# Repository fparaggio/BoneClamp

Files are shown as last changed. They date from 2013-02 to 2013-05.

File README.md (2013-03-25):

-------------------------------------------------------------------------

This file is part of the BoneClamp Data Conversion and Processing System
Copyright (C) 2013 BoneClamp

-------------------------------------------------------------------------

# BoneClamp
BoneClamp is an effort to create a fully programable, real-time, low-cost, data conversion and processing system for the 
[BeagleBone] (http://beagleboard.org/bone).

# More information
[BoneClamp Wiki] (https://potterlab.gatech.edu/main/newman/wiki/index.php?title=BoneClamp)

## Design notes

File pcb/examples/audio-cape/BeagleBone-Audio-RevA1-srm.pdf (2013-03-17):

BeagleBone Audio Cape | System Reference Manual | Revision A1

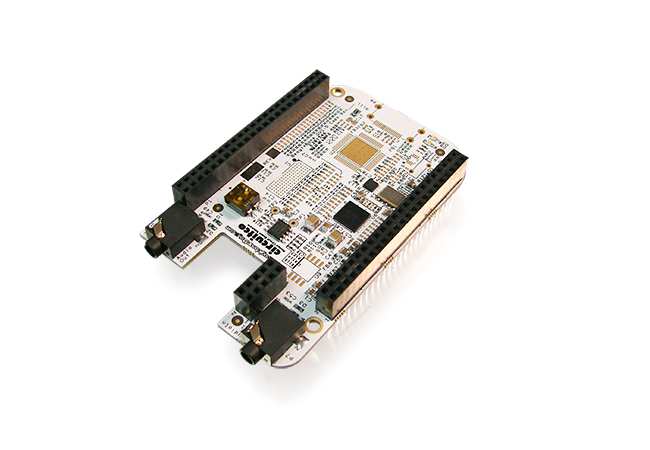
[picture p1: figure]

Page 1 of 24

## BeagleBone Audio Cape Rev A1 System Reference Manual

Revision A1
October 1st, 2012

Page 2 of 24

THIS DOCUMENT

This work is licensed under the Creative Commons Attribution-Share Alike 3.0 Unported License. To view a copy of this license, visit http://creativecommons.org/licenses/by-sa/3.0/ or send a letter to Creative Commons, 171 Second Street, Suite 300, San Francisco, California, 94105, USA.

All derivative works are to be attributed to BeagleBoardtoys.com.

For more information, see http://creativecommons.org/license/results-one?license_code=by-sa

For any questions, concerns, or issues submit them to support@beagleboardtoys.com

## BEAGLEBONE AUDIO CAPE DESIGN

## These design materials referred to in this document are *NOT SUPPORTED* and DO NOT constitute a reference design. Only “community” support is allowed via resources at Beagleboardtoys.com/support

## THERE IS NO WARRANTY FOR THE DESIGN MATERIALS, TO THE EXTENT PERMITTED BY APPLICABLE LAW. EXCEPT WHEN OTHERWISE STATED IN WRITING THE COPYRIGHT HOLDERS AND/OR OTHER PARTIES PROVIDE THE DESIGN MATERIALS “AS IS” WITHOUT WARRANTY OF

ANY KIND, EITHER EXPRESSED OR IMPLIED,

## INCLUDING, BUT NOT LIMITED TO, THE IMPLIED

WARRANTIES | OF | MERCHANTABILITY | AND

Page 3 of 24

## FITNESS FOR A PARTICULAR PURPOSE. THE ENTIRE RISK AS TO THE QUALITY AND PERFORMANCE OF THE DESIGN MATERIALS IS WITH YOU. SHOULD THE DESIGN MATERIALS PROVE DEFECTIVE, YOU ASSUME THE COST OF

ALL | NECESSARY | SERVICING, | REPAIR | OR
CORRECTION.

## We mean it; these design materials may be totally

unsuitable for any purposes.

Page 4 of 24

BeagleBoardToys provides the enclosed product(s) under the following conditions:

This evaluation board/kit is intended for use for ENGINEERING DEVELOPMENT, DEMONSTRATION, OR EVALUATION PURPOSES ONLY and is not considered by BeagleBoardtoys.com to be a finished end-product fit for general consumer use. Persons handling the product(s) must have electronics training and observe good engineering practice standards. As such, the goods being provided are not intended to be complete in terms of required design-, marketing-, and/or manufacturing-related protective considerations, including product safety and environmental measures typically found in end products that incorporate such semiconductor components or circuit boards. This evaluation board/kit does not fall within the scope of the European Union directives regarding electromagnetic compatibility, restricted substances (RoHS), recycling (WEEE), FCC, CE or UL, and therefore may not meet the technical requirements of these directives or other related directives.

Should this evaluation board/kit not meet the specifications indicated in the User’s Guide, the board/kit may be returned within 30 days from the date of delivery for a full refund. THE FOREGOING WARRANTY IS THE EXCLUSIVE WARRANTY MADE BY SELLER TO BUYER AND IS IN LIEU OF ALL OTHER WARRANTIES, EXPRESSED, IMPLIED, OR STATUTORY, INCLUDING ANY WARRANTY OF MERCHANTABILITY OR FITNESS FOR ANY PARTICULAR PURPOSE.

The user assumes all responsibility and liability for proper and safe handling of the goods. Further, the user indemnifies BeagleBoardtoys.com from all claims arising from the handling or use of the goods. Due to the open construction of the product, it is the user’s responsibility to take any and all appropriate precautions with regard to electrostatic discharge.

EXCEPT TO THE EXTENT OF THE INDEMNITY SET FORTH ABOVE, NEITHER PARTY SHALL BE LIABLE TO THE OTHER FOR ANY INDIRECT, SPECIAL, INCIDENTAL, OR CONSEQUENTIAL DAMAGES.

BeagleBoardtoys.com currently deals with a variety of customers for products, and therefore our arrangement with the user is not exclusive. BeagleBoardtoys.com assumes no liability for applications assistance, customer product design, software performance, or infringement of patents or services described herein.

Please read the User’s Guide and, specifically, the Warnings and Restrictions notice in the User’s Guide prior to handling the product. This notice contains important safety information about temperatures and voltages. For additional information on BeagleBoardtoys.com environmental and/or safety programs, please contact visit BeagleBoardtoys.com.

No license is granted under any patent right or other intellectual property right of BeagleBoard.org covering or relating to any machine, process, or combination in which such BeagleBoardtoys.com products or services might be or are used.

Mailing Address:

Beagleboardtoys.com
1380 Presidential Dr. #100 Richardson, TX 75081
U.S.A.

Page 5 of 24

WARRANTY: The BeagleBone Audio is warranted against defects in materials and workmanship for a period of 90 days from purchase. This warranty does not cover any problems occurring as a result of improper use, modifications, exposure to water, excessive voltages, abuse, or accidents. All boards will be returned via standard mail if an issue is found. If no issue is found or express return is needed, the customer will pay all shipping costs.

Before returning the board, please visit Beagleboardtoys.com/support

To return a defective board, please request an RMA at http://www.beagleboardtoys.com/support/rma

Page 6 of 24

## Table of Contents

Page 7 of 24

## Figures

Figure 1. | The BeagleBone Audio Cape | 11
Figure 2. | Major Components | 14
Figure 3. | BeagleBone Audio Cape High Level Block Diagram | 16
Figure 4. | The Record Path of TLV320AIC3106 | 17
Figure 5. | The Playback Path of TLV320AIC3106 | 18
Figure 6. | Audio Serial Bus Interface | 19
Figure 7. | BeagleBone Audio Cape EEPROM | 20
Figure 8. | User LED’s | 21
Figure 9. | BeagleBone Audio Cape Dimensions Drawing | 23

## Tables

Table 1. | Change History | 10
Table 2. | BeagleBone Audio Cape Features | 13
Table 3. | User LED Control | 22

Page 8 of 24

NOTES

Page 9 of 24

### 1.0 Introduction

This document is the System Reference Manual for the BeagleBone Audio Cape, an add-on board for the BeagleBone.

This document provides detailed information on the overall design and usage of the BeagleBone Audio Cape from the system level perspective. It is not intended to provide detailed documentation of any other component used on the board. It is expected that the user will refer to the appropriate documents for these devices to access detailed information. It will provide information on how to interact with these components from an interface perspective. The perspective will be general in nature and not specific to any one board.

The key sections in this document are:

Section 2.0 – Change History
Provides tracking for the changes made to the System Reference Manual.

Section 3.0 – Overview
This is a high level overview of the BeagleBone Audio Cape.

Section 4.0 – Features and Specification
Provided here are the features and specifications of the board.

Section 5.0 – System Architecture and Design
This section provides information on the overall architecture and design of the BeagleBone Audio Cape. This is a very detailed section that goes into the design of each circuit on the board.

Section 6.0 – Mechanical
Information is provided here on the dimensions of the BeagleBone Audio Cape.

Section 7.0 – Design Materials
This section provides information on where to get the design files.

Page 10 of 24

### 2.0 Change History

### 2.1 Change History

Table 1 tracks the changes made for each revision of this document.

Table 1. | Change History
Rev | Changes | Date | By
A | Initial release. | 08/20/2011 | BBT
A1 | 1. Add Rev A vs. A1 section (2.2) | 10/01/2012 | BBT

### 2.2 Rev A vs. A1

The only changes in this revision are PCB silkscreens to accommodate the release of Audio Cape and DVI-D with Audio Cape. No design changes have been made for the BeagleBone Audio revision A1.

The PCB revision is also changed from BB-BONE-DVID-PCB-03 to BB-BONE-DVID-PCB -04.

Page 11 of 24

### 3.0 BeagleBone Audio Cape Overview

### 3.1 Descriptions

The BeagleBone Audio Cape provides stereo audio input and output for the BeagleBone by using the TLV320AIC3106 codec. Audio data is sampled at up to 96 kHz during recording or playback. The codec interfaces with the Multichannel Audio Serial Port of the AM335x via audio serial bus. The BeagleBone Audio Cape also features two standard 3.5mm audio jacks as audio input and output connectors.

Figure 1 below is a picture of the board.

Figure 1. The BeagleBone Audio Cape

### 3.2 Box Content

The final packaged BeagleBone Audio Cape Rev A1 product will contain the following items:
- 1 BeagleBone Audio Cape

Page 12 of 24

### 3.3 Getting Started

The BeagleBone Audio Cape should work right out of the box with latest Angstrom image for BeagleBone. Following the instructions below to verify the board is working:

1. Mount the BeagleBone Audio Cape on top of BeagleBone.
- Note: The Ethernet connector on BeagleBone should fit right into the cutback on BeagleBone Audio.
2. Make sure the micro SD card using with BeagleBone has latest Angstrom image.
3. Connect the audio input jack of speakers to the audio output connector on the BeagleBone Audio.
4. Connect the audio output from PC to the audio input connector on the BeagleBone Audio using a 3.5mm male to male audio cable.
5. Open a media player on PC and play an audio file repeatedly.
6. Connect the BeagleBone to PC using a USB cable. Remember the port number of this connection.
- Note: In Windows, the serial port number can be viewed under “Ports (COM & LPT)” section inside “Device Manager”. To open the “Device Manager” windows, right-click “My Computer”, choose “Properties”, select the “Hardware” tab, and click “Device Manager”.
7. Open a terminal application (Teraterm, Hyperterminal, etc) and open new connection with following settings: baud rate - 115200, data – 8 bit, parity – none, stop – 1 bit, flow control – none. Select the port corresponding to the USB connection. Log in as root.
8. Change the ALSA mixer settings by running the command "alsamixer.
9. Start the audio test script by running the command "testaudio".
10. The script will test the audio playback by playing a beep sound to speakers.
11. The script will record 1 second of the currently playing audio file on PC and play it back to speakers.

### 3.4 Repairs

If you feel the board is in need of repair, follow the RMA Request process found at http://www.beagleboardtoys.com/support/rma

# Do not send the board in for repair until a RMA

authorization has been provided.

Do not return the board to the distributor unless you want to get a refund. You must get authorization from the distributor before returning the board

Page 13 of 24

### 4.0 Features and Specifications

This section covers the specifications of the BeagleBone Audio Cape and provides a high level description of the major components and interfaces that make up the board.

Table 2 provides a list of the BeagleBone Audio Cape’s features.

Table 2. | BeagleBone Audio Cape Features
| Feature
Power Supply | 3.3V via expansion
5V via expansion
Audio Connector | 3.5mm standard stereo jack
Indicator | Two user LEDs
EEPROM | Board ID EEPROM
Expansion Connector | 46-position stackable connector
10-position stackable connector

### 4.1 Key Component Locations

Figure 2 shows the location of the key components on the board.

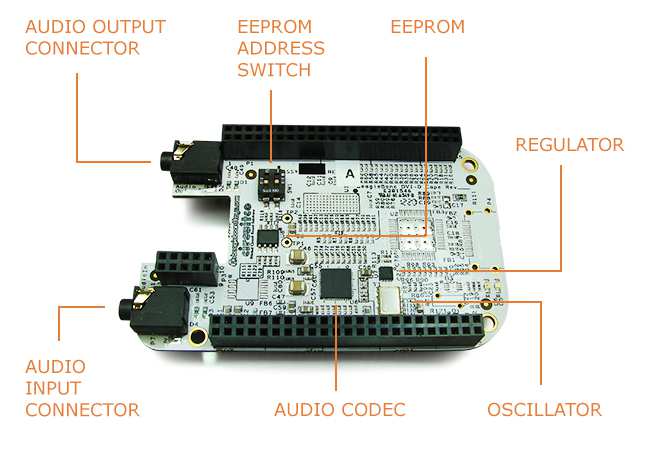
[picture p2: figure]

Page 14 of 24

Figure 2. Major Components

### 4.2 Audio Codec

The BeagleBone Audio Cape uses the TLV320AIC3106 codec for audio record and playback. Audio data is transferred between the codec and AM335x via the audio serial interface. The TLV320AIC3106 supports ADC and DAC sampling rates of up to 96 kHz.

### 4.3 Stereo Audio Ports

Two 3.5mm standard audio jacks are used for audio input port and output port. Audio input port is used for recording; audio output port is used for playback.

### 4.4 Indicators

There are two user LED’s on the board. Both are green when lit and can be controlled via software by setting the GPIO ports.

Page 15 of 24

### 4.5 Expansion Connectors

There are three stackable expansion connectors on the BeagleBone Audio Cape. These connectors are used to stack the Audio Cape on the BeagleBone. Two 46-position connectors will stack on top of the expansion connectors of BeagleBone. The 10-position connector will stack on top of the backlight expansion connector of BeagleBone.

### 4.6 Mechanical Specifications

Size: | 2.15” x 3.40”
Layers: | 4
PCB thickness: | .062”
RoHS Compliant: | Yes
Weight: | TBW

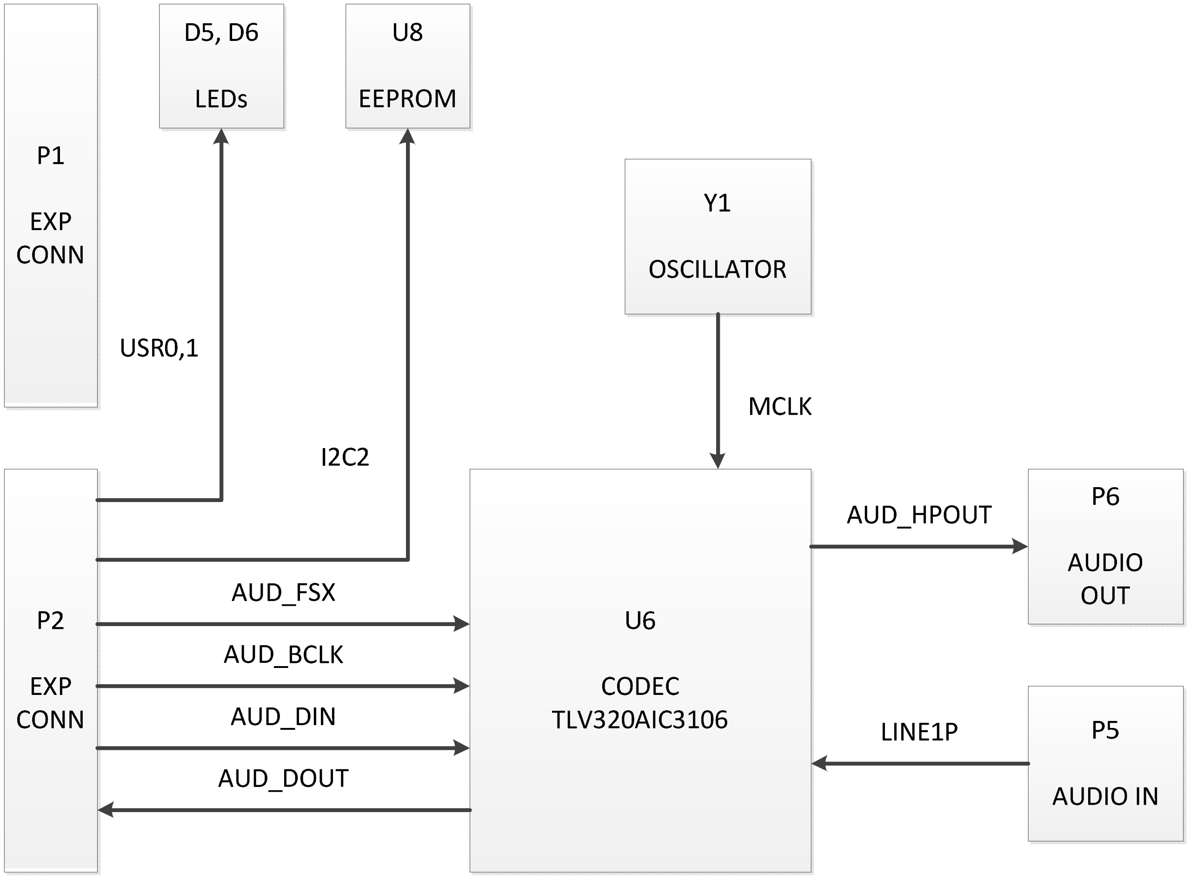
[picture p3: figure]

Page 16 of 24

### 5.0 BeagleBone Audio Cape System Architecture and Design

This section provides a high level description of the design of the BeagleBone Audio Cape and its overall architecture.

### 5.1 System Block Diagram

Figure 3 is the high level block diagram of the BeagleBone Audio Cape.

Figure 3. BeagleBone Audio Cape High Level Block Diagram

### 5.2 Power Supply

The VDD_3V3 power rail from the BeagleBone is used to power the analog and I/O voltage supplies for the codec. The TLV320AIC3106 codec also requires a digital core voltage supply of 1.8V. This supply is provided by a low-dropout (LDO) regulator TPS73701.

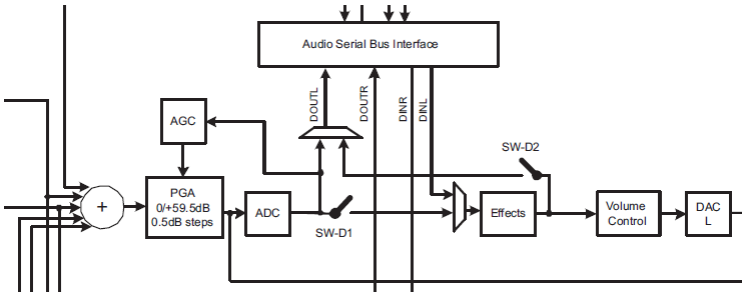
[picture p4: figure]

Page 17 of 24

### 5.3 Audio Interface

### 5.3.1 Record Path

The TLV320AIC3106 codec can be figured to record from up to four differential pairs or six single-ended audio inputs; however, the BeagleBone Audio Cape only supports two single-ended audio inputs. Each input is passed through a programmable gain amplifier (PGA), which allows gain control from 0 dB to +59.5 dB in steps of 0.5 dB, before sampled by the ADC. The ADC can sample up to 96 kHz in dual-rate mode. An automatic gain control (AGC) is provided to maintain nominally constant output signal amplitude. Figure 4 shows the record path of TLV320AIC3106.

Figure 4. The Record Path of TLV320AIC3106

The codec also supports digital audio processing for the record path if no audio playback is selected. In this mode the signal processing blocks of the playback path can be used to provide different filters for the record path.

### 5.3.2 Playback Path

The playback audio signals of each channel are filtered through digital audio processing blocks and a digital volume control before sampled by the DAC. The volume control block is programmable and can provide a digital gain from 0 dB to -63.5 dB in 0.5-dB steps. The DAC of the codec supports sampling rates of up to 96 kHz. The TLV320AIC3106 codec supports up to three differential output drivers and four high power single-ended output signals; however, the board design limits to only two single-ended output signals. The output stage of the codec provides the capability to mix/mux

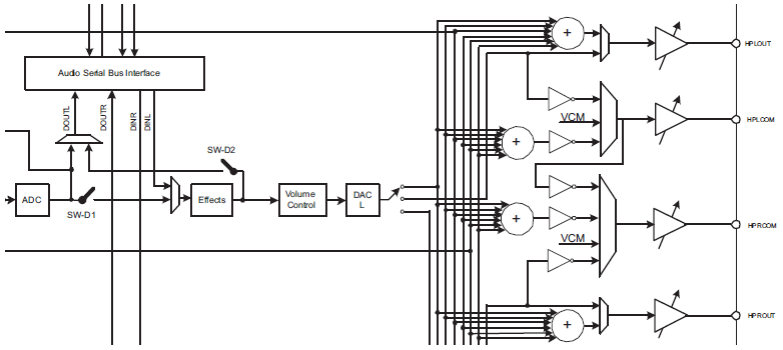
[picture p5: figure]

Page 18 of 24

between DAC and bypass PGA outputs as well as an output level control for each output channel. If no mixings are required, an output playback signals with highest DAC quality can be provided by using a direct connection for DAC outputs. The analog volume control allows gain adjustment up to +9 dB. Figure 5 shows the playback path of TLV320AIC3106.

Figure 5. The Playback Path of TLV320AIC3106

### 5.3.3 Audio Serial Bus Interface

Audio data is transferred between the TLV320AIC3106 and the Multichannel Audio Serial Port (McASP0) of the AM335x via the audio serial bus interface. This interface can be configured to support different modes of operation including the Inter-Integrated sound (I2S) protocols or time-division multiplexed (TDM) stream. Each data frame is synchronized by the transmit frame sync signal (AUD_FSX) from the McASP. This signal is connected to the word clock pin (WCLK), which is used to define the start of a frame. The digital audio data transfer is clocked by a bit clock (BCLK) received from the AM335x. Data is transmitted or received by the McASP serializers. Figure 6 shows the Audio Serial Bus Interface between the codec and the microprocessor.

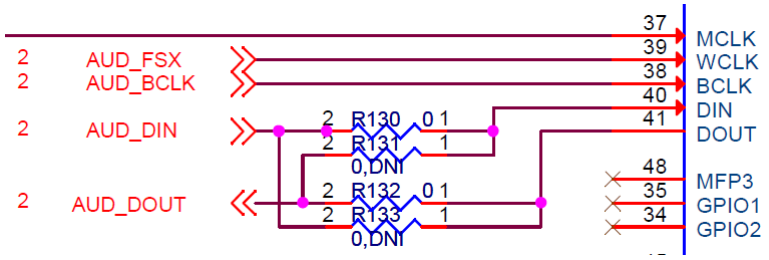
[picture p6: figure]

Page 19 of 24

Figure 6. Audio Serial Bus Interface

### 5.3.4 TLV320AIC3106 Codec

The TLV320AIC3106 codec requires a hardware reset after power-up in order to respond properly to register changes in values. Its reset signal is active low and tied to the system reset signal SYS_RESETn. The TLV320AIC3106 on the BeagleBone Audio Cape is digitally controlled via I2C serial interface. This I2C protocol supports both standard and fast modes and has a 7-bit address of 0011011. An external oscillator is used to provide a 12MHz clock signal to the master clock input (MCLK) of the codec.

### 5.4 EEPROM

The BeagleBone Audio Cape has an EEPROM containing information that will allow the SW to identify the board and to configure the expansion headers pins as needed.
EEPROMs are required for all Capes sold in order for them to operate correctly when plugged in the BeagleBone.

The EEPROM used on this cape is the same one as is used on the BeagleBone, a CAT24C256. The CAT24C256 is a 256 kb Serial CMOS EEPROM, internally organized as 32,768 words of 8 bits each. It features a 64-byte page write buffer and supports the Standard (100 kHz), Fast (400 kHz) and Fast-Plus (1 MHz) I2C protocol. Figure 7 is the design of the EEPROM circuit.

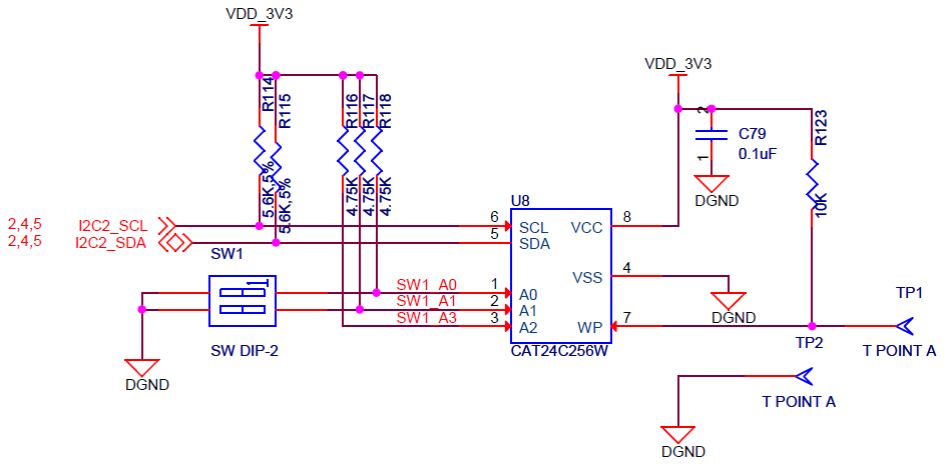
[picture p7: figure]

Page 20 of 24

Figure 7. BeagleBone Audio Cape EEPROM

### 5.4.1 EEPROM Address

In order for each Cape to have a unique address, a board ID scheme is used that sets the address to be different depending on the order in which it is stacked onto the main board. A two position dipswitch or jumpers is used to set the address pins of the EEPROM. It is the responsibility of user to set the proper address for each board. Address line A2 is always tied high. This sets the allowable address range for the expansion cards to 0x54 to 0x57.All other I2C addresses can be used by the user in the design of their Capes. But, these addresses must not be used other than for the board EEPROM information.

### 5.4.2 I2C Bus

The EEPROMs on each expansion board is connected to I2C2. For this reason I2C2 must always be left connected and should not be changed by SW to remove it from the expansion header pin mux. The I2C signals require pull-up resistors. Each board must have a 5.6K resistor on these signals. With four resistors this will be an affective resistance of 1.4K if all Capes were installed.

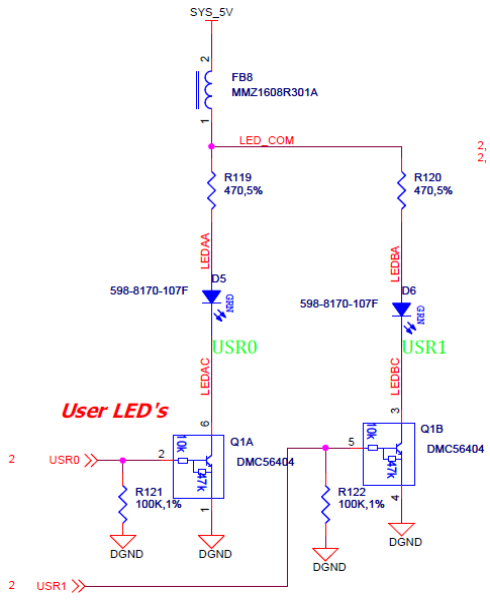
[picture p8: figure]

Page 21 of 24

### 5.5 User LED’s

The BeagleBone Audio Cape features two user LED’s which are same as D2 and D3 on the BeagleBone boards. These two LED’s can be access via GPIO pins on the processor. Figure 8 shows the LED circuitry.

Figure 8. User LED’s

Q1 provides level shifting from the processor to drive the LED’s that are connected to SYS_5V rail. FB8 provides noise immunity to the system by the LED’s which can be a

Page 22 of 24

source of noise back into the system rail. Each LED is controlled by settings the appropriate GPIO bit HI. At power up all LED’s are off. Table 3 is the GPIO User LED assignments.

Table 3. | User LED Control
LED | GPIO
User 0 | GPIO1_21
User 1 | GPIO1_22

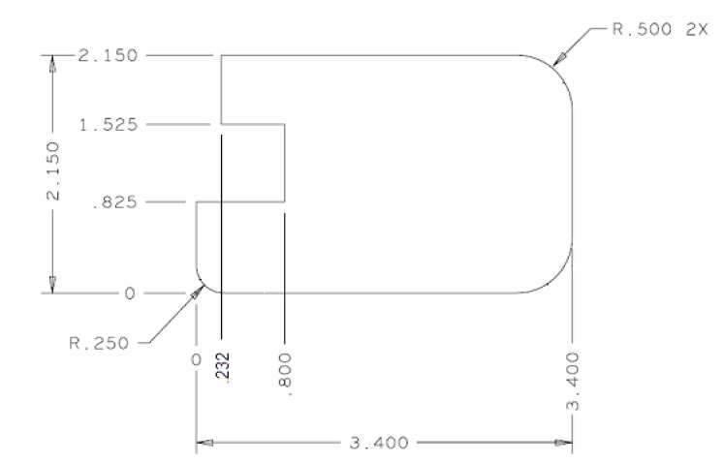
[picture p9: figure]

Page 23 of 24

### 6.0 Mechanical Information

### 6.1 BeagleBone Audio Cape Dimensions

This section provides information on the mechanical aspect of the BeagleBone Audio Cape. Figure 9 is the dimensions of the BeagleBone Audio Cape.

Figure 9. BeagleBone Audio Cape Dimensions Drawing

Page 24 of 24

### 7.0 Design Materials

Design information can be found at BeagleBoardToys wiki: http://beagleboardtoys.com/wiki/index.php?title=BeagleBone_Audio

Provided there is:
- Schematic in PDF
- Schematic in OrCAD
- Manufacturing files
- PCB Gerber
- PCB Layout (Allegro)
- Bill of Materials
- System Reference Manual (This document)

These design materials are *NOT SUPPORTED* and DO NOT constitute a reference design. Only “community” support is allowed via resources at BeagleBoard.org/discuss. THERE IS NO WARRANTY FOR THE DESIGN MATERIALS, TO THE EXTENT PERMITTED BY APPLICABLE LAW. EXCEPT WHEN OTHERWISE STATED IN WRITING THE COPYRIGHT HOLDERS AND/OR OTHER PARTIES PROVIDE THE DESIGN MATERIALS “AS IS” WITHOUT WARRANTY OF ANY KIND, EITHER EXPRESSED OR IMPLIED, INCLUDING, BUT NOT LIMITED TO, THE IMPLIED WARRANTIES OF MERCHANTABILITY AND FITNESS FOR A PARTICULAR PURPOSE. THE ENTIRE RISK AS TO THE QUALITY AND PERFORMANCE OF THE DESIGN MATERIALS IS WITH YOU. SHOULD THE DESIGN MATERIALS PROVE DEFECTIVE, YOU ASSUME THE COST OF ALL NECESSARY SERVICING, REPAIR OR CORRECTION.
We mean it, these design materials may be totally unsuitable for any purposes.

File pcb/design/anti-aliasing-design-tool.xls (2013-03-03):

 |  |  |  | Anti-Aliasing Filter Tool
Enter Converter Resolution: | 16 | bits
Enter Sample Rate: | 250000 | Hz
Nyquist Frequency: | 125000 | Hz
Enter Signal Bandwidth: | 20000 | Hz
Required Attenuation: | -98.08 | dB
Number of Filter Poles: | 4
Freq Factor | Frequency | Gain | Required Attenuation
0.0009765625 | 19.53125 | 0 | -98.08
0.001953125 | 39.0625 | 0 | -98.08
0.00390625 | 78.125 | 0 | -98.08
0.0078125 | 156.25 | 0 | -98.08
0.015625 | 312.5 | 0 | -98.08
0.03125 | 625 | 0 | -98.08
0.0625 | 1250 | 0 | -98.08
0.125 | 2500 | 0 | -98.08
0.25 | 5000 | 0 | -98.08
0.5 | 10000 | 0 | -98.08
1 | 20000 | 0 | -98.08
2 | 40000 | -24 | -98.08
4 | 80000 | -48 | -98.08
8 | 160000 | -72 | -98.08
16 | 320000 | -96 | -98.08
32 | 640000 | -120 | -98.08
64 | 1280000 | -144 | -98.08
128 | 2560000 | -168 | -98.08
256 | 5120000 | -192 | -98.08
512 | 10240000 | -216 | -98.08
1024 | 20480000 | -240 | -98.08
 | 250019.5312 | 0 | -98.08
 | 250039.0625 | 0 | -98.08
 | 250078.125 | 0 | -98.08
 | 250156.25 | 0 | -98.08
 | 250312.5 | 0 | -98.08
 | 250625 | 0 | -98.08
 | 251250 | 0 | -98.08
 | 252500 | 0 | -98.08
 | 255000 | 0 | -98.08
 | 260000 | 0 | -98.08
 | 270000 | 0 | -98.08
 | 290000 | -24 | -98.08
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

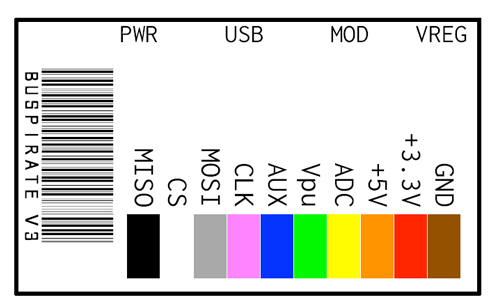
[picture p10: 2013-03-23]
pcb/proto/bus-pirate/Seed-cable.png

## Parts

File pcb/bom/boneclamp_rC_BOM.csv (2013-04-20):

Part | Value | Device | Package | Description | MPN | DKN |  |  | Manu
ADDRESS | SWS003 | SWS003 | SMS-003 | SMD Dip Switch 3 pol. | 219-3LPST | CT2193LPST-ND
A_I/O | PINHD-2X5/90 | PINHD-2X5/90 | 2X05/90 | 2X5 0.1 inch male header | 68021-210HLF | 609-3410-ND
C1 | 0.1uF | C-EUC0603 | C0603 | CAPACITOR, European symbol | C1608X7R1E104K080AA | 445-1316-1-ND
C2 | 0.1uF | C-EUC0603 | C0603 | CAPACITOR, European symbol | C1608X7R1E104K080AA | 445-1316-1-ND
C3 | 0.1uF | C-EUC0603 | C0603 | CAPACITOR, European symbol | C1608X7R1E104K080AA | 445-1316-1-ND
C4 | 0.1uF | C-EUC0603 | C0603 | CAPACITOR, European symbol | C1608X7R1E104K080AA | 445-1316-1-ND
C5 | 0.1uF | C-EUC0603 | C0603 | CAPACITOR, European symbol | C1608X7R1E104K080AA | 445-1316-1-ND
C6 | 0.1uF | C-EUC0603 | C0603 | CAPACITOR, European symbol | C1608X7R1E104K080AA | 445-1316-1-ND
C7 | 0.1uF | C-EUC0603 | C0603 | CAPACITOR, European symbol | C1608X7R1E104K080AA | 445-1316-1-ND
C8 | 0.1uF | C-EUC0603 | C0603 | CAPACITOR, European symbol | C1608X7R1E104K080AA | 445-1316-1-ND
C9 | 4.7uF | C-EUC0805 | C0805 | CAPACITOR, European symbol | TMK212AB7475KG-T | 587-2990-1-ND
C10 | 4.7uF | C-EUC0805 | C0805 | CAPACITOR, European symbol | TMK212AB7475KG-T | 587-2990-1-ND
C11 | 1nF | C-EUC0603 | C0603 | CAPACITOR, European symbol | C0603C102K3RACTU | 399-7834-1-ND
C12 | 1nF | C-EUC0603 | C0603 | CAPACITOR, European symbol | C0603C102K3RACTU | 399-7834-1-ND
C13 | 1nF | C-EUC0603 | C0603 | CAPACITOR, European symbol | C0603C102K3RACTU | 399-7834-1-ND
C14 | 1nF | C-EUC0603 | C0603 | CAPACITOR, European symbol | C0603C102K3RACTU | 399-7834-1-ND
C15 | 22uF | C-EUC0603 | C0603 | CAPACITOR, European symbol | C2012X5R1A226M125AB | 445-7665-1-ND
C16 | 0.1uF | C-EUC0603 | C0603 | CAPACITOR, European symbol | C1608X7R1E104K080AA | 445-1316-1-ND
C17 | 0.1uF | C-EUC0603 | C0603 | CAPACITOR, European symbol | C1608X7R1E104K080AA | 445-1316-1-ND
C18 | 0.1uF | C-EUC0603 | C0603 | CAPACITOR, European symbol | C1608X7R1E104K080AA | 445-1316-1-ND
C19 | 0.1uF | C-EUC0603 | C0603 | CAPACITOR, European symbol | C1608X7R1E104K080AA | 445-1316-1-ND
C20 | 0.1uF | C-EUC0603 | C0603 | CAPACITOR, European symbol | C1608X7R1E104K080AA | 445-1316-1-ND
C21 | 0.1uF | C-EUC0603 | C0603 | CAPACITOR, European symbol | C1608X7R1E104K080AA | 445-1316-1-ND
C22 | 0.1uF | C-EUC0603 | C0603 | CAPACITOR, European symbol | C1608X7R1E104K080AA | 445-1316-1-ND
C23 | 0.1uF | C-EUC0603 | C0603 | CAPACITOR, European symbol | C1608X7R1E104K080AA | 445-1316-1-ND
C24 | 0.1uF | C-EUC0603 | C0603 | CAPACITOR, European symbol | C1608X7R1E104K080AA | 445-1316-1-ND
C25 |  | C-EUC0603 | C0603 | CAPACITOR, European symbol
C26 | 10uF | C-USC0805 | C0805 | CAPACITOR, American symbol | TAJP106M010RNJ | 478-3281-1-ND
C27 | 0.1uF | C-EUC0603 | C0603 | CAPACITOR, European symbol | C1608X7R1E104K080AA | 445-1316-1-ND
C28 | 0.1uF | C-EUC0603 | C0603 | CAPACITOR, European symbol | C1608X7R1E104K080AA | 445-1316-1-ND
C29 |  | C-EUC0603 | C0603 | CAPACITOR, European symbol
C30 |  | C-EUC0603 | C0603 | CAPACITOR, European symbol
C31 |  | C-EUC0603 | C0603 | CAPACITOR, European symbol
C32 | 47uF | C-USC1206 | C1206 | CAPACITOR, American symbol | T520A476M004ATE070 | 399-4714-1-ND
C33 | 47uF | C-USC1206 | C1206 | CAPACITOR, American symbol | T520A476M004ATE070 | 399-4714-1-ND
C34 | 1uF | C-EUC0603 | C0603 | CAPACITOR, European symbol | C0805C105K4RACTU | 399-1284-1-ND
C35 | 1uF | C-EUC0603 | C0603 | CAPACITOR, European symbol | C0805C105K4RACTU | 399-1284-1-ND
C36 | 1uF | C-EUC0603 | C0603 | CAPACITOR, European symbol | C0805C105K4RACTU | 399-1284-1-ND
C37 | 1uF | C-EUC0603 | C0603 | CAPACITOR, European symbol | C0805C105K4RACTU | 399-1284-1-ND
C38 | 4.7uF | C-EUC0603 | C1206 | CAPACITOR, European symbol | TR3A475K010C1400 | 718-1757-1-ND
C39 | 1uF | C-EUC0603 | C0603 | CAPACITOR, European symbol | C0805C105K4RACTU | 399-1284-1-ND
C40 | 1uF | C-EUC0603 | C0603 | CAPACITOR, European symbol | C0805C105K4RACTU | 399-1284-1-ND
C41 | 0.1uF | C-EUC0603 | C0603 | CAPACITOR, European symbol | C1608X7R1E104K080AA | 445-1316-1-ND
C42 | 0.1uF | C-EUC0603 | C0603 | CAPACITOR, European symbol | C1608X7R1E104K080AA | 445-1316-1-ND
C43 | 0.1uF | C-EUC0603 | C0603 | CAPACITOR, European symbol | C1608X7R1E104K080AA | 445-1316-1-ND
C44 | 0.1uF | C-EUC0603 | C0,603 | CAPACITOR, European symbol | C1608X7R1E104K080AA | 445-1316-1-ND
C45 | 0.1uF | C-EUC0603 | C0603 | CAPACITOR, European symbol | C1608X7R1E104K080AA | 445-1316-1-ND
EXT_PWR |  | LEDCHIPLED_0805 | CHIPLED_0805 | LED | 598-8140-107F | 350-2041-1-ND
JP1 |  | JP2E | JP2 | JUMPER | 87224-3 | A26545-ND
JP2 |  | JP2E | JP2 | JUMPER | 87224-3 | A26545-ND
JP3 |  | JP1E | JP1 | JUMPER | 87224-3 | A26545-ND
PWR |  | LEDCHIPLED_0805 | CHIPLED_0805 | LED | 598-8170-107F | 350-2044-1-ND
PWR_EXT |  | PINHD-1X3 | 1X03 | PIN HEADER | 3M9468-ND | 961103-5604-AR
R1 | 20k | R-US_R0603 | R0603 | RESISTOR, American symbol | MCT06030C2002FP500 | MCT0603-20.0K-CFCT-ND
R2 | 20k | R-US_R0603 | R0603 | RESISTOR, American symbol | MCT06030C2002FP500 | MCT0603-20.0K-CFCT-ND
R3 | 10k | R-US_R0603 | R0603 | RESISTOR, American symbol | MCT06030C1002FP500 | MCT0603-10.0K-CFCT-ND
R4 | 10k | R-US_R0603 | R0603 | RESISTOR, American symbol | MCT06030C1002FP500 | MCT0603-10.0K-CFCT-ND
R5 | 20k | R-US_R0603 | R0603 | RESISTOR, American symbol | MCT06030C2002FP500 | MCT0603-20.0K-CFCT-ND
R6 | 20k | R-US_R0603 | R0603 | RESISTOR, American symbol | MCT06030C2002FP500 | MCT0603-20.0K-CFCT-ND
R7 | 10k | R-US_R0603 | R0603 | RESISTOR, American symbol | MCT06030C1002FP500 | MCT0603-10.0K-CFCT-ND
R8 | 10k | R-US_R0603 | R0603 | RESISTOR, American symbol | MCT06030C1002FP500 | MCT0603-10.0K-CFCT-ND
R9 | 10k | R-US_R0603 | R0603 | RESISTOR, American symbol | CRCW060310K0JNEA | 541-10KGCT-ND
R10 | 20 | R-US_R0603 | R0603 | RESISTOR, American symbol | RMCF0603FT20R0 | RMCF0603FT20R0CT-ND
R11 | 20 | R-US_R0603 | R0603 | RESISTOR, American symbol | RMCF0603FT20R0 | RMCF0603FT20R0CT-ND
R12 | 20 | R-US_R0603 | R0603 | RESISTOR, American symbol | RMCF0603FT20R0 | RMCF0603FT20R0CT-ND
R13 | 20 | R-US_R0603 | R0603 | RESISTOR, American symbol | RMCF0603JT20R0 | RMCF0603JT20R0CT-ND
R14 | 10 | R-US_R0603 | R0603 | RESISTOR, American symbol | RMCF0603JT10R0 | RMCF0603JT10R0CT-ND
R15 | 10k | R-US_R0603 | R0603 | RESISTOR, American symbol | MCT06030C1002FP500 | MCT0603-10.0K-CFCT-ND
R16 | 10k | R-US_R0603 | R0603 | RESISTOR, American symbol | MCT06030C1002FP500 | MCT0603-10.0K-CFCT-ND
R17 | 10k | R-US_R0603 | R0603 | RESISTOR, American symbol | MCT06030C1002FP500 | MCT0603-10.0K-CFCT-ND
R18 | 10k | R-US_R0603 | R0603 | RESISTOR, American symbol | MCT06030C1002FP500 | MCT0603-10.0K-CFCT-ND
R19 | 10k | R-US_R0603 | R0603 | RESISTOR, American symbol | MCT06030C1002FP500 | MCT0603-10.0K-CFCT-ND
R20 | 10k | R-US_R0603 | R0603 | RESISTOR, American symbol | MCT06030C1002FP500 | MCT0603-10.0K-CFCT-ND
R21 | 10k | R-US_R0603 | R0603 | RESISTOR, American symbol | MCT06030C1002FP500 | MCT0603-10.0K-CFCT-ND
R22 | 10k | R-US_R0603 | R0603 | RESISTOR, American symbol | MCT06030C1002FP500 | MCT0603-10.0K-CFCT-ND
R23 |  | R-US_R0603 | R0603 | RESISTOR, American symbol
R24 | 10k | R-US_R0603 | R0603 | RESISTOR, American symbol | CRCW060310K0JNEA | 541-10KGCT-ND
R25 | 10k | R-US_R0603 | R0603 | RESISTOR, American symbol | CRCW060310K0JNEA | 541-10KGCT-ND
R26 |  | R-US_R0603 | R0603 | RESISTOR, American symbol
R27 |  | R-US_R0603 | R0603 | RESISTOR, American symbol
R28 |  | R-US_R0603 | R0603 | RESISTOR, American symbol
R29 | 10k | R-US_R0603 | R0603 | RESISTOR, American symbol | CRCW060310K0JNEA | 541-10KGCT-ND
R30 | 100k | R-US_R0603 | R0603 | RESISTOR, American symbol | RMCF0603JT100K | RMCF0603JT100KCT-ND
R31 | 260k | R-US_R0603 | R0603 | RESISTOR, American symbol | P261KHCT-ND | ERJ-3EKF2613V
R32 | 2k | R-US_R0603 | R0603 | RESISTOR, American symbol | RMCF0603JT2K00 | RMCF0603JT2K00CT-ND
R33 | 2k | R-US_R0603 | R0603 | RESISTOR, American symbol | RMCF0603JT2K00 | RMCF0603JT2K00CT-ND
R34 | 10k | R-US_R0603 | R0603 | RESISTOR, American symbol | CRCW060310K0JNEA | 541-10KGCT-ND
R35 | 10k | R-US_R0603 | R0603 | RESISTOR, American symbol | CRCW060310K0JNEA | 541-10KGCT-ND
R36 | 10k | TRIM_US- | M84-TRIMMER | POTENTIOMETER | 84PR10KLF | 987-1152-ND
R37 | 4.75k | R-US_R0603 | R0603 | RESISTOR, American symbol | RMCF0603FT4K75 | RMCF0603FT4K75CT-ND
R38 | 4.75k | R-US_R0603 | R0603 | RESISTOR, American symbol | RMCF0603FT4K75 | RMCF0603FT4K75CT-ND
R39 | 4.75k | R-US_R0603 | R0603 | RESISTOR, American symbol | RMCF0603FT4K75 | RMCF0603FT4K75CT-ND
R40 | 10k | R-US_R0603 | R0603 | RESISTOR, American symbol | CRCW060310K0JNEA | 541-10KGCT-ND
R41 | 5.6k | R-US_R0603 | R0603 | RESISTOR, American symbol | RMCF0603JT5K60 | RMCF0603JT5K60CT-ND
R42 | 5.6k | R-US_R0603 | R0603 | RESISTOR, American symbol | RMCF0603JT5K60 | RMCF0603JT5K60CT-ND
RESET | SPST_TACT | SPST_TACT | EVQ-Q2-A | SMT 6mm switch, EVQQ2 series | FSM4JSMA | 450-1129-ND
U1 | OPA365AIDBVR | OPA365AIDBVR | SOT95P280X145-5N | 50MHz, Low-Distortion, High CMRR RRI/O, Single-Supply OPERATIONAL AMPLIFIER | OPA365AIDBVR | 296-20645-1-ND | 03M9400 | SOT-23-5 | Texas Instruments
U2 | OPA365AIDBVR | OPA365AIDBVR | SOT95P280X145-5N | 50MHz, Low-Distortion, High CMRR RRI/O, Single-Supply OPERATIONAL AMPLIFIER | OPA365AIDBVR | 296-20645-1-ND | 03M9400 | SOT-23-5 | Texas Instruments
U3 | OPA365AIDBVR | OPA365AIDBVR | SOT95P280X145-5N | 50MHz, Low-Distortion, High CMRR RRI/O, Single-Supply OPERATIONAL AMPLIFIER | OPA365AIDBVR | 296-20645-1-ND | 03M9400 | SOT-23-5 | Texas Instruments
U4 | OPA365AIDBVR | OPA365AIDBVR | SOT95P280X145-5N | 50MHz, Low-Distortion, High CMRR RRI/O, Single-Supply OPERATIONAL AMPLIFIER | OPA365AIDBVR | 296-20645-1-ND | 03M9400 | SOT-23-5 | Texas Instruments
U5 | ADS8331IBPW | ADS8331IBPW | SOP65P640X120-24N | Low-Power, 16-Bit, 500kSPS, 4-Channel Unipolar Input ADC | ADS8331IBPW | 296-28266-5-ND | 27T6163 | TSSOP-24 | Texas Instruments
U6 | OPA365AIDBVR | OPA365AIDBVR | SOT95P280X145-5N | ANALOG-TO-DIGITAL CONVERTERS with Serial Interface | OPA365AIDBVR | 296-20645-1-ND | 03M9400 | SOT-23-5 | Texas Instruments
U7 | OPA365AIDBVR | OPA365AIDBVR | SOT95P280X145-5N | 50MHz, Low-Distortion, High CMRR RRI/O, Single-Supply OPERATIONAL AMPLIFIER | OPA365AIDBVR | 296-20645-1-ND | 03M9400 | SOT-23-5 | Texas Instruments
U8 | OPA365AIDBVR | OPA365AIDBVR | SOT95P280X145-5N | 50MHz, Low-Distortion, High CMRR RRI/O, Single-Supply OPERATIONAL AMPLIFIER | OPA365AIDBVR | 296-20645-1-ND | 03M9400 | SOT-23-5 | Texas Instruments
U9 | OPA365AIDBVR | OPA365AIDBVR | SOT95P280X145-5N | 50MHz, Low-Distortion, High CMRR RRI/O, Single-Supply OPERATIONAL AMPLIFIER | OPA365AIDBVR | 296-20645-1-ND | 03M9400 | SOT-23-5 | Texas Instruments
U10 | AD5686 | AD5686RARUZ | MO-153-AB | Quad, 16-Bit nanoDAC+ | AD5686ARUZ | AD5686ARUZ-ND
U11 | LM2663 | LM2663 | SOIC127P600X175-8N | with SPI Interface | LM2663M/NOPB | LM2663M/NOPB-ND
U12 | MAX1735EUK25+T | MAX1735EUK25+T | SOT95P280X145-5N | 200mA, Negative-Output, Low-Dropout Linear Regulator in SOT23 | MAX1735EUK25+T | MAX1735EUK25+TCT-ND | 68K9417 | SOT-23-5 | Maxim
U13 | TLV70245DBVT | TLV70025DDCR | SOT95P280X110-5N | 200-mA, Low-IQ, Low-Dropout Regulator for Portable Devices | TLV70245DBVT | 296-30480-1-ND | 64R0678 | TSOT-23-5 | Texas Instruments
U14 | REF5040MDREP | REF5040MDREP | SOIC127P600X175-8N | LOW-NOISE, VERY LOW DRIFT, PRECISION VOLTAGE REFERENCE | REF5040MDREP | 296-27431-1-ND | 79R8283 | SOIC-8 | Texas Instruments
U15 | AD8032ARZ-REEL7 | AD8032ARZ-REEL7 | SOIC127P600X175-8N | Rail-to-Rail I/O Amplifiers | AD8032ARZ | AD8032ARZ-ND | 82H2954 | SOIC-8 | Analog Devices
U16 | 24C | 24C | SO-08 | Serial EEPROM | CAT24C256WI-GT3 | CAT24C256WI-GT3OSCT-ND |  | SOIC-8

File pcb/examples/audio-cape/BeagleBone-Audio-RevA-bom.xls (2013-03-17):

BeagleBone Audio Cape |  |  | 2012-08-14
Rev A
ITM | QTY | PART DESIGNATOR | PART | DESCRIPTIONS | MAN | PART # | COMMENTS
1 | 4 | C1,C2,C3,C4 | 10uF,10V | CAP CER 10UF 10V Y5V 0805 | TDK | C2012Y5V1A106Z
3 | 2 | C46,C47 | 47uF | CAP CER 47UF 10V X5R 1210 | Murata | GRM32ER61A476KE20L
4 | 4 | C48,C49,C53,C61 | 47pF | CAP CER 47PF 50V C0G 5% 0402 | TDK | C1005C0G1H470J
5 | 9 | C50,C51,C52,C54,C57,C60,C63,C78,C79 | 0.1uF | CAP 0.1uF 16V 10% 0402 X7R | Kemet | C0402C104K4RACT
6 | 5 | C55,C56,C58,C59,C62 | 10uF,0805 | CAP CER 10UF 10V Y5V 0805 | TDK | C2012Y5V1A106Z
8 | 4 | D1,D2,D3,D4 | PGB0010603MR | Ferrite Bead 150 Ohm 800mA | Steward | LI0805H151R-10
9 | 2 | D5,D6 | 598-8170-107F | LED Green SMD 20mA 2V 0805 | Dialight | 598-8170-107F
10 | 3 | FB6,FB7,FB8 | MMZ1608R301A | FERRITE CHIP 300 OHM 500MA 0603 | TDK | MMZ1608R301A
11 | 2 | P1,P2 | 2x23 HEADER FEMALE | .100 CL Dual Row- Straight Socket Strip- using .025" Sq. Pins | MLE | SSHQ-123-D-08-G-LF
 |  |  | 2x23 HEADER FEMALE | .100 CL Dual Row- Straight Socket Strip- using .025" Sq. Pins | MLE | SSHQ-123-D-08-F-LF
12 | 1 | P3 | 2x5 HEADER FEMALE | .100 CL Dual Row- Straight Socket Strip- using .025" Sq. Pins | MLE | SSHQ-105-D-08-G-LF
 |  |  | 2x5 HEADER FEMALE | .100 CL Dual Row- Straight Socket Strip- using .025" Sq. Pins | MLE | SSHQ-105-D-08-F-LF
13 | 2 | P6,P7 | PHONOJACK STEREO-R | CONN JACK STEREO 3POS 3.5MM SMD | CUI | SJ1-3513-SMT
14 | 1 | Q1 | DMC56404 | TRANS NPN/NPN W/RES 50V SMINI6 | Panasonic | DMC564040R
16 | 3 | R108,R109,R110 | 33402 | RES 33.0 OHM 1/16W 1% 0402 SMD | Yaego | RC0805FR-0749R9L
17 | 1 | R111 | .1,0805 | RES .10 OHM 1/8W 5% 0805 | CTS | 73L3R10J
18 | 1 | R112 | 28K | RES 28.0K OHM 1/16W 1% 0402 SMD | Yaego | RC0402FR-0728KL
19 | 1 | R113 | 56.2K | RES 56.2K OHM 1/16W 1% 0402 SMD | Yaego | CRCW040256K2FKED
20 | 2 | R114,R115 | 5.6K | RES 5.6K OHM 1/16W 5% 0402 SMD | Yaego | RC0402JR-075K6L
21 | 3 | R116,R117,R118 | 4.75K | RES 4.75K OHM 1/16W 1% 0402 SMD | Stackpole Electronics | RMCF0402FT4K75
22 | 2 | R119,R120 | 470,5% | RES 470 OHM 1/10W 5% 0402 SMD | Panasonic | ERJ-2GEJ471X
23 | 2 | R121,R122 | 100K,1% | Resistor 100Kohm 1/16W 1% 0402 | Yageo | CRCW0402100KJNED
24 | 1 | R123 | 10K | Resistor 10Kohm 1/16W 5% 0402 | Rohm | MCR01MZPJ103
25 | 2 | R130,R132 | 402 | Resistor Zero ohm Jumper 0402 | Yaego | RC0402JR-070RL
27 | 1 | SW1 | 2 POS Dip Switch | SWITCH TAPE SEAL 2 POS SMD | CTS | 219-2MST
29 | 1 | U6 | TLV320AIC3106 | IC STER AUD CODEC 32 BIT 48-VQFN | TI | TLV320AIC3106IRGZR
30 | 1 | U7 | TPS73701DRBR | IC REG LDO CAP FREE 8-SON | TI | TPS73701DRBR
31 | 1 | U8 | CAT24C256W | IC EEPROM 256KBIT 400KHZ 8SOIC | ON | CAT24C256WI-G
33 | 1 | Y1 | 12MHz | OSCILLATOR 12.000 MHZ 3.3V SMD | Fox | FXO-HC735-12
 | DNI | C5,C6,C67,C68,C69,C70,C71,C72,C73,C74,C75, C76,C77,C80,C81,R1,131,R133,U9

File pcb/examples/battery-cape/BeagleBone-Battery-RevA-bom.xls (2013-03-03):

BeagleBone BATTERY Cape
BB-BONE-BATT-01 Rev A
ITM | QTY | REF DESIGNATIORS | PART | PCB Footprint | DESCRIPTION | MAN | PART # | COMMENT
1 | 2 | C1,C3 | 10uF,10V | 805 | CAP CER 10UF 10V Y5V 0805 | TDK | C2012Y5V1A106Z
2 | 1 | C2 | 47uF, 10V | 3216 | CAP CER 47UF 6.3V 20% X5R 1206 |  | GRM31CR60J476ME19L
3 | 1 | C4 | 0.1uF | 402 | Capacitor 0.1uF 16V 10% 0402 X7R | Kemet | C0402C104K4RACT
4 | 1 | D1 | PMEG1020EJ | SOD-323F | SCHOTTKY RECT 10V 2A SOD323F | NXP | PMEG1020EJ,115
5 | 1 | D2 | LTST-C190GKT | led2-31sq | LED GREEN CLEAR 0603 SMD |  | LTST-C190GKT
6 | 2 | J1,J2 | MALE HEADER 2x23 | HEADER23X2 | .100 CL Dual Row- Straight Socket Strip- using .025" Sq. Pins | MLE | SSHQ-123-D-08-F-LF |  | 2000 | mle
7 | 1 | J3 | MALE HDR5x2 | HEADER5X2 | .100 CL Dual Row- Straight Socket Strip- using .025" Sq. Pins | MLE | SSHQ-105-D-08-F-LF |  | 1000 | mle
8 | 4 | J4,J5,J6,J7 | 2460 |  | HOLDER BATTERY 1CELL AA PC MNT | Keystone | 2460
9 | 2 | J8,J9 | CON2 | SIP2
10 | 1 | L1 | 7447779006 | IND237SMD_287SQ | INDUCTOR POWER 6.8UH 2.91A SMD |  | 7447779006
11 | 1 | R1 | 200K | 402 | Resistor 200Kohm 1/16W 1% 0402 | Vishay | CRCW0402200KFKED
12 | 1 | R2 | 100K | 402 | Resistor 100Kohm 1/16W 1% 0402 | Vishay | CRCW0402100KFKED
13 | 1 | R4 | 1.74M | 402 | RES 1.74M OHM 1/16W 1% 0402 SMD | Vishay | CRCW04021M74FKED
14 | 1 | R9 | 180K | 402 | RES 180K OHM 1/10W 1% 0402 SMD |  | ERJ-2RKF1803X
15 | 0 | R5 | 2M (DNI) | 402 | RES 2.00M OHM 1/16W 1% 0402 SMD | Vishay | CRCW04022M00FKED
16 | 2 | R6,R17 | 10K | 402 | Resistor 10Kohm 1/16W 5% 0402 | Rohm | MCR01MZPJ103
17 | 0 | R7 | 1M (DNI) | 402 | RES 1.00M OHM 1/16W 1% 0402 SMD | Vishay | CRCW04021M00FKED
18 | 1 | R8 | 0R | 402 | Resistor Zero ohm Jumper 0402 | Yageo | RC0402JR-070RL
19 | 1 | R10 | 510 | r402-25 | RES 510 OHM 1/16W 1% 0402 SMD | Yaego | RC0402FR-07510RL
20 | 2 | R12,R13 | 5.6K,5% | 402 | RES 5.6K OHM 1/16W 5% 0402 SMD | Yaego | RC0402JR-075K6L
21 | 3 | R14,R15,R16 | 4.75K | 402 | RES 4.75K OHM 1/16W 1% 0402 SMD | Stackpole Electronics | RMCF0402FT4K75
22 | 1 | SW1 | SW DIP-2 | swdip4_100-339smd | SWITCH TAPE SEAL 2 POS SMD | CTS | 219-2MST
23 | 1 | S6 | B3F-3100 | sw4-b3f-315x | SWITCH TACTILE SPST-NO 0.05A 24V, RA | Omron | B3F-3100
24 | 1 | U1 | TPS61032RSA | QFN16_RSA | IC BOOST SYNC ADJ 3.6A 16VQFN |  | TPS61030RSA
25 | 1 | U2 | CAT24C256W | SOIC_8 | IC EEPROM 256KBIT 400KHZ 8SOIC | ON | CAT24C256WI-G
26 | 1 | PCB |  |  |  |  | BB-BONE-BATT-PCB-01

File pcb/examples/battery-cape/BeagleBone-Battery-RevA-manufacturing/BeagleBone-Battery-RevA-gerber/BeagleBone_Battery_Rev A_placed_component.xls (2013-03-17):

REFDES | COMP_DEVICE_TYPE | COMP_VALUE | COMP_TOL | SYM_NAME | SYM_X | SYM_Y | SYM_ROTATE | SYM_MIRROR
C1 | CAP_10UF_Y5V_10V_10%_0805_805_1 | 10uF,10V |  | 805 | 2280.00 | 1055.00 | 90.000 | NO
C2 | CAPACITOR POL_3216_47UF, 10V | 47uF, 10V |  | 3216 | 2380.00 | 1045.00 | 270.000 | NO
C3 | CAP_10UF_Y5V_10V_10%_0805_805_1 | 10uF,10V |  | 805 | 2037.50 | 1687.50 | 180.000 | NO
C4 | CAP,0.1UF_402_0.1UF | 0.1uF |  | 402 | 1250.00 | 850.00 | 90.000 | NO
D1 | DIODE SCHOTTKY_0_SOD-323F_PMEG1 | PMEG1020EJ |  | SOD-323F | 2495.00 | 1050.00 | 270.000 | NO
D2 | LED_LTST-C150GKT_LED2-31SQ_DISC | LTST-C190GKT |  | LED2-31SQ | 100.00 | 425.00 | 0.000 | NO
J1 | HDR_46_F_2_0.1_0.1_HEADER23X2_M | MALE HEADER 2x23 |  | HEADER23X2 | 775.00 | 1975.00 | 0.000 | NO
J2 | HDR_46_F_2_0.1_0.1_HEADER23X2_M | MALE HEADER 2x23 |  | HEADER23X2 | 775.00 | 75.00 | 0.000 | NO
J3 | HDR_10_F_2_0.1_HEADER5X2_MALE H | MALE HDR5x2 |  | HEADER5X2 | 275.00 | 650.00 | 90.000 | NO
J4 | CON2_SIP2_BH2AA-PC | BH2AA-PC |  | SIP2 | 1550.00 | 2500.00 | 180.000 | NO
J5 | CON2_SIP2_BH2AA-PC | BH2AA-PC |  | SIP2 | 1750.00 | 2500.00 | 180.000 | YES
J6 | CON2_SIP2_BH2AA-PC | BH2AA-PC |  | SIP2 | 1550.00 | -350.00 | 180.000 | NO
J7 | CON2_SIP2_BH2AA-PC | BH2AA-PC |  | SIP2 | 1750.00 | -350.00 | 180.000 | YES
J8 | CON2_B2S_CON2 | CON2 |  | B2S | 475.00 | 2075.00 | 0.000 | NO
J9 | CON2_B2S_CON2 | CON2 |  | B2S | 475.00 | 75.00 | 180.000 | NO
L1 | INDUCTOR FERRITE/SM_IND237SMD_2 | 7447779006 |  | IND237SMD_287SQ | 2050.00 | 1462.50 | 0.000 | NO
R1 | RES_330_0402_0402_200K | 200K |  | 0402 | 2250.00 | 290.00 | 180.000 | NO
R2 | RES_330_0402_0402_100K | 100K |  | 0402 | 2345.00 | 290.00 | 180.000 | NO
R4 | RES_330_0402_0402_0, DNI | 0, DNI |  | 0402 | 2125.00 | 1002.50 | 180.000 | NO
R5 | RES_330_0402_0402_2M | 2M |  | 0402 | 1912.50 | 1200.00 | 0.000 | NO
R6 | RES_330_0402_0402_10K | 10K |  | 0402 | 1912.50 | 1100.00 | 0.000 | NO
R7 | RES_330_0402_0402_1M | 1M |  | 0402 | 1912.50 | 1050.00 | 0.000 | NO
R8 | RES_330_0402_0402_390K | 390K |  | 0402 | 1912.50 | 1150.00 | 180.000 | NO
R9 | RES_330_0402_0402_0, DNI | 0, DNI |  | 0402 | 2025.00 | 1002.50 | 180.000 | NO
R10 | RES_330_0402_R402-25_1K | 1K |  | R402-25 | 100.00 | 350.00 | 180.000 | NO
R12 | RES_470_1/10W_5%_0402_402_5.6K, | 5.6K,5% |  | 402 | 1150.00 | 850.00 | 90.000 | NO
R13 | RES_470_1/10W_5%_0402_402_5.6K, | 5.6K,5% |  | 402 | 1100.00 | 850.00 | 90.000 | NO
R14 | RES_4.7K_0402_402_4.75K | 4.75K |  | 402 | 1150.00 | 1300.00 | 270.000 | NO
R15 | RES_4.7K_0402_402_4.75K | 4.75K |  | 402 | 1200.00 | 1300.00 | 270.000 | NO
R16 | RES_4.7K_0402_402_4.75K | 4.75K |  | 402 | 1250.00 | 1300.00 | 270.000 | NO
R17 | RES_4.7K_0402_402_10K | 10K |  | 402 | 1200.00 | 850.00 | 90.000 | NO
S6 | SW_KT11P2JM_4_SW4-B3F-315X_DISC | B3F-3100 |  | SW4-B3F-315X | 125.00 | 150.00 | 0.000 | NO
SW1 | SW DIP-2_SWDIP4_100-339SMD_SW D | SW DIP-2 |  | SWDIP4_100-339SMD | 1200.00 | 1600.00 | 270.000 | NO
TP1 | T POINT A_TP1-8040_T POINT A | T POINT A |  | TP1-8040 | 1350.00 | 1037.50 | 0.000 | NO
TP2 | T POINT A_TP1-8040_T POINT A | T POINT A |  | TP1-8040 | 1350.00 | 1287.50 | 0.000 | NO
U1 | TPS61032RSA_1_QFN16_RSA_TPS6103 | TPS61032RSA |  | QFN16_RSA | 2075.00 | 1150.00 | 90.000 | NO
U2 | CAT24C256W_SOIC_8_CAT24C256W | CAT24C256W |  | SOIC_8 | 1175.00 | 1075.00 | 180.000 | NO

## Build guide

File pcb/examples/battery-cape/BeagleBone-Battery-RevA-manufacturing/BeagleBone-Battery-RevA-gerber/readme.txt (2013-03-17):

Date : 02/20/2012 

README for Gerber_BeagleBone_Battery_Cape_20Feb.zip

Files contained in the zip file:

README		      				This file
BeagleBone_Battery_Rev A_lyr1   		Layer 1
BeagleBone_Battery_Rev A_lyr2     		Layer 2
BeagleBone_Battery_Rev A_smc   			Soldermask Layer 1 Side (Component)
BeagleBone_Battery_Rev A_sms    		Soldermask Layer 2 Side (Solder)
BeagleBone_Battery_Rev A_spc    		Solder Paste Layer 1 Side 
BeagleBone_Battery_Rev A_tslk 			Silk Screen Layer 1 side
BeagleBone_Battery_Rev A_bslk 			Silk Screen Layer 2 side
BeagleBone_Battery_Rev A_fab    		Fabrication Drawing (for Ref. ONLY)
BeagleBone_Battery_Rev A_assy   		Assembly Drawing (for Ref. ONLY)
BeagleBone_Battery_Rev A.drl			Drill tape, through
BeagleBone_Battery_Rev A_nc_param.txt 	        Drill tape setup file
BeagleBone_Battery_Rev A_ncdrill.log    	Drill tape composite file (for Reference ONLY)
BeagleBone_Battery_Rev A.ipc   	  		IPC-D-356A netlist (for Checking ONLY)
BeagleBone_Battery_Rev A_art_param.txt  	Artwork Format File (for Ref. ONLY)
BeagleBone_Battery_Rev A_placed_component.xls	Placement file for Assembly (for Ref. Only)
BeagleBone_Battery_Rev A_netlist_allegro.xls 	Allegro Netlist (for Ref. Only)

Notes:	PLEASE REVIEW FAB DRAWING FOR SPECIFIC REQUIREMENTS.

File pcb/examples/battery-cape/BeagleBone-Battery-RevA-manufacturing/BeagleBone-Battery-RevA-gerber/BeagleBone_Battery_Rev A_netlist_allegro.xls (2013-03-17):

Net Name | Net Pins
AIN4 | J2.33 R1.1 R2.2
DGND | C1.1 C2.2 C3.1 C4.1 J1.1 J1.2 J2.1 J2.2 J2.43 J2.44 J2.45 J2.46 J5.2 J7.2 J8.2 J9.2 R2.1 R8.1 R9.2 R10.1 S6.2 S6.3 S6.4 SW1.1 SW1.2 TP2.1 U1.5 U1.6 U1.7 U1.10 U1.13 U1.17 U2.4
GPIO1_16 | J2.15 R7.2 U1.12
I2C2_SCL | J2.19 R12.2 U2.6
I2C2_SDA | J2.20 R13.2 U2.5
N17101594 | R4.2 R9.1 U1.14
N17101621 | C1.2 C2.1 D1.2 R4.1 U1.1 U1.15 U1.16
N17101637 | L1.2 U1.3 U1.4
N17101693 | R5.1 R8.2 U1.9
N17101809 | R6.2 U1.11
N17102365 | J4.2 J5.1
N17103656 | R17.2 TP1.1 U2.7
N17106363 | D2.1 R10.2
N17107516 | J6.2 J7.1
PWR_BUT | J2.9 S6.1
SW1_A0 | R16.2 SW1.4 U2.1
SW1_A1 | R15.2 SW1.3 U2.2
SW1_A3 | R14.2 U2.3
VBAT | C3.2 J4.1 J6.1 J8.1 J9.1 L1.1 R1.2 R5.2 R6.1 U1.8
VDD_3V3 | C4.2 J2.3 J2.4 R7.1 R12.1 R13.1 R14.1 R15.1 R16.1 R17.1 U2.8
VDD_5V | D1.1 D2.2 J2.5 J2.6

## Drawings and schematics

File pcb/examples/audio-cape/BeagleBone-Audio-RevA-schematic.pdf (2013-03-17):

# 08/14/2012 BBT

# DATE

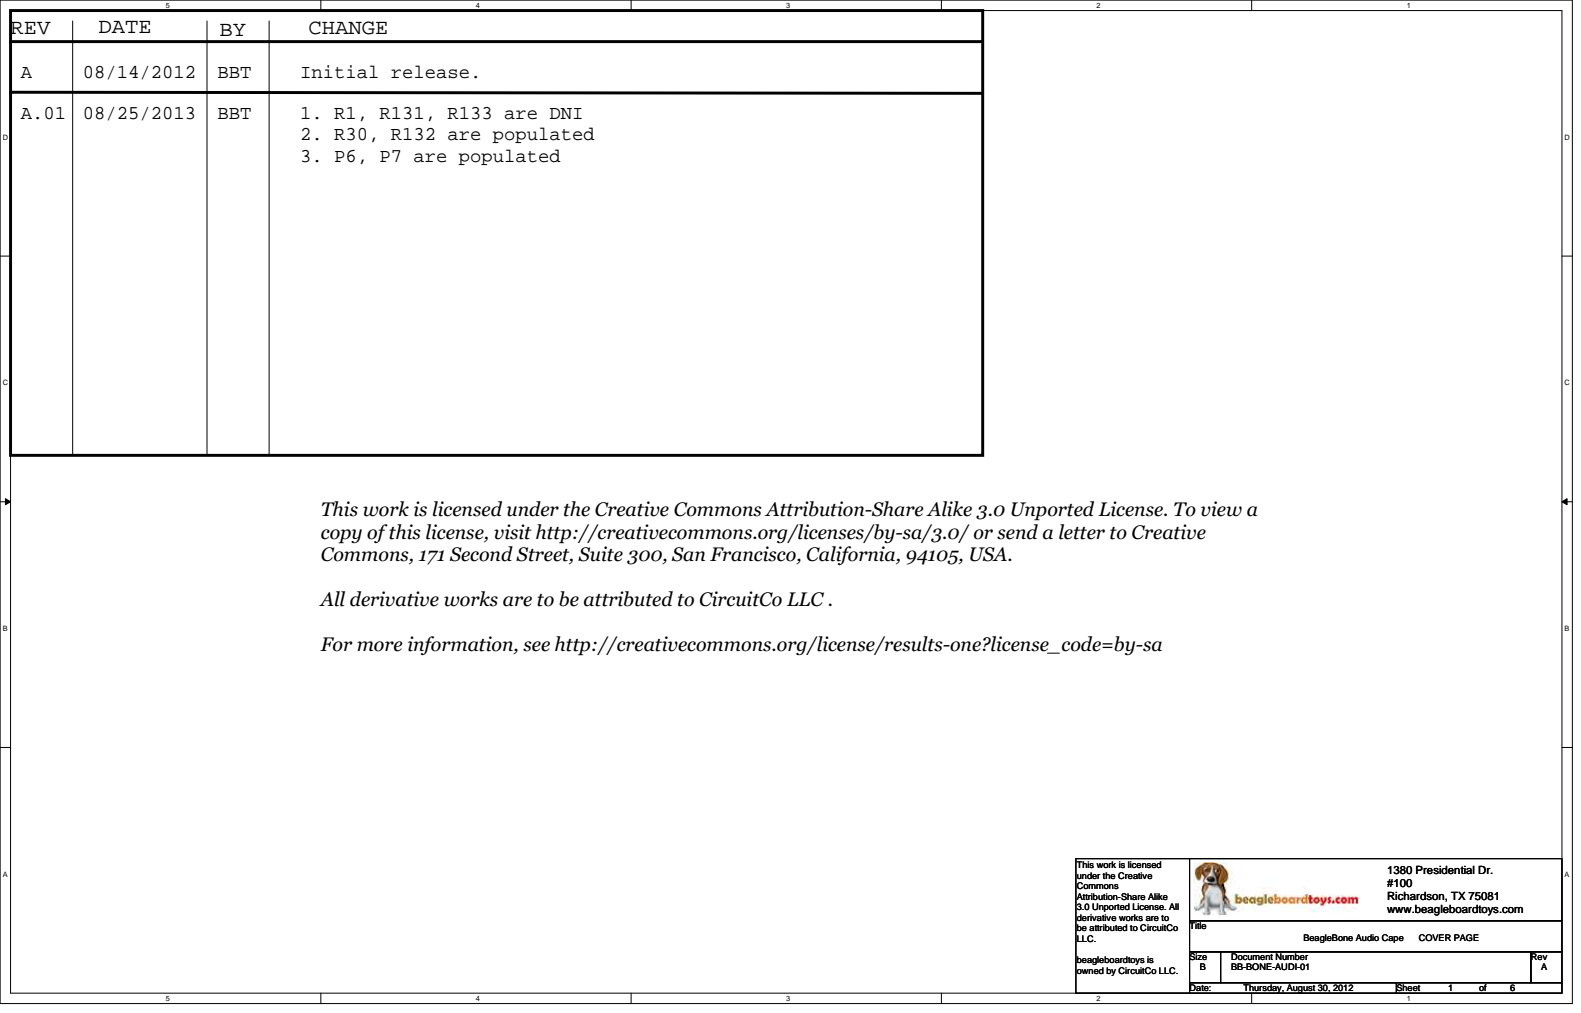
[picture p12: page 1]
REV; CHANGE; Initial release.; BBT; 1. R1, R131, R133 are DNI; 2. R30, R132 are populated 3. P6, P7 are populated; Title; Size; Document Number; Rev; Date:; Sheet; BB-BONE-AUDI-01; BeagleBone Audio Cape; COVER PAGE; Thursday, August 30, 2012

This work is licensed under the Creative Commons Attribution-Share Alike 3.0 Unported License. To view a
copy of this license, visit http://creativecommons.org/licenses/by-sa/3.0/ or send a letter to Creative
Commons, 171 Second Street, Suite 300, San Francisco, California, 94105, USA.

All derivative works are to be attributed to CircuitCo LLC .

For more information, see http://creativecommons.org/license/results-one?license_code=by-sa

This work is licensed
under the Creative
Commons
Attribution-Share Alike
3.0 Unported License. All
derivative works are to
be attributed to CircuitCo
LLC.

1380 Presidential Dr.
Richardson, TX 75081
www.beagleboardtoys.com

beagleboardtoys is
owned by CircuitCo LLC.

# CONN A IN

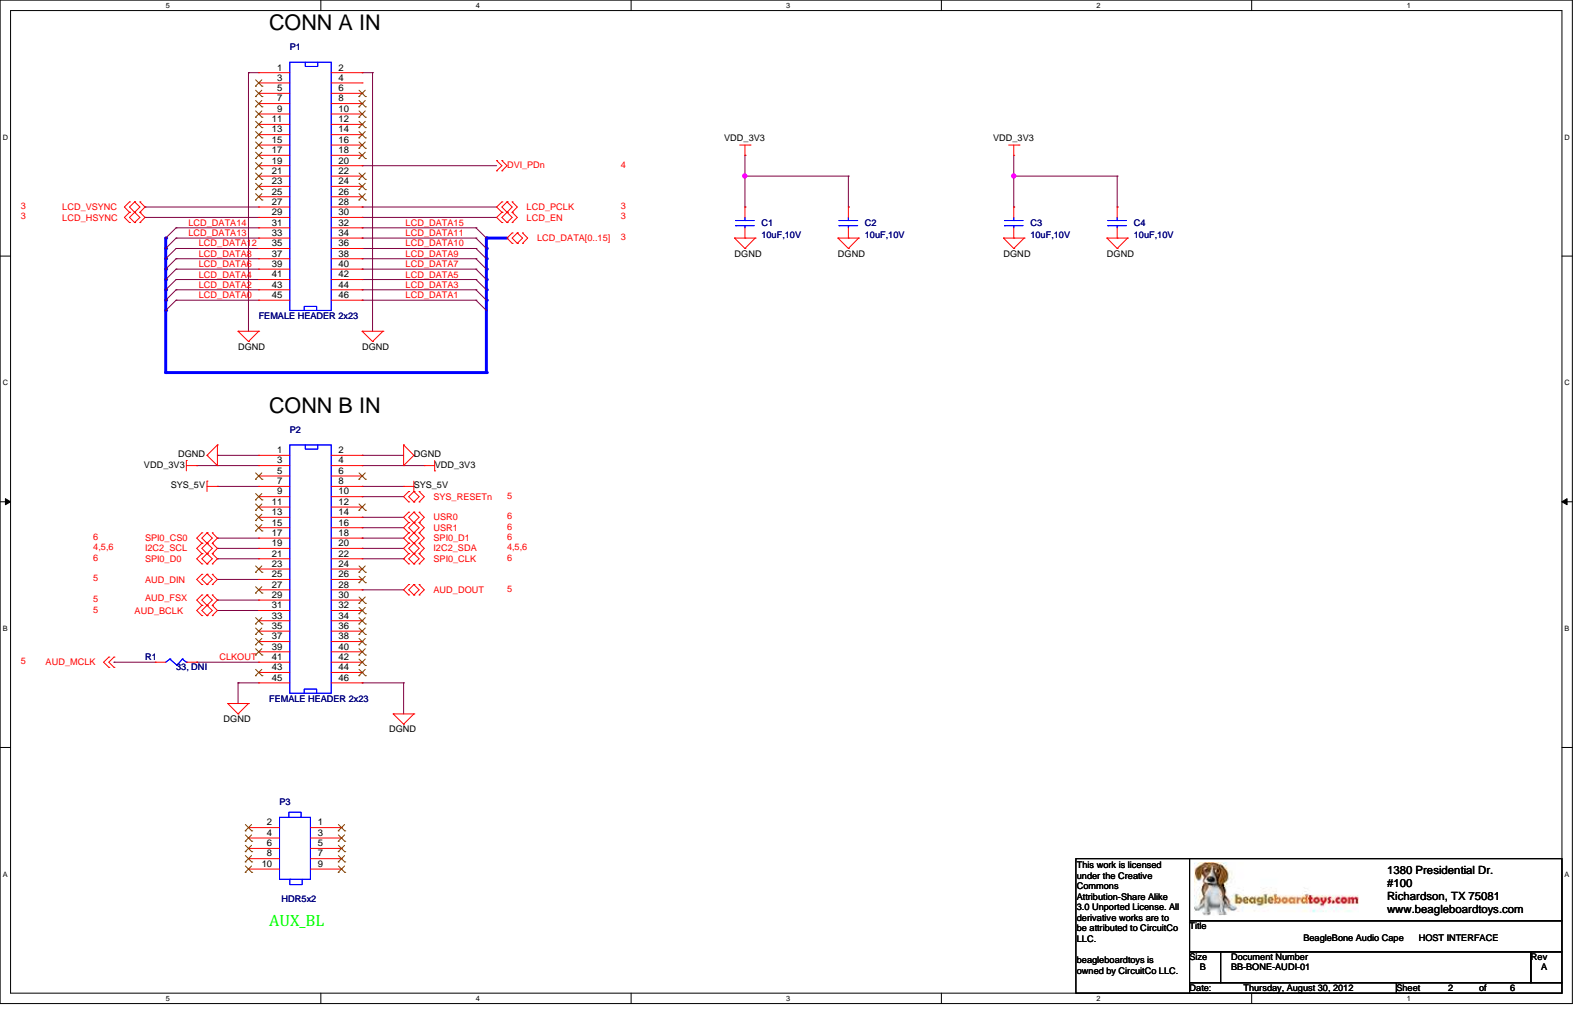
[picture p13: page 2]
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

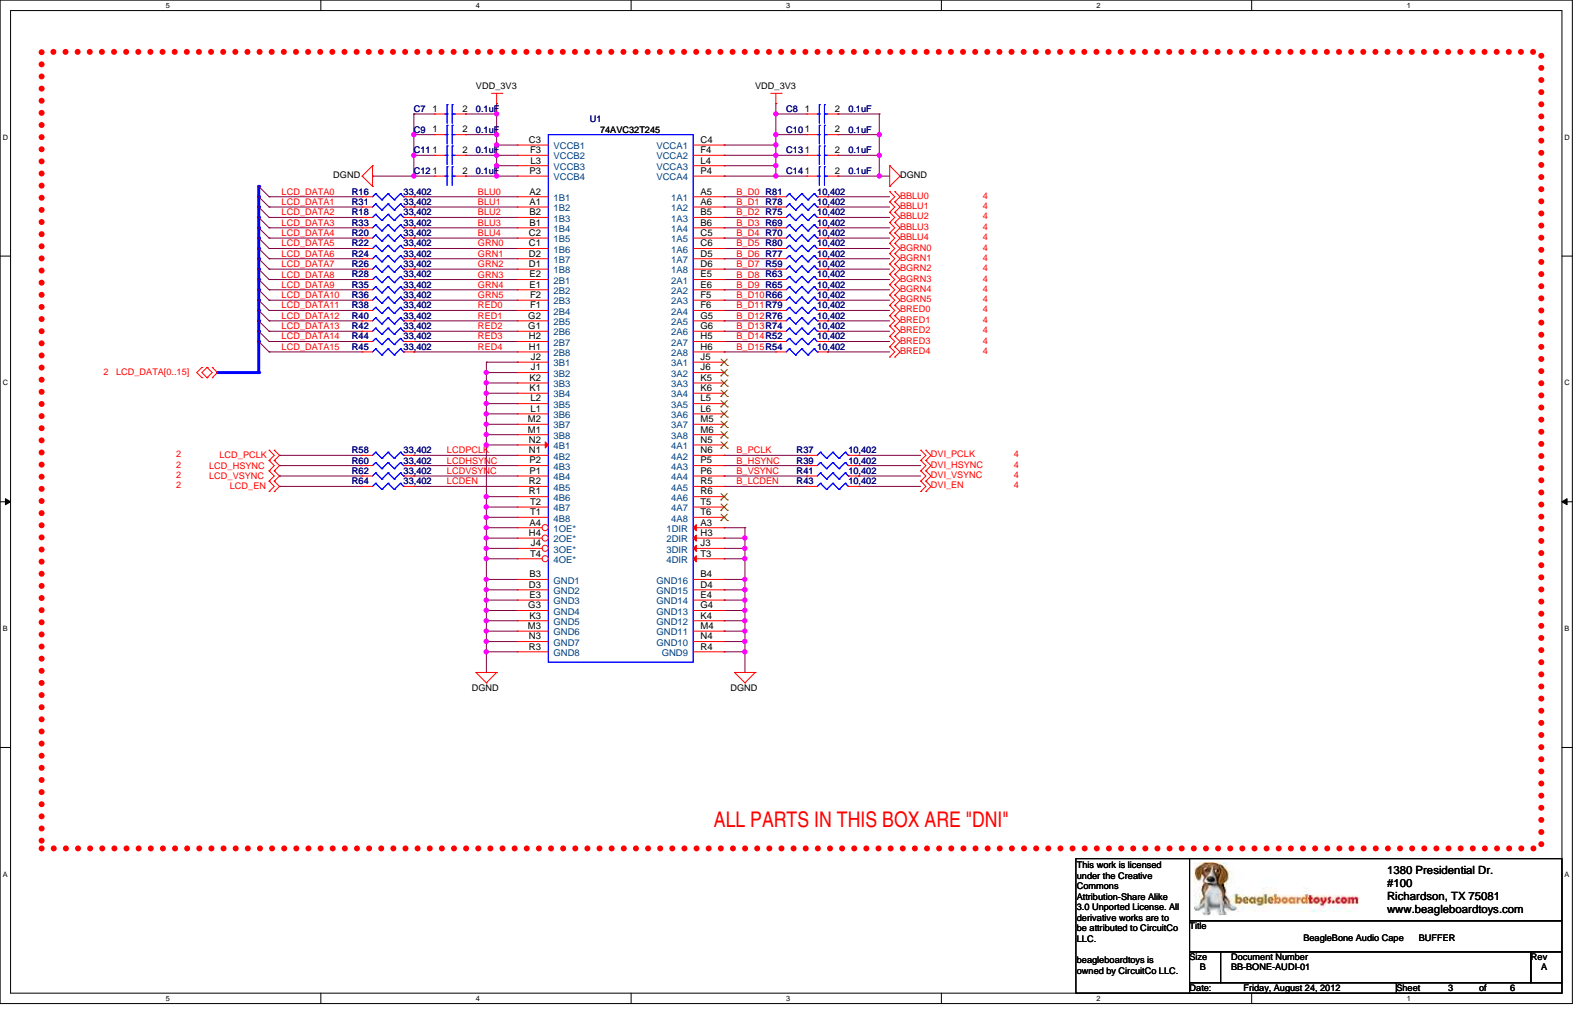
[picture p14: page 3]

ALL PARTS IN THIS BOX ARE "DNI"

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

# ISEL/RESET 13 PD 10 DVDD

t

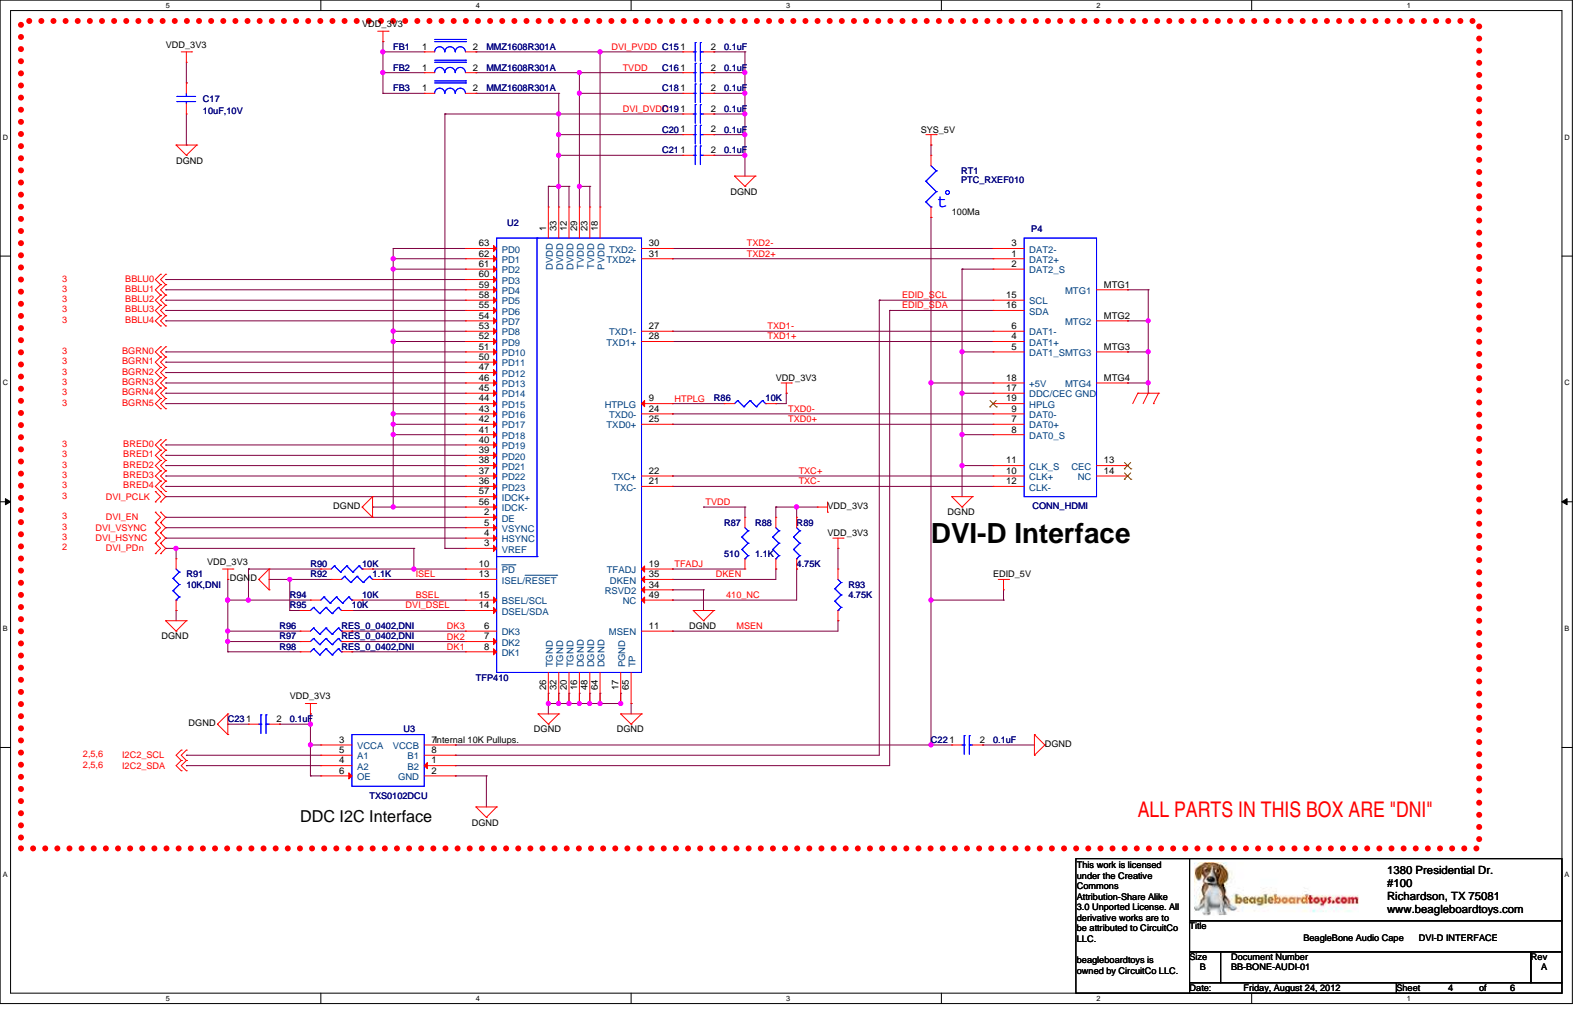
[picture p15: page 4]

DVI_DVDD C19 | 2 0.1uF 1

C20 | 2 0.1uF 1
C21 | 2 0.1uF 1

PVDD 18 TVDD 23 TVDD 29 DGND 48

ALL PARTS IN THIS BOX ARE "DNI"

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

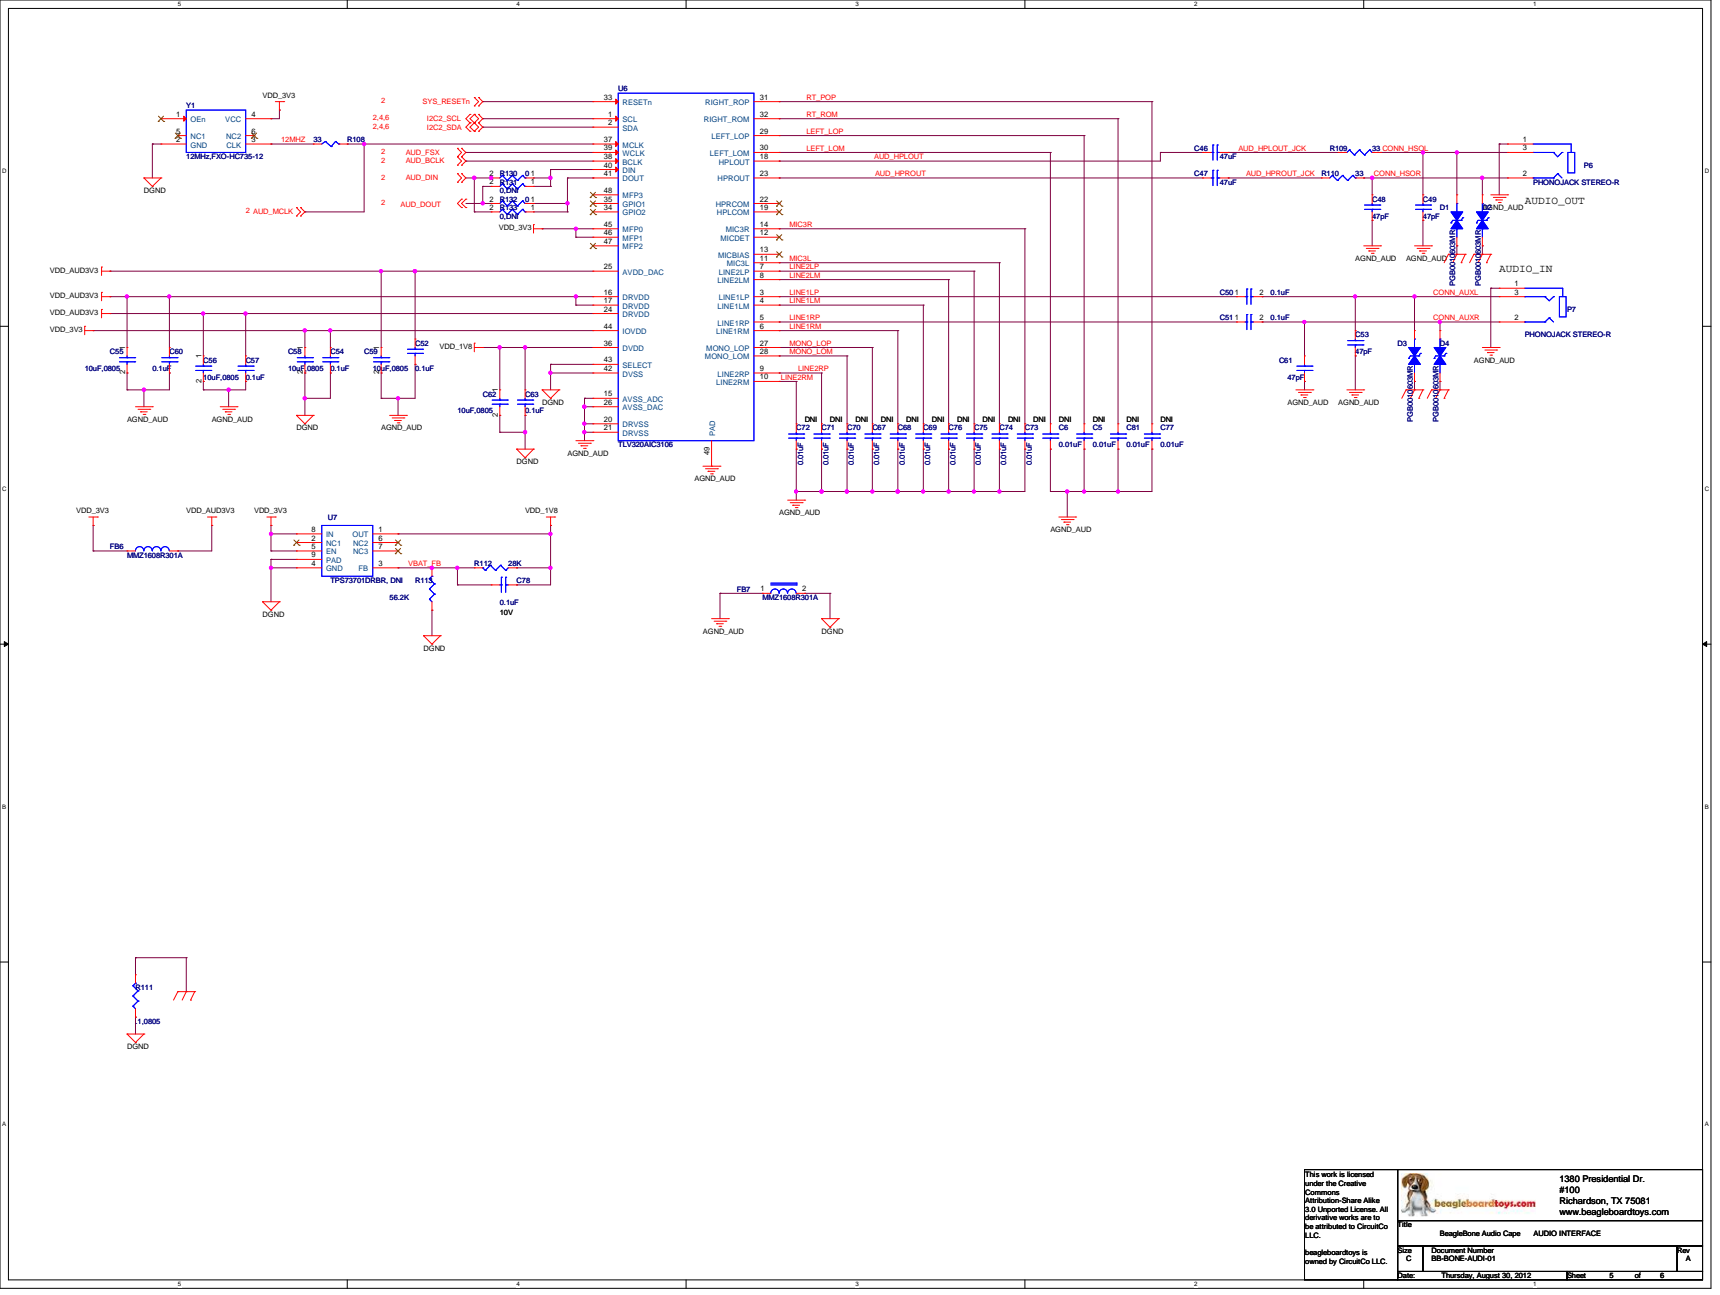
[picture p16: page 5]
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

## LED_COM

## SW1_A0

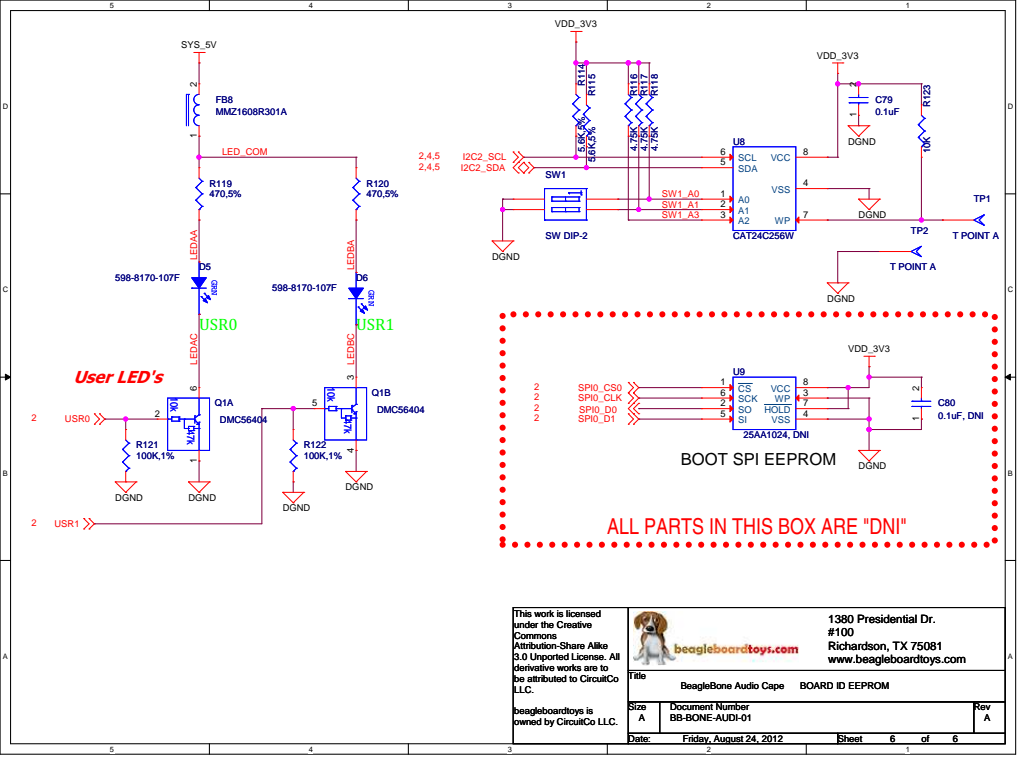
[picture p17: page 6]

ALL PARTS IN THIS BOX ARE "DNI"

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

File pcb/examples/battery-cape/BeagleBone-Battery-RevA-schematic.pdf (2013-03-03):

## 06/20/2012 BBT

# DATE

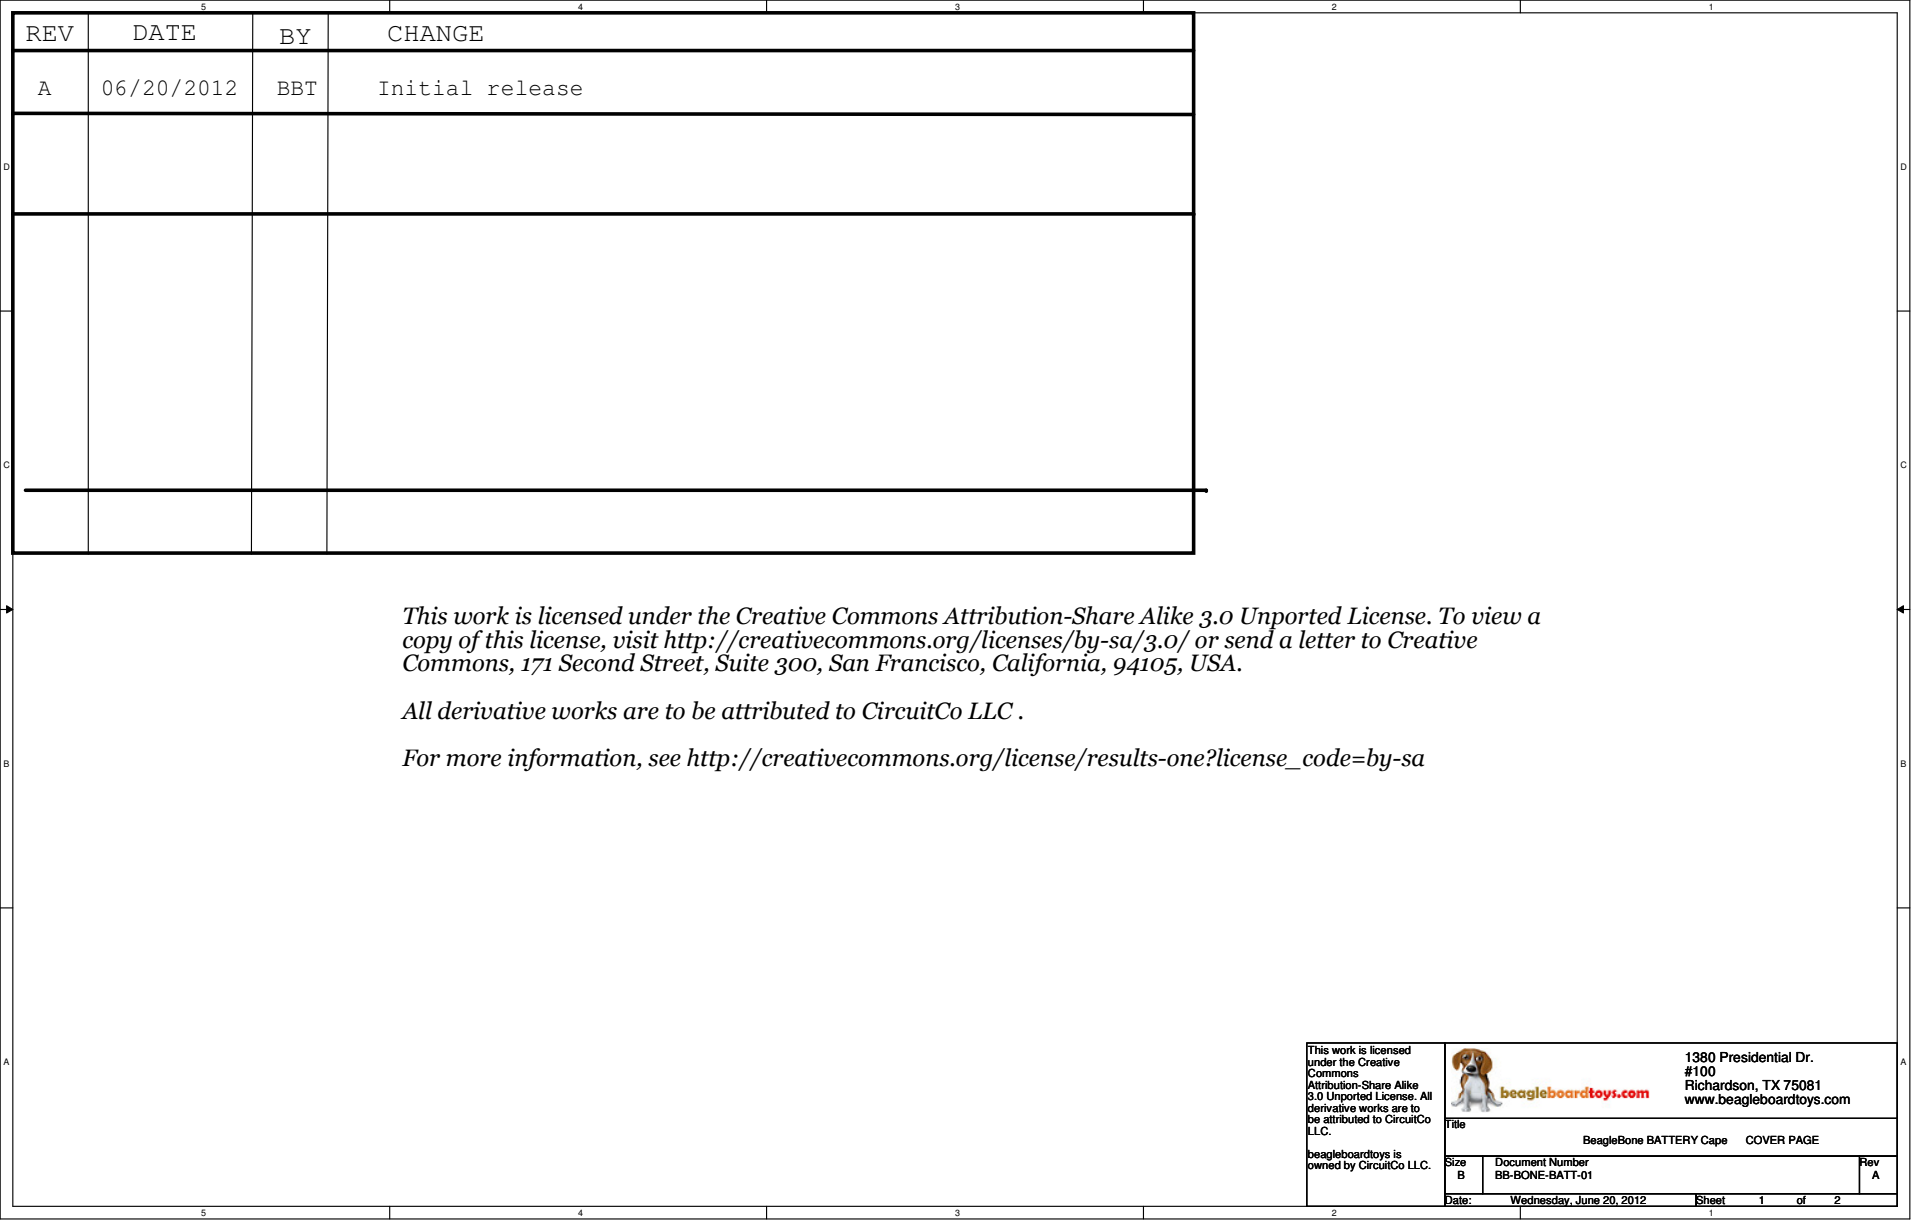
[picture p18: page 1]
REV; CHANGE; Initial release; Title; Size; Document Number; Rev; Date:; Sheet; BB-BONE-BATT-01; BeagleBone BATTERY Cape; COVER PAGE; Wednesday, June 20, 2012

This work is licensed under the Creative Commons Attribution-Share Alike 3.0 Unported License. To view a
copy of this license, visit http://creativecommons.org/licenses/by-sa/3.0/ or send a letter to Creative
Commons, 171 Second Street, Suite 300, San Francisco, California, 94105, USA.

All derivative works are to be attributed to CircuitCo LLC .

For more information, see http://creativecommons.org/license/results-one?license_code=by-sa

This work is licensed
under the Creative
Commons
Attribution-Share Alike
3.0 Unported License. All
derivative works are to
be attributed to CircuitCo
LLC.

1380 Presidential Dr.
Richardson, TX 75081
www.beagleboardtoys.com

beagleboardtoys is
owned by CircuitCo LLC.

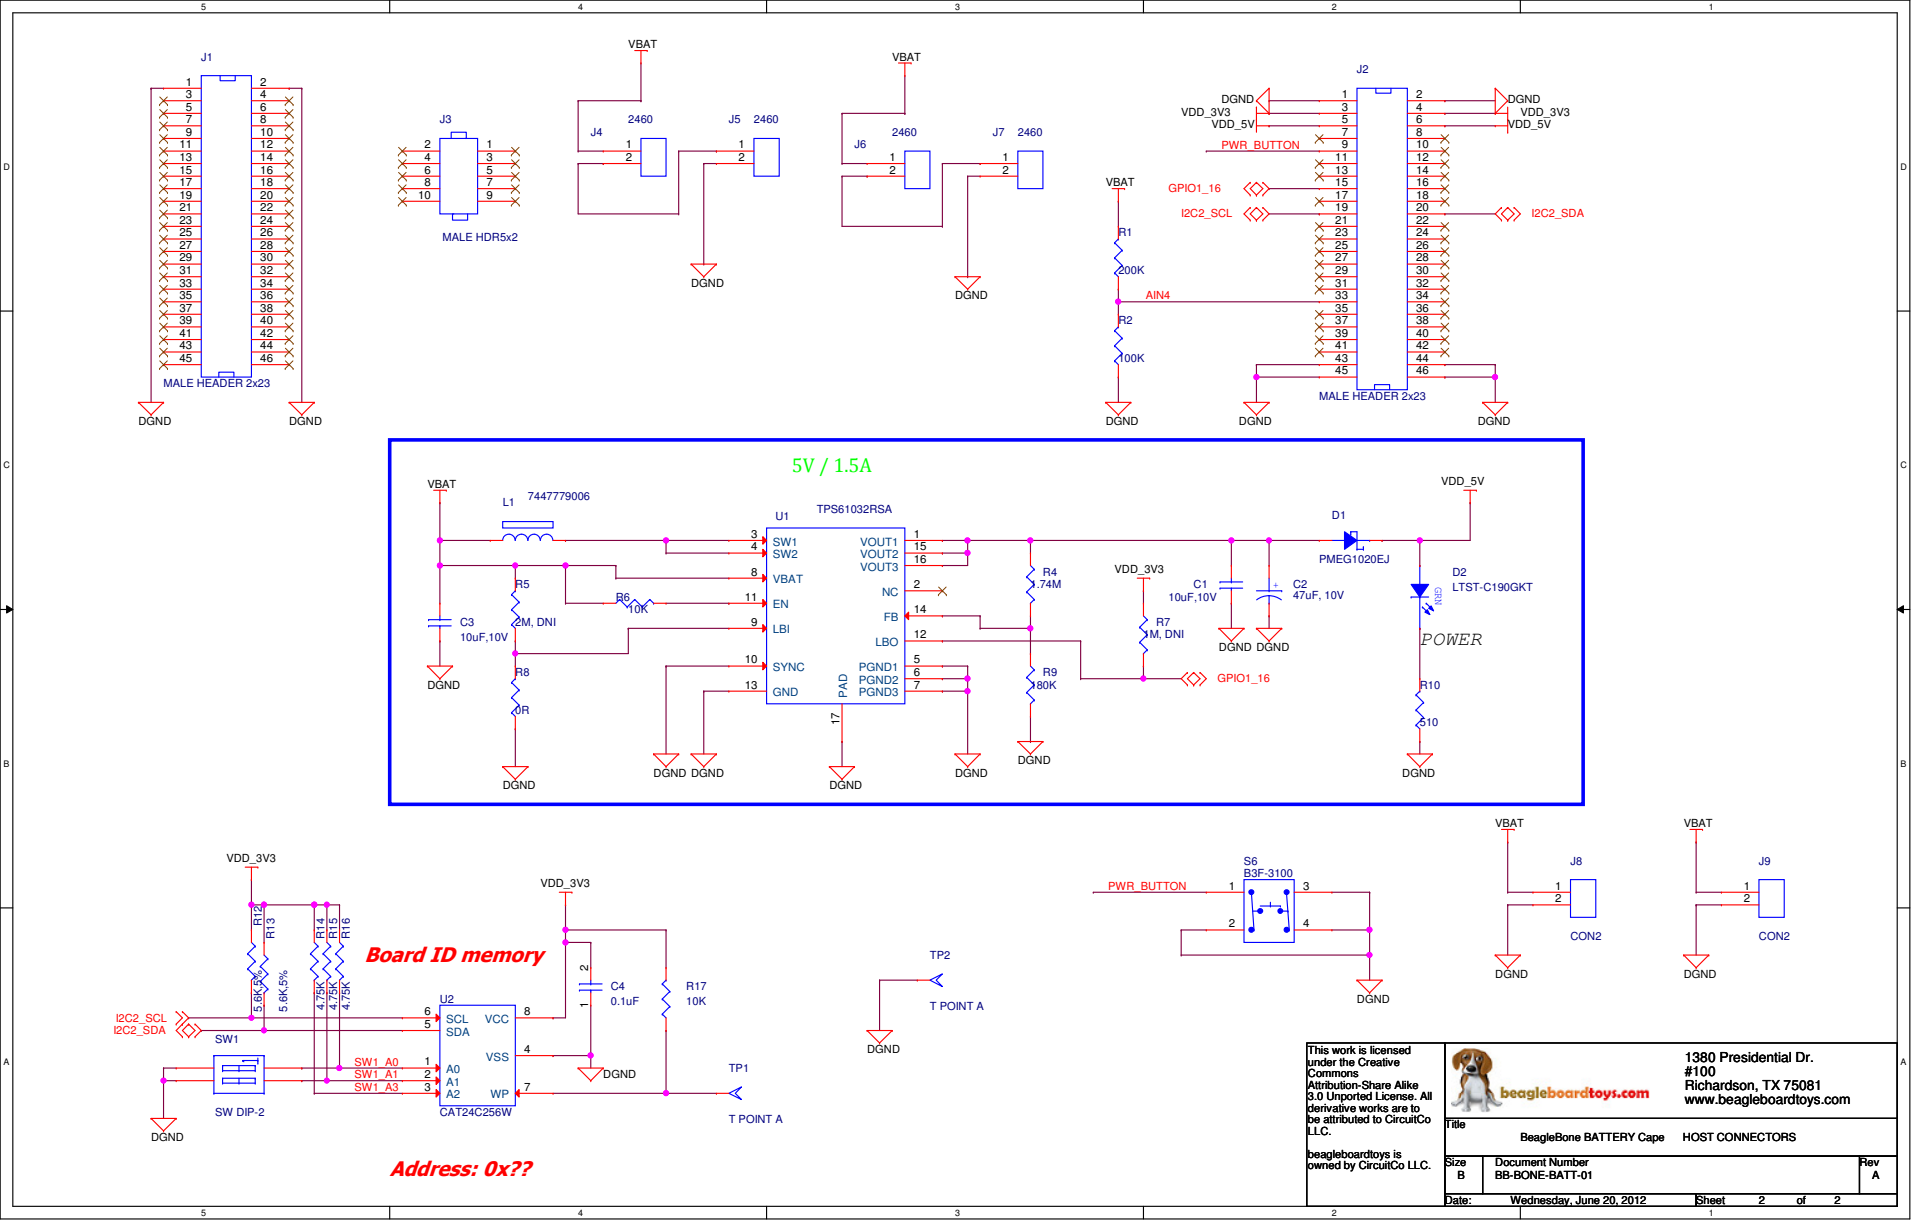
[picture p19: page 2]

VBAT

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

beagleboardtoys is
owned by CircuitCo LLC.

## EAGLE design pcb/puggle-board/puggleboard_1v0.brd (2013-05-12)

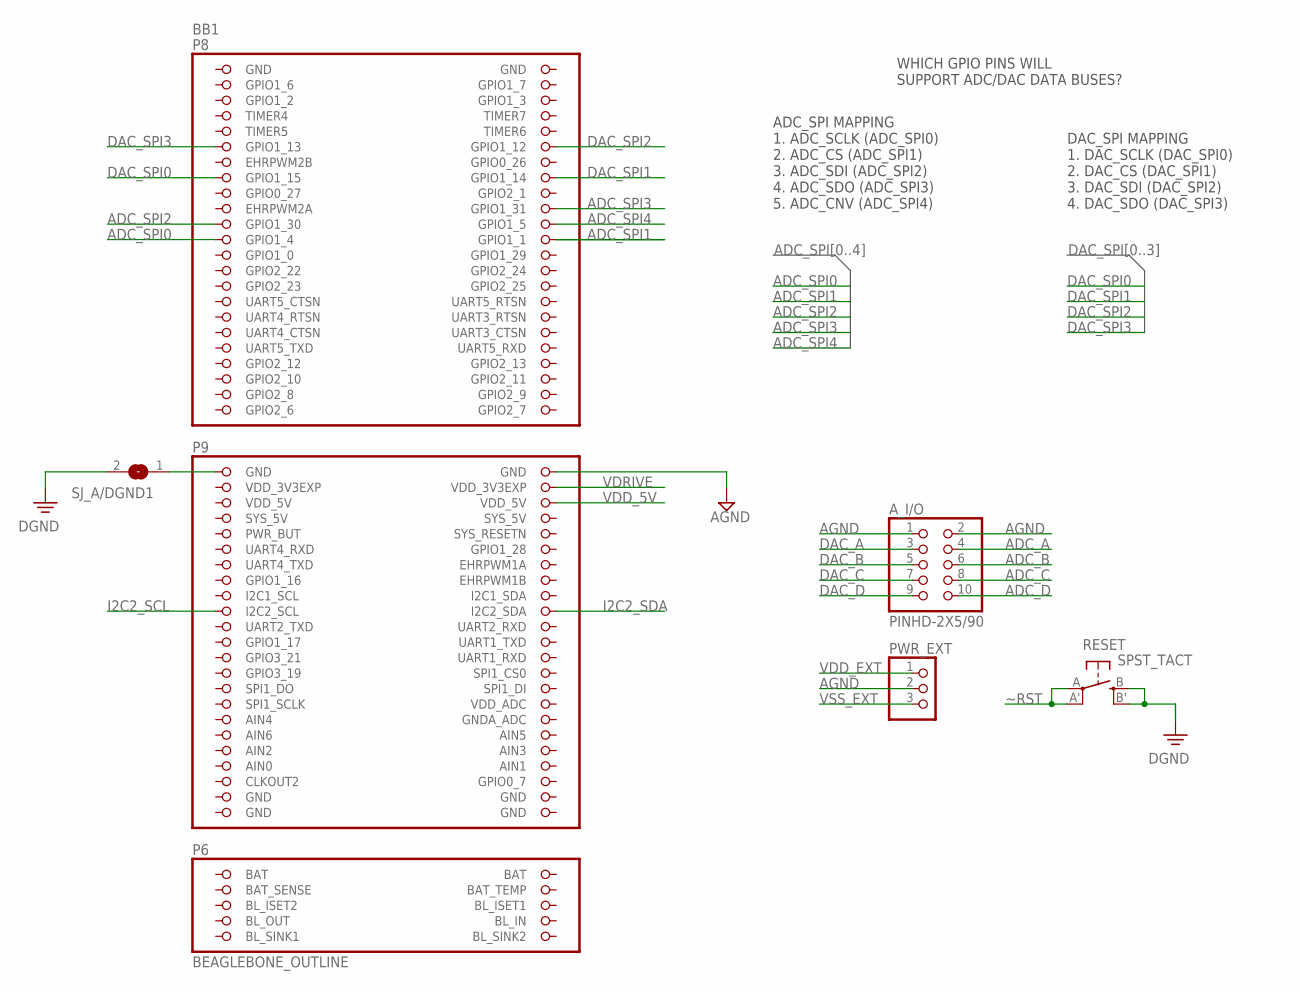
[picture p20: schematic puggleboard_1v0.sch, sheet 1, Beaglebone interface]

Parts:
A_I/O: PINHD-2X5/90; 2X05/90
BB1: BEAGLEBONE_OUTLINE; BEAGLEBONE_SHIELD
PWR_EXT: PINHD-1X3; 1X03
RESET: SPST_TACT; EVQ-Q2-A
SJ_A/DGND1: SJ

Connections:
ADC_A: A_I/O.4; also elsewhere on the board
ADC_B: A_I/O.6; also elsewhere on the board
ADC_C: A_I/O.8; also elsewhere on the board
ADC_D: A_I/O.10; also elsewhere on the board
ADC_SPI0: BB1.23 (GPIO1_4); also elsewhere on the board
ADC_SPI1: BB1.24 (GPIO1_1); also elsewhere on the board
ADC_SPI2: BB1.21 (GPIO1_30); also elsewhere on the board
ADC_SPI3: BB1.20 (GPIO1_31); also elsewhere on the board
ADC_SPI4: BB1.22 (GPIO1_5); also elsewhere on the board
AGND: A_I/O.1, A_I/O.2, BB1.48 (GND), PWR_EXT.2; also elsewhere on the board
AIN0: BB1.85 (AIN0)
BAT_SENSE: BB1.95 (BAT_SENSE)
BL_IN: BB1.97 (BL_IN)
BL_OUT: BB1.100 (BL_OUT)
BL_SINK1: BB1.101 (BL_SINK1)
BL_SINK2: BB1.102 (BL_SINK2)
DAC_A: A_I/O.3; also elsewhere on the board
DAC_B: A_I/O.5; also elsewhere on the board
DAC_C: A_I/O.7; also elsewhere on the board
DAC_D: A_I/O.9; also elsewhere on the board
DAC_SPI0: BB1.15 (GPIO1_15); also elsewhere on the board
DAC_SPI1: BB1.16 (GPIO1_14); also elsewhere on the board
DAC_SPI2: BB1.12 (GPIO1_12); also elsewhere on the board
DAC_SPI3: BB1.11 (GPIO1_13); also elsewhere on the board
DGND: RESET.B (S), RESET.B' (S1), SJ_A/DGND1.2; also elsewhere on the board
GND: BB1.1 (GND), BB1.2 (GND), BB1.89 (GND), BB1.90 (GND), BB1.91 (GND), BB1.92 (GND)
I2C2_SCL: BB1.65 (I2C2_SCL); also elsewhere on the board
I2C2_SDA: BB1.66 (I2C2_SDA); also elsewhere on the board
unnamed: BB1.47 (GND), SJ_A/DGND1.1
SYS_5V: BB1.53 (SYS_5V)
VDD_3V3EXP: BB1.49 (VDD_3V3EXP)
VDD_5V: BB1.51 (VDD_5V), BB1.52 (VDD_5V); also elsewhere on the board
VDD_EXT: PWR_EXT.1; also elsewhere on the board
VDRIVE: BB1.50 (VDD_3V3EXP); also elsewhere on the board
VSS_EXT: PWR_EXT.3; also elsewhere on the board
~RST: RESET.A, RESET.A' (P1); also elsewhere on the board

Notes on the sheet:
ADC_SPI MAPPING 1. ADC_SCLK (ADC_SPI0) 2. ADC_CS (ADC_SPI1) 3. ADC_SDI (ADC_SPI2) 4. ADC_SDO (ADC_SPI3) 5. ADC_CNV (ADC_SPI4)
DAC_SPI MAPPING 1. DAC_SCLK (DAC_SPI0) 2. DAC_CS (DAC_SPI1) 3. DAC_SDI (DAC_SPI2) 4. DAC_SDO (DAC_SPI3)
WHICH GPIO PINS WILL SUPPORT ADC/DAC DATA BUSES?

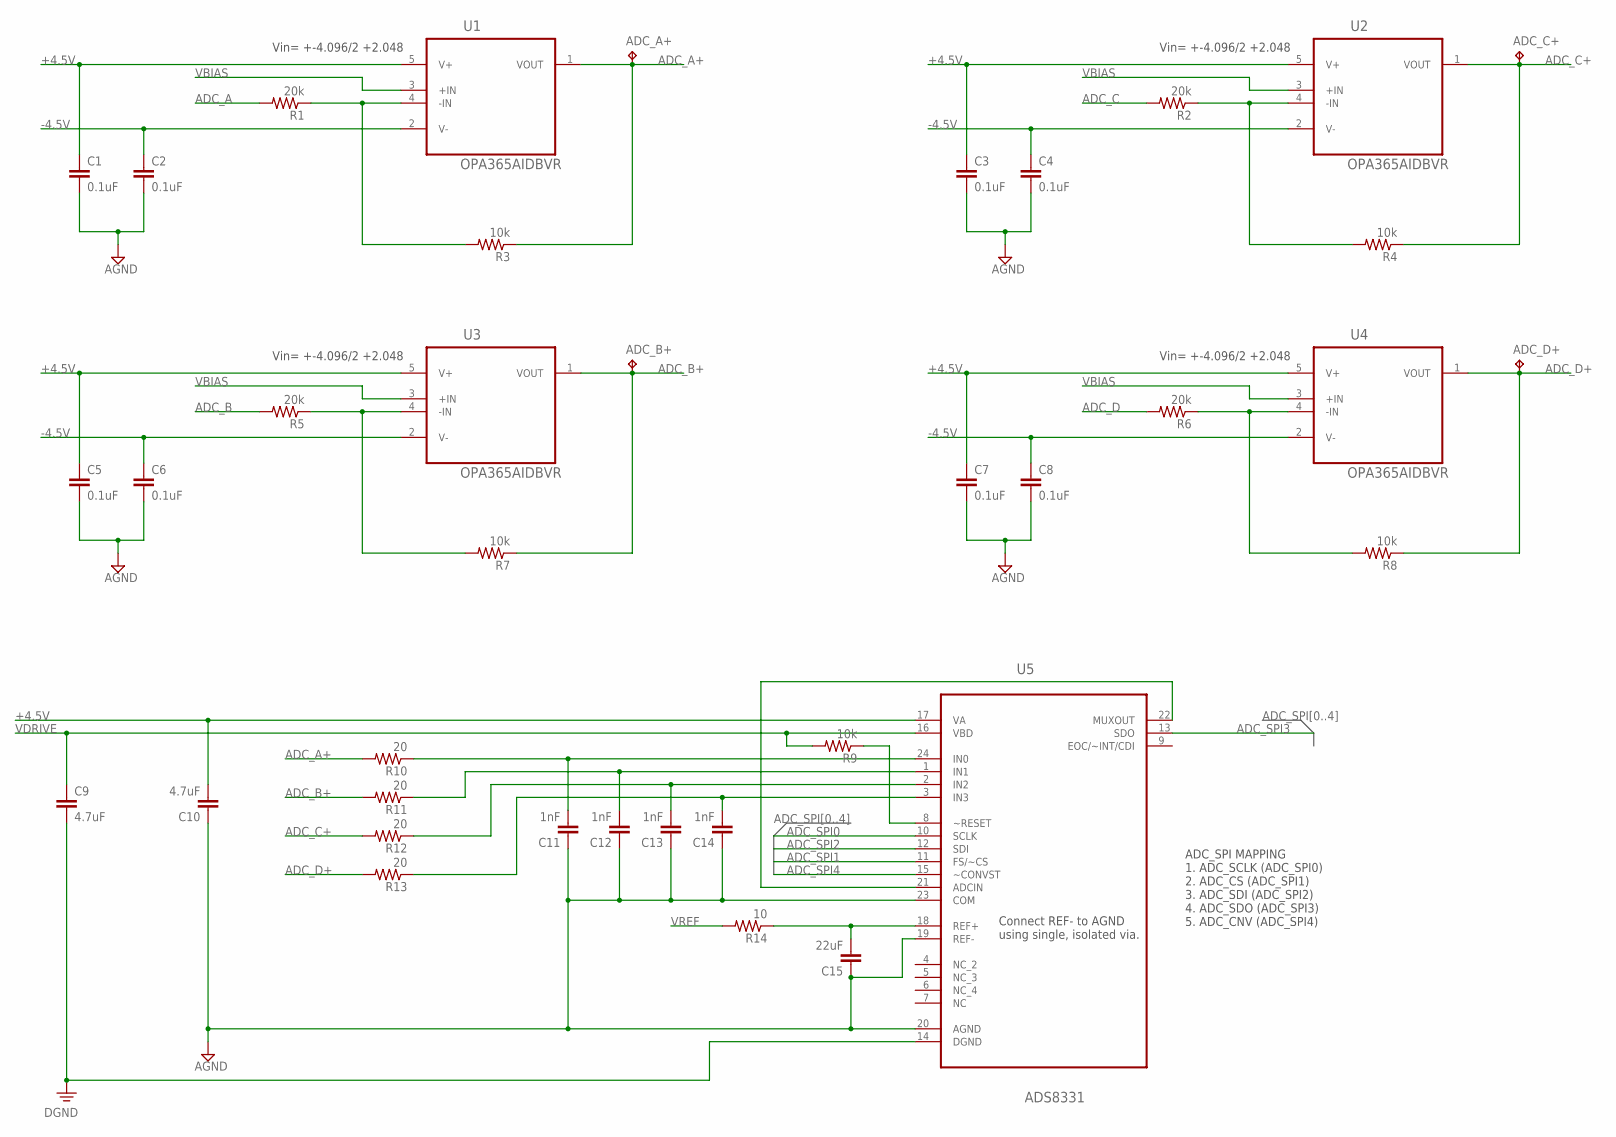
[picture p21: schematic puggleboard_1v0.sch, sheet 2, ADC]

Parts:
ADC_A+: TPB1,27; B1,27
ADC_B+: TPB1,27; B1,27
ADC_C+: TPB1,27; B1,27
ADC_D+: TPB1,27; B1,27
C1, C2, C3, C4, C5, C6, C7, C8: 0.1uF; C0603
C9, C10: 4.7uF; C0805
C11, C12, C13, C14: 1nF; C0603
C15: 22uF; C0603
R1, R2, R5, R6: 20k; R0603
R3, R4, R7, R8, R9: 10k; R0603
R10, R11, R12, R13: 20; R0603
R14: 10; R0603
U1, U2, U3, U4: OPA365AIDBVR; SOT95P280X145-5N
U5: ADS8331; SOP65P640X120-24N

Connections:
+4.5V: C1.1, C3.1, C5.1, C7.1, C10.2, U1.5 (V+), U2.5 (V+), U3.5 (V+), U4.5 (V+), U5.17 (VA); also elsewhere on the board
-4.5V: C2.1, C4.1, C6.1, C8.1, U1.2 (V-), U2.2 (V-), U3.2 (V-), U4.2 (V-); also elsewhere on the board
ADC_A: R1.2; also elsewhere on the board
ADC_A+: ADC_A+.TP, R3.1, R10.2, U1.1 (VOUT)
ADC_B: R5.2; also elsewhere on the board
ADC_B+: ADC_B+.TP, R7.1, R11.2, U3.1 (VOUT)
ADC_C: R2.2; also elsewhere on the board
ADC_C+: ADC_C+.TP, R4.1, R12.2, U2.1 (VOUT)
ADC_D: R6.2; also elsewhere on the board
ADC_D+: ADC_D+.TP, R8.1, R13.2, U4.1 (VOUT)
ADC_SPI0: U5.10 (SCLK); also elsewhere on the board
ADC_SPI1: U5.11 (FS/~CS); also elsewhere on the board
ADC_SPI2: U5.12 (SDI); also elsewhere on the board
ADC_SPI3: U5.13 (SDO); also elsewhere on the board
ADC_SPI4: U5.15 (~CONVST); also elsewhere on the board
AGND: C1.2, C2.2, C3.2, C4.2, C5.2, C6.2, C7.2, C8.2, C10.1, C11.1, C12.1, C13.1, C14.1, C15.1, U5.19 (REF-), U5.20 (AGND), U5.23 (COM); also elsewhere on the board
DGND: C9.2, U5.14 (DGND); also elsewhere on the board
unnamed: R1.1, R3.2, U1.4 (-IN)
unnamed: R5.1, R7.2, U3.4 (-IN)
unnamed: R2.1, R4.2, U2.4 (-IN)
unnamed: R6.1, R8.2, U4.4 (-IN)
unnamed: C15.2, R14.1, U5.18 (REF+)
unnamed: U5.21 (ADCIN), U5.22 (MUXOUT)
unnamed: C11.2, R10.1, U5.24 (IN0)
unnamed: C12.2, R11.1, U5.1 (IN1)
unnamed: C13.2, R12.1, U5.2 (IN2)
unnamed: C14.2, R13.1, U5.3 (IN3)
VBIAS: U1.3 (+IN), U2.3 (+IN), U3.3 (+IN), U4.3 (+IN); also elsewhere on the board
VDRIVE: C9.1, R9.2, U5.16 (VBD); also elsewhere on the board
VREF: R14.2; also elsewhere on the board
~RST: R9.1, U5.8 (~RESET); also elsewhere on the board

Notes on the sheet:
Connect REF- to AGND using single, isolated via.
Vin= +-4.096/2 +2.048
ADC_SPI MAPPING 1. ADC_SCLK (ADC_SPI0) 2. ADC_CS (ADC_SPI1) 3. ADC_SDI (ADC_SPI2) 4. ADC_SDO (ADC_SPI3) 5. ADC_CNV (ADC_SPI4)

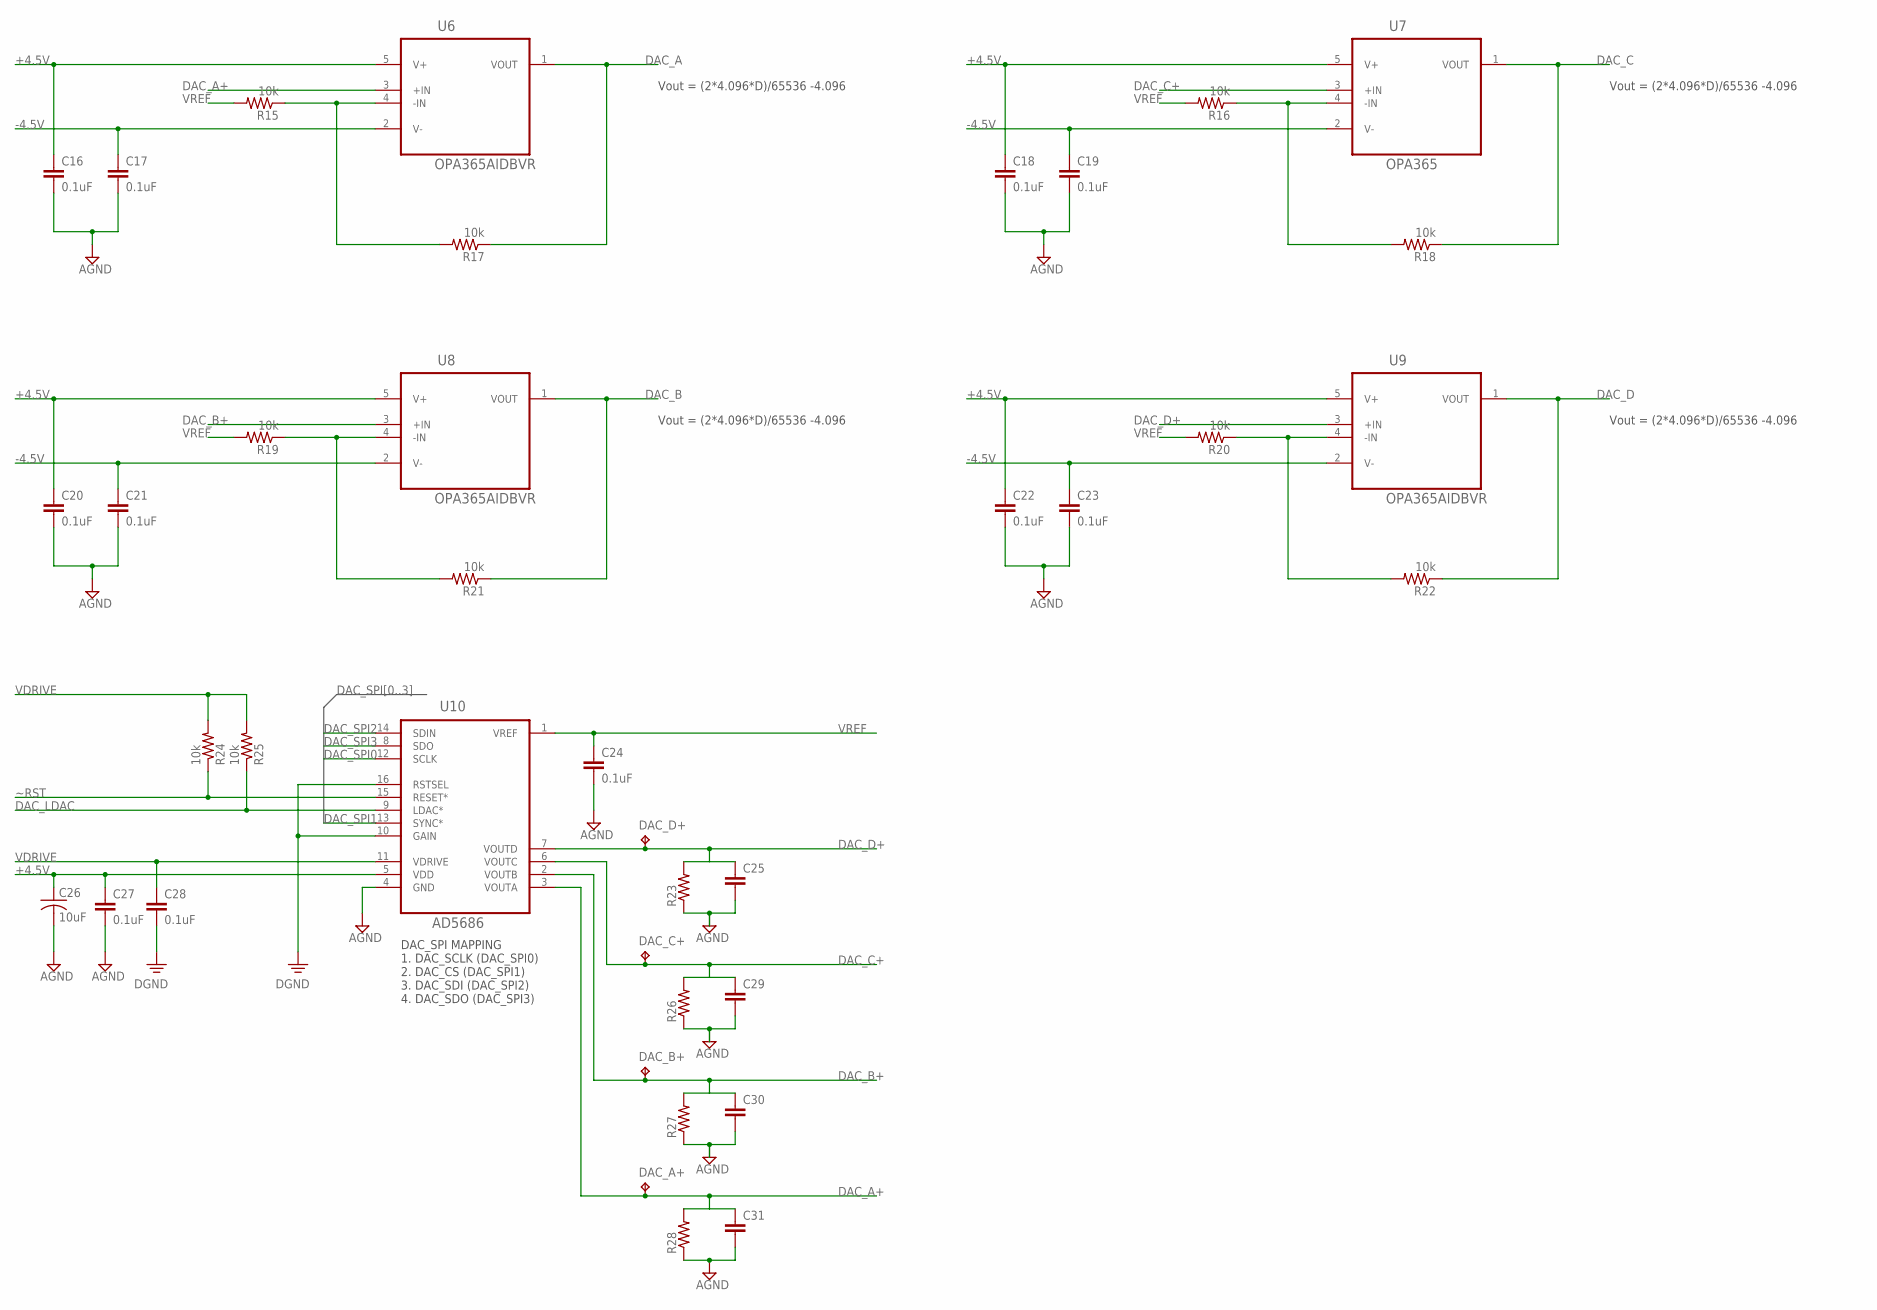
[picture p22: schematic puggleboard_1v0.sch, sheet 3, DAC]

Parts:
C16, C17, C18, C19, C20, C21, C22, C23, C24, C27, C28: 0.1uF; C0603
C25, C29, C30, C31: C-EUC0603; C0603
C26: 10uF; C0805
DAC_A+: TPB1,27; B1,27
DAC_B+: TPB1,27; B1,27
DAC_C+: TPB1,27; B1,27
DAC_D+: TPB1,27; B1,27
R15, R16, R17, R18, R19, R20, R21, R22, R24, R25: 10k; R0603
R23, R26, R27, R28: R-US_R0603; R0603
U6, U8, U9: OPA365AIDBVR; SOT95P280X145-5N
U7: OPA365; SOT95P280X145-5N
U10: AD5686; MO-153-AB

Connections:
+4.5V: C16.1, C18.1, C20.1, C22.1, C26.1, C27.1, U6.5 (V+), U7.5 (V+), U8.5 (V+), U9.5 (V+), U10.5 (VDD); also elsewhere on the board
-4.5V: C17.1, C19.1, C21.1, C23.1, U6.2 (V-), U7.2 (V-), U8.2 (V-), U9.2 (V-); also elsewhere on the board
AGND: C16.2, C17.2, C18.2, C19.2, C20.2, C21.2, C22.2, C23.2, C24.2, C25.2, C26.2, C27.2, C29.2, C30.2, C31.2, R23.1, R26.1, R27.1, R28.1, U10.4 (GND); also elsewhere on the board
DAC_A: R17.1, U6.1 (VOUT); also elsewhere on the board
DAC_A+: C31.1, DAC_A+.TP, R28.2, U6.3 (+IN), U10.3 (VOUTA)
DAC_B: R21.1, U8.1 (VOUT); also elsewhere on the board
DAC_B+: C30.1, DAC_B+.TP, R27.2, U8.3 (+IN), U10.2 (VOUTB)
DAC_C: R18.1, U7.1 (VOUT); also elsewhere on the board
DAC_C+: C29.1, DAC_C+.TP, R26.2, U7.3 (+IN), U10.6 (VOUTC)
DAC_D: R22.1, U9.1 (VOUT); also elsewhere on the board
DAC_D+: C25.1, DAC_D+.TP, R23.2, U9.3 (+IN), U10.7 (VOUTD)
DAC_LDAC: R25.1, U10.9 (LDAC*)
DAC_SPI0: U10.12 (SCLK); also elsewhere on the board
DAC_SPI1: U10.13 (SYNC*); also elsewhere on the board
DAC_SPI2: U10.14 (SDIN); also elsewhere on the board
DAC_SPI3: U10.8 (SDO); also elsewhere on the board
DGND: C28.2, U10.10 (GAIN), U10.16 (RSTSEL); also elsewhere on the board
unnamed: R16.1, R18.2, U7.4 (-IN)
unnamed: R19.1, R21.2, U8.4 (-IN)
unnamed: R20.1, R22.2, U9.4 (-IN)
unnamed: R15.1, R17.2, U6.4 (-IN)
VDRIVE: C28.1, R24.2, R25.2, U10.11 (VDRIVE); also elsewhere on the board
VREF: C24.1, R15.2, R16.2, R19.2, R20.2, U10.1 (VREF); also elsewhere on the board
~RST: R24.1, U10.15 (RESET*); also elsewhere on the board

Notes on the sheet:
Vout = (2*4.096*D)/65536 -4.096
DAC_SPI MAPPING 1. DAC_SCLK (DAC_SPI0) 2. DAC_CS (DAC_SPI1) 3. DAC_SDI (DAC_SPI2) 4. DAC_SDO (DAC_SPI3)

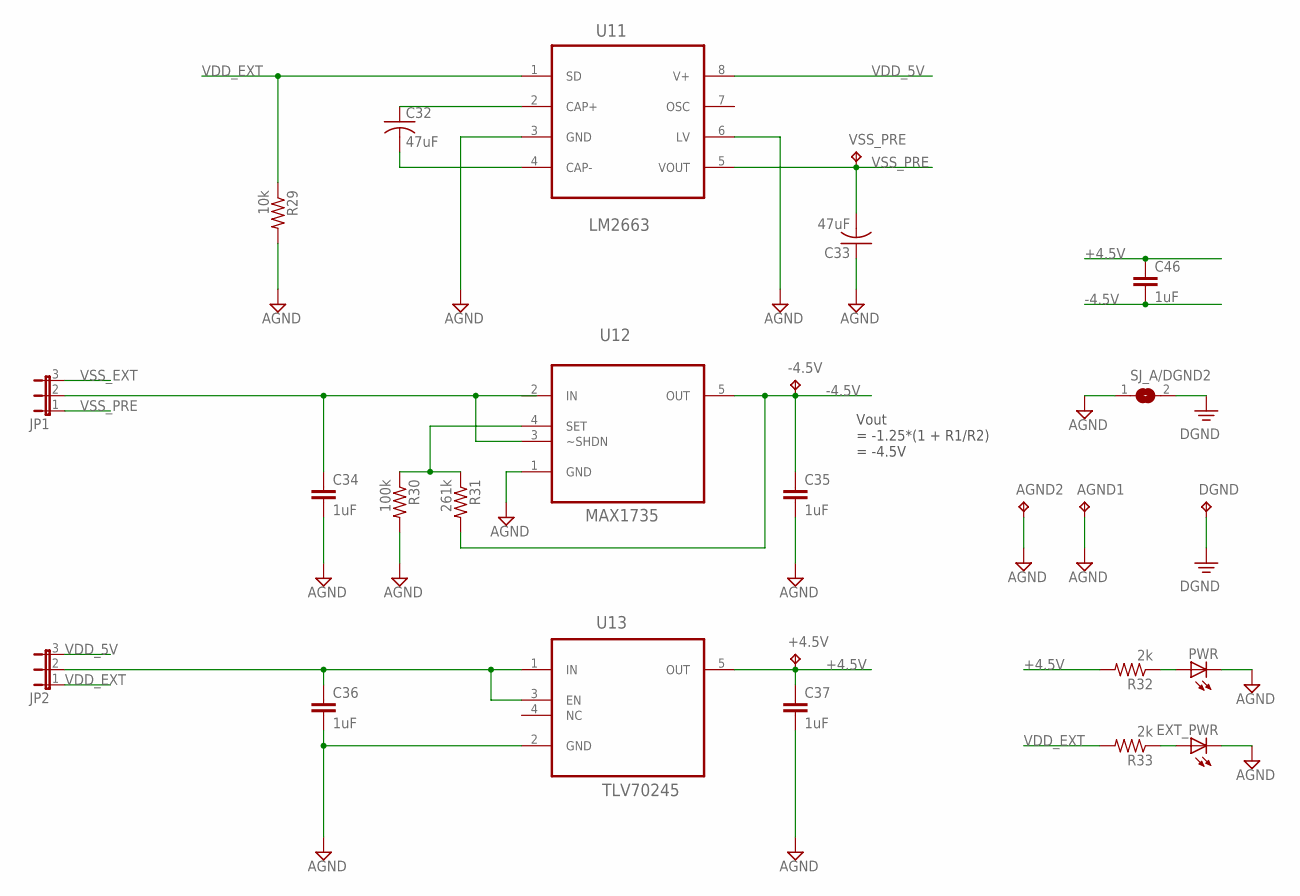
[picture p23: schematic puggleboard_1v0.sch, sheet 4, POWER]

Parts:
+4.5V: TPPAD1-17; P1-17
-4.5V: TPB1,27; B1,27
AGND1, AGND2: TPPAD1-17; P1-17
C32, C33: 47uF; C1206
C34, C35, C36, C37, C46: 1uF; C0603
DGND: TPPAD1-17; P1-17
EXT_PWR: LEDCHIPLED_0805; CHIPLED_0805
JP1, JP2: JP2E; JP2
PWR: LEDCHIPLED_0805; CHIPLED_0805
R29: 10k; R0603
R30: 100k; R0603
R31: 261k; R0603
R32, R33: 2k; R0603
SJ_A/DGND2: SJ
U11: LM2663; SOIC127P600X175-8N
U12: MAX1735; SOT95P280X145-5N
U13: TLV70245; SOT95P280X110-5N
VSS_PRE: TPB1,27; B1,27

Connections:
+4.5V: +4.5V.TP, C37.1, C46.1, R32.2, U13.5 (OUT); also elsewhere on the board
-4.5V: -4.5V.TP, C35.1, C46.2, R31.2, U12.5 (OUT); also elsewhere on the board
AGND: AGND1.TP, AGND2.TP, C33.1, C34.2, C35.2, C36.2, C37.2, EXT_PWR.C, PWR.C, R29.2, R30.2, SJ_A/DGND2.1, U11.3 (GND), U11.6 (LV), U12.1 (GND), U13.2 (GND); also elsewhere on the board
DGND: DGND.TP, SJ_A/DGND2.2; also elsewhere on the board
unnamed: R30.1, R31.1, U12.4 (SET)
unnamed: EXT_PWR.A, R33.1
unnamed: C36.1, JP2.2, U13.1 (IN), U13.3 (EN)
unnamed: PWR.A, R32.1
unnamed: C34.1, JP1.2, U12.3 (~SHDN)
unnamed: C32.1, U11.2 (CAP+)
unnamed: C32.2, U11.4 (CAP-)
VDD_5V: JP2.3, U11.8 (V+); also elsewhere on the board
VDD_EXT: JP2.1, R29.1, R33.2, U11.1 (SD); also elsewhere on the board
VSS_EXT: JP1.3; also elsewhere on the board
VSS_PRE: C33.2, JP1.1, U11.5 (VOUT), VSS_PRE.TP

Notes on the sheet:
Vout = -1.25*(1 + R1/R2) = -4.5V

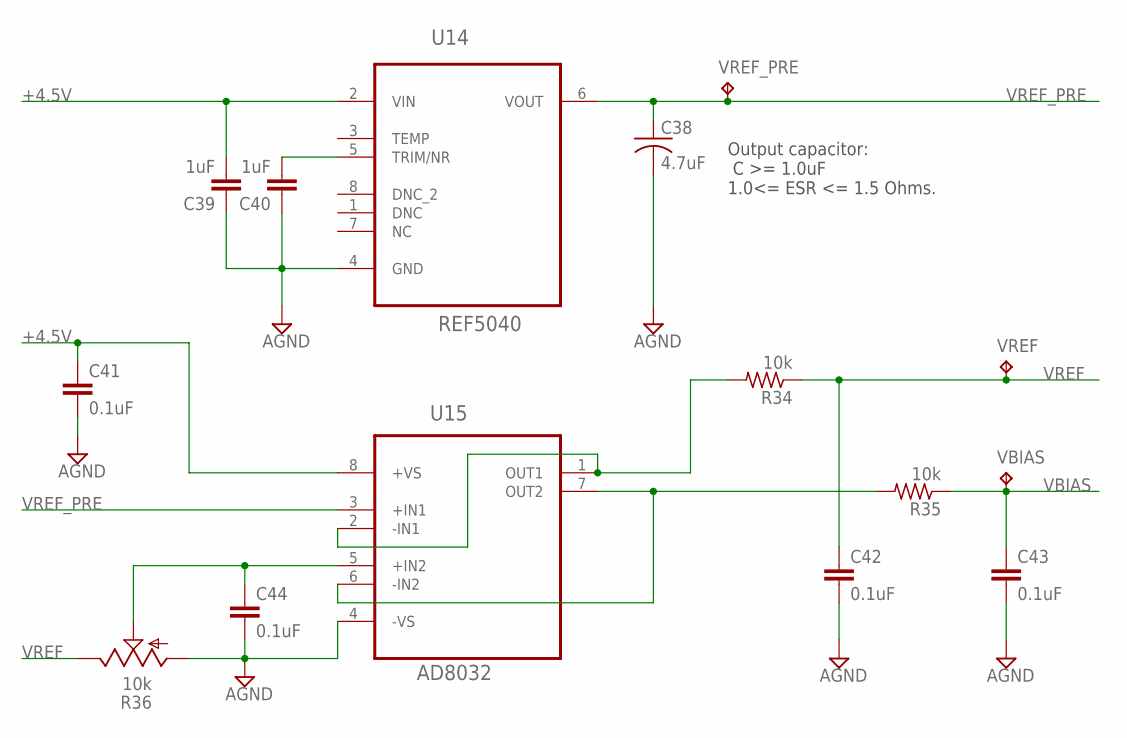
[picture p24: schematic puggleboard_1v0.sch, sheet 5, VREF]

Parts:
C38: 4.7uF; C1206
C39, C40: 1uF; C0603
C41, C42, C43, C44: 0.1uF; C0603
R34, R35: 10k; R0603
R36: 10k; M84W-TRIMMER
U14: REF5040; SOIC127P600X175-8N
U15: AD8032; SOIC127P600X175-8N
VBIAS: TPB1,27; B1,27
VREF: TPB1,27; B1,27
VREF_PRE: TPB1,27; B1,27

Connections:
+4.5V: C39.2, C41.1, U14.2 (VIN), U15.8 (+VS); also elsewhere on the board
AGND: C38.2, C39.1, C40.1, C41.2, C42.2, C43.2, C44.2, R36.3 (A), U14.4 (GND), U15.4 (-VS); also elsewhere on the board
unnamed: C44.1, R36.2 (S), U15.5 (+IN2)
unnamed: R35.2, U15.6 (-IN2), U15.7 (OUT2)
unnamed: R34.2, U15.1 (OUT1), U15.2 (-IN1)
unnamed: C40.2, U14.5 (TRIM/NR)
VBIAS: C43.1, R35.1, VBIAS.TP; also elsewhere on the board
VREF: C42.1, R34.1, R36.1 (E), VREF.TP; also elsewhere on the board
VREF_PRE: C38.1, U14.6 (VOUT), U15.3 (+IN1), VREF_PRE.TP

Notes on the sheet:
Output capacitor: C >= 1.0uF 1.0<= ESR <= 1.5 Ohms.

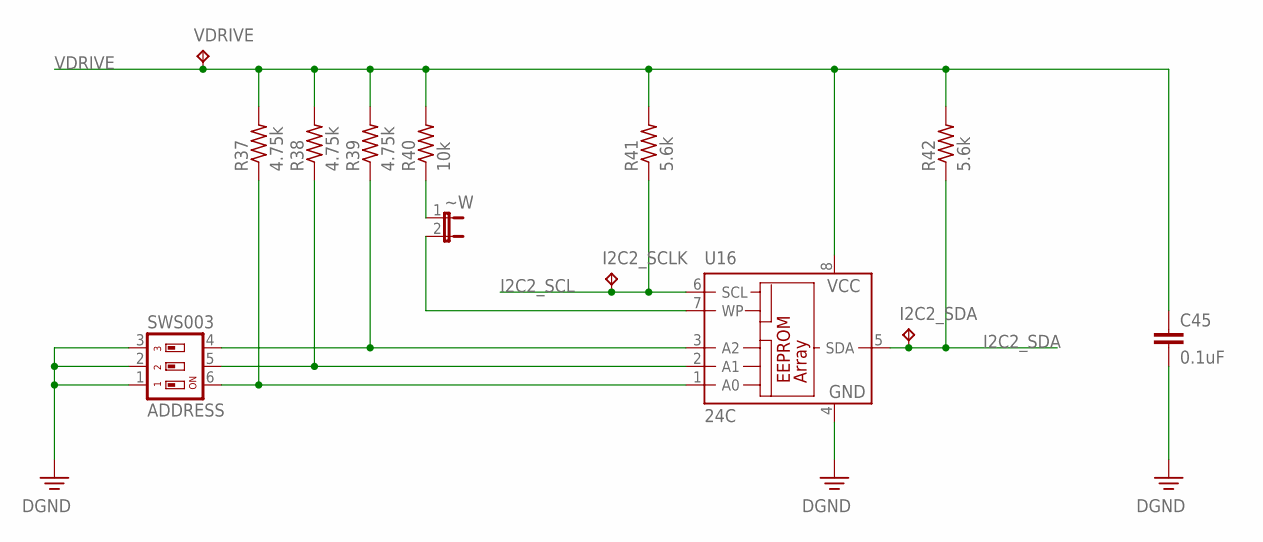
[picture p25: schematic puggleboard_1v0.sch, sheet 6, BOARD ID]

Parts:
ADDRESS: SWS003; SMS-003
C45: 0.1uF; C0603
I2C2_SCLK, I2C2_SDA: TPB1,27; B1,27
R37, R38, R39: 4.75k; R0603
R40: 10k; R0603
R41, R42: 5.6k; R0603
U16: 24C; SO-08
VDRIVE: TPPAD1-17; P1-17
~W: JP1E; JP1

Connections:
DGND: ADDRESS.1, ADDRESS.2, ADDRESS.3, C45.2, U16.4 (GND); also elsewhere on the board
I2C2_SCL: I2C2_SCLK.TP, R41.1, U16.6 (SCL); also elsewhere on the board
I2C2_SDA: I2C2_SDA.TP, R42.1, U16.5 (SDA); also elsewhere on the board
unnamed: ADDRESS.6, R37.1, U16.1 (A0)
unnamed: ADDRESS.5, R38.1, U16.2 (A1)
unnamed: ADDRESS.4, R39.1, U16.3 (A2)
unnamed: U16.7 (WP), ~W.2
unnamed: R40.1, ~W.1
VDRIVE: C45.1, R37.2, R38.2, R39.2, R40.2, R41.2, R42.2, U16.8 (VCC), VDRIVE.TP; also elsewhere on the board

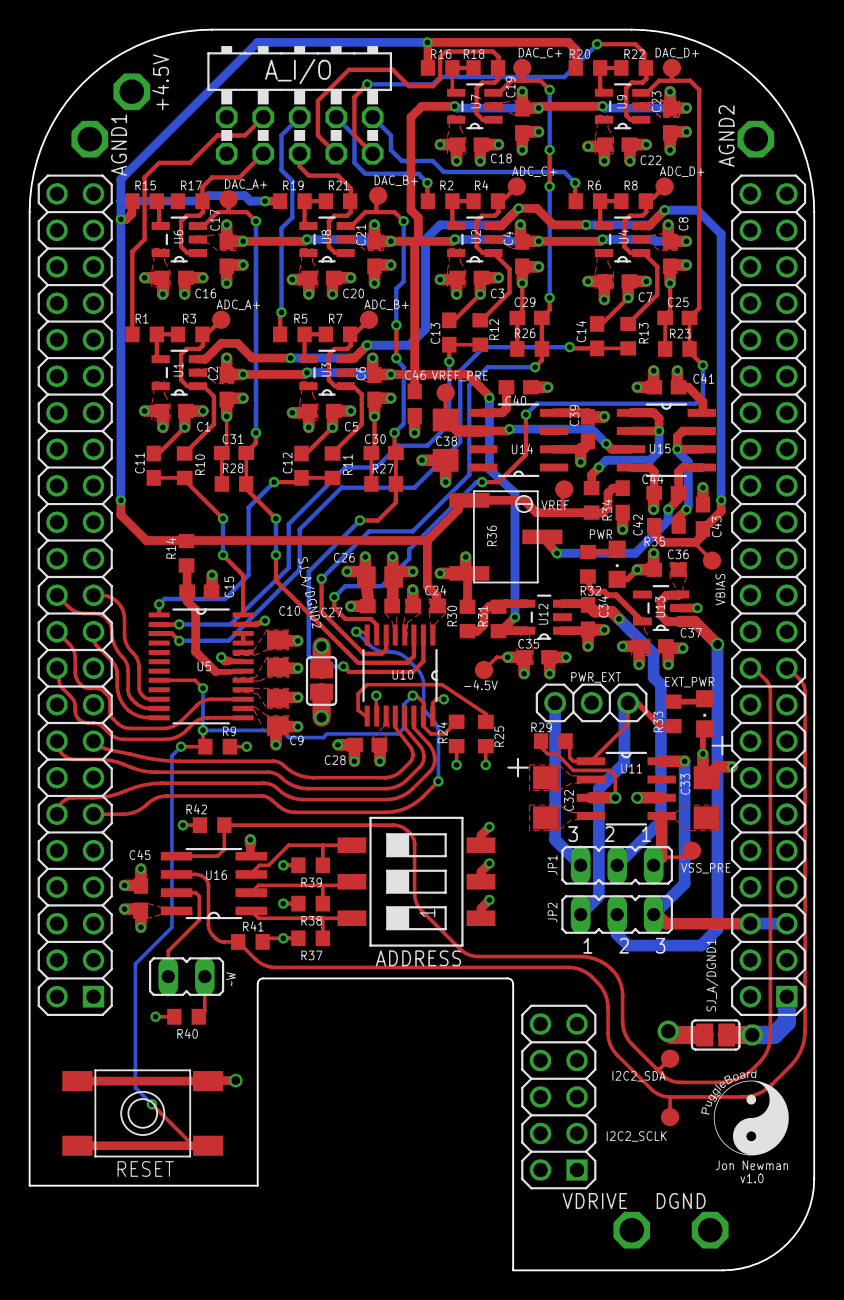
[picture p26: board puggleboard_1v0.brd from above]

Board: 4 copper layers, 54.6 x 86.4 mm, 136 parts (0 on the bottom side), 73 nets.

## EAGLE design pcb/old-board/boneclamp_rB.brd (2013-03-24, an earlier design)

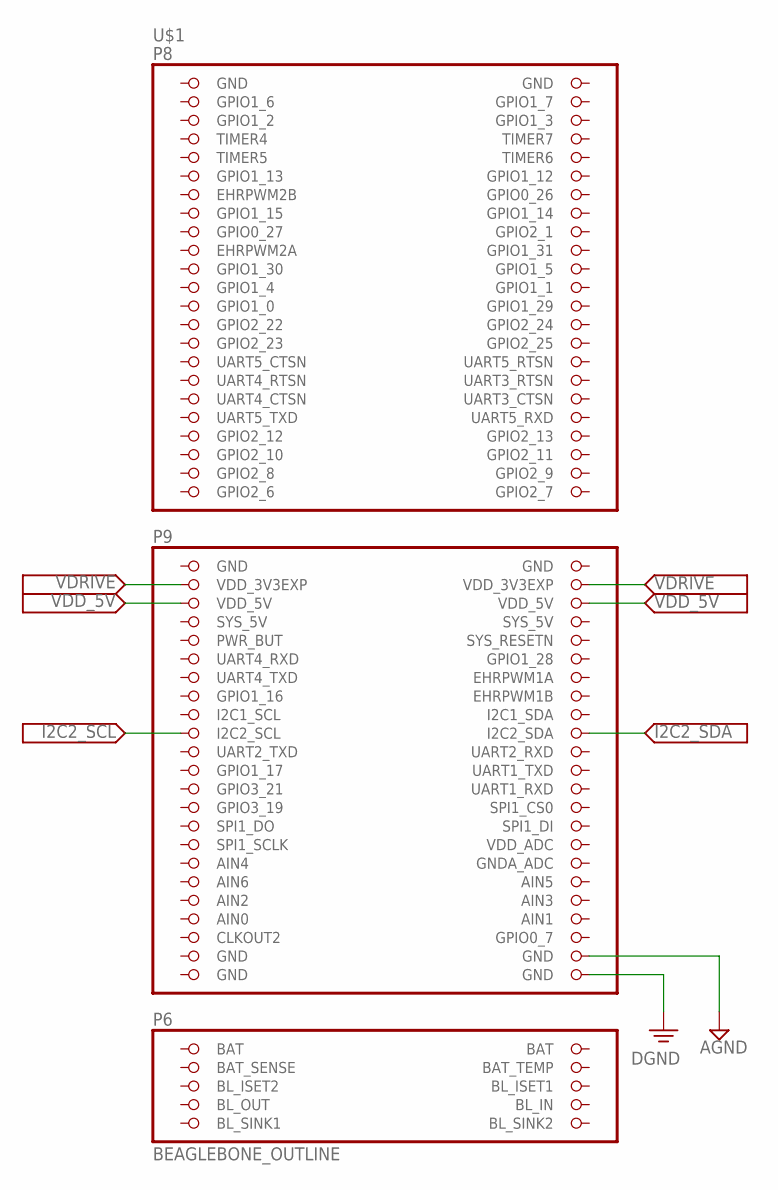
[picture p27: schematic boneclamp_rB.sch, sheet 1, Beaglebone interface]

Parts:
U$1: BEAGLEBONE_OUTLINE; BEAGLEBONE_SHIELD

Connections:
AGND: U$1.90 (GND); also elsewhere on the board
AIN0: U$1.85 (AIN0)
BAT_SENSE: U$1.95 (BAT_SENSE)
BL_IN: U$1.97 (BL_IN)
BL_OUT: U$1.100 (BL_OUT)
BL_SINK1: U$1.101 (BL_SINK1)
BL_SINK2: U$1.102 (BL_SINK2)
DGND: U$1.92 (GND); also elsewhere on the board
GND: U$1.1 (GND), U$1.2 (GND), U$1.47 (GND), U$1.48 (GND), U$1.89 (GND), U$1.91 (GND); also elsewhere on the board
I2C2_SCL: U$1.65 (I2C2_SCL); also elsewhere on the board
I2C2_SDA: U$1.66 (I2C2_SDA); also elsewhere on the board
SYS_5V: U$1.53 (SYS_5V)
VDD_5V: U$1.51 (VDD_5V), U$1.52 (VDD_5V); also elsewhere on the board
VDRIVE: U$1.49 (VDD_3V3EXP), U$1.50 (VDD_3V3EXP); also elsewhere on the board

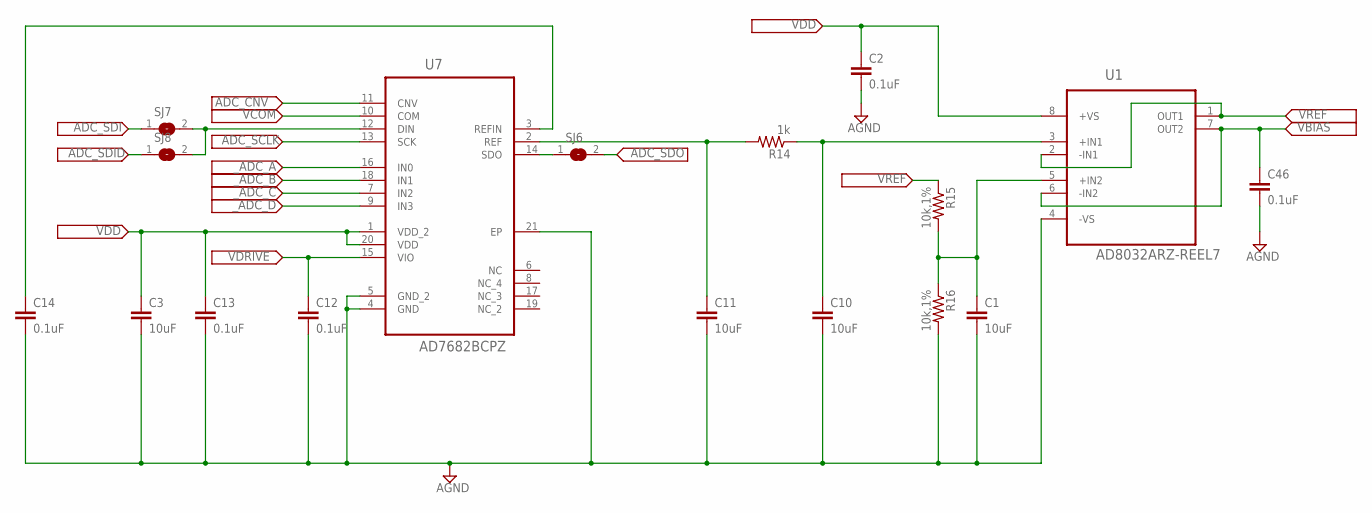
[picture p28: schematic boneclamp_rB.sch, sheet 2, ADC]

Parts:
C1, C3, C10, C11: 10uF; C0805
C2, C12, C13, C14, C46: 0.1uF; C0805
R14: 1k; R0805
R15, R16: 10k,1%; R0805
SJ6, SJ7, SJ8: SJ
U1: AD8032ARZ-REEL7; SOIC127P600X175-8N
U7: AD7682BCPZ; QFN50P400X400X100-21N

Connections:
ADC_CNV: U7.11 (CNV)
ADC_SCLK: U7.13 (SCK)
ADC_SDI: SJ7.1
ADC_SDID: SJ8.1
ADC_SDO: SJ6.2
AGND: C1.2, C2.2, C3.2, C10.2, C11.2, C12.2, C13.2, C14.2, C46.2, R16.2, U1.4 (-VS), U7.4 (GND), U7.5 (GND_2), U7.21 (EP); also elsewhere on the board
unnamed: C1.1, R15.2, R16.1, U1.5 (+IN2)
unnamed: SJ7.2, SJ8.2, U7.12 (DIN)
unnamed: C11.1, R14.2, U7.2 (REF)
unnamed: C10.1, R14.1, U1.3 (+IN1)
unnamed: C14.1, U7.3 (REFIN)
VBIAS: C46.1, U1.6 (-IN2), U1.7 (OUT2); also elsewhere on the board
VCOM: U7.10 (COM)
VDD: C2.1, C3.1, C13.1, U1.8 (+VS), U7.1 (VDD_2), U7.20 (VDD); also elsewhere on the board
VDRIVE: C12.1, U7.15 (VIO); also elsewhere on the board
VREF: R15.1, U1.1 (OUT1), U1.2 (-IN1); also elsewhere on the board
_ADC_A: U7.16 (IN0); also elsewhere on the board
_ADC_B: U7.18 (IN1); also elsewhere on the board
_ADC_C: U7.7 (IN2); also elsewhere on the board
_ADC_D: U7.9 (IN3); also elsewhere on the board

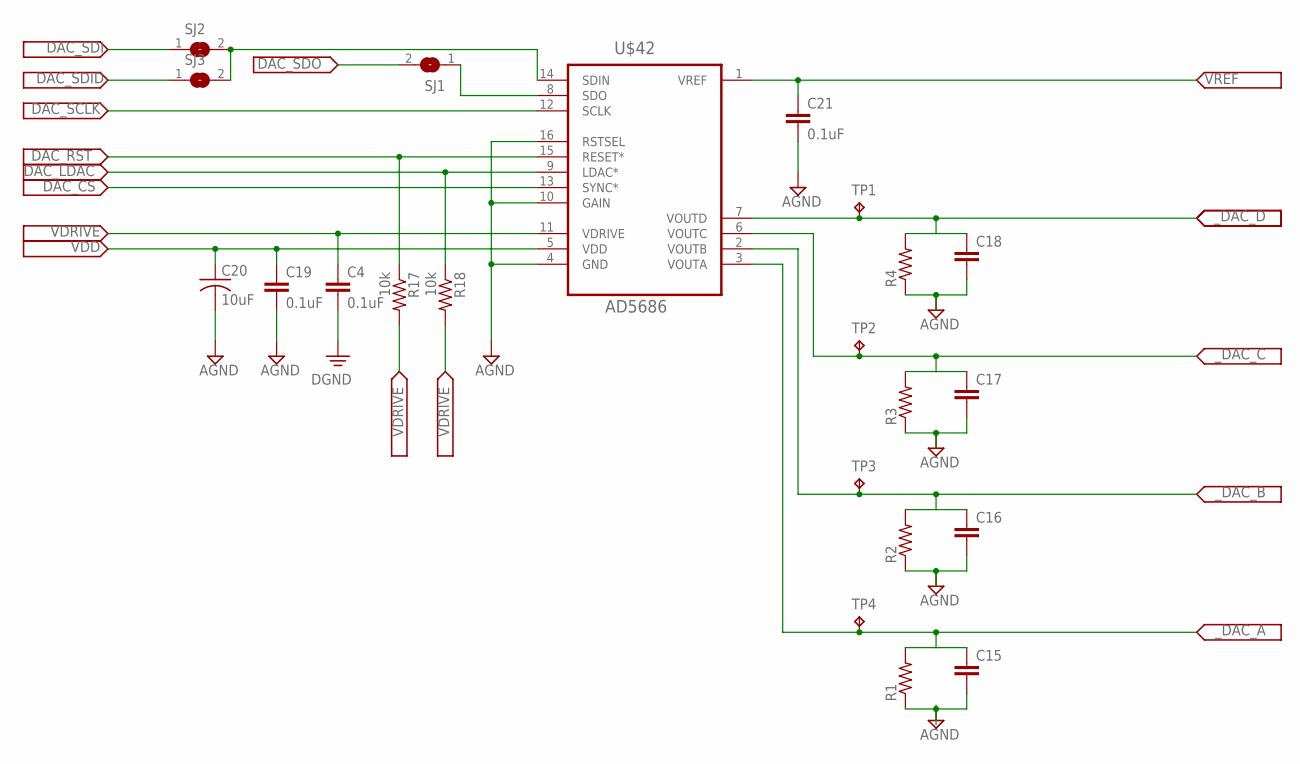
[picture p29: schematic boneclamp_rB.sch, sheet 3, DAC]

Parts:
C4, C19, C21: 0.1uF; C0805
C15, C16, C17, C18: C-EUC0805; C0805
C20: 10uF; C0805
R1, R2, R3, R4: R-US_R0805; R0805
R17, R18: 10k; R0805
SJ1, SJ2, SJ3: SJ
TP1, TP2, TP3, TP4: TPB1,27; B1,27
U$42: AD5686; MO-153-AB

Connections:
AGND: C16.2, C17.2, C18.2, C19.2, C20.2, C21.2, R2.1, R3.1, R4.1, U$42.4 (GND), U$42.10 (GAIN), U$42.16 (RSTSEL); also elsewhere on the board
DAC_CS: U$42.13 (SYNC*)
DAC_LDAC: R18.1, U$42.9 (LDAC*)
DAC_RST: R17.1, U$42.15 (RESET*)
DAC_SCLK: U$42.12 (SCLK)
DAC_SDI: SJ2.1
DAC_SDID: SJ3.1
DAC_SDO: SJ1.2
unnamed: SJ1.1, U$42.8 (SDO)
unnamed: SJ2.2, SJ3.2, U$42.14 (SDIN)
unnamed: C15.2, R1.1
PE: C4.2
VDD: C19.1, C20.1, U$42.5 (VDD); also elsewhere on the board
VDRIVE: C4.1, R17.2, R18.2, U$42.11 (VDRIVE); also elsewhere on the board
VREF: C21.1, U$42.1 (VREF); also elsewhere on the board
_DAC_A: C15.1, R1.2, TP4.TP, U$42.3 (VOUTA); also elsewhere on the board
_DAC_B: C16.1, R2.2, TP3.TP, U$42.2 (VOUTB); also elsewhere on the board
_DAC_C: C17.1, R3.2, TP2.TP, U$42.6 (VOUTC); also elsewhere on the board
_DAC_D: C18.1, R4.2, TP1.TP, U$42.7 (VOUTD); also elsewhere on the board

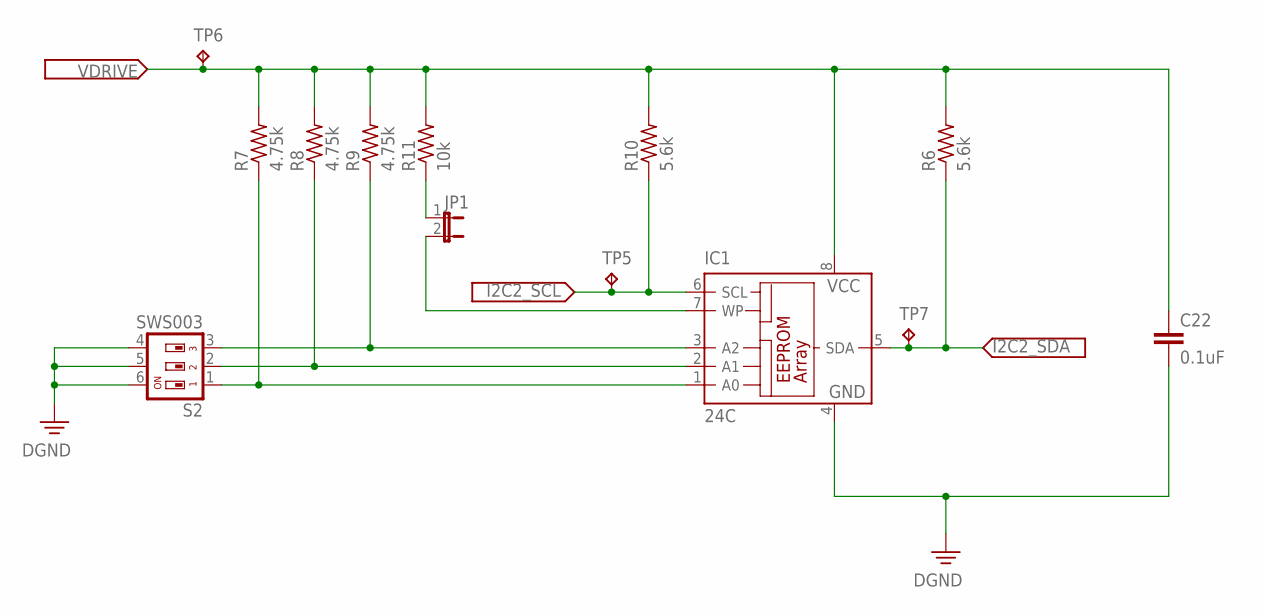
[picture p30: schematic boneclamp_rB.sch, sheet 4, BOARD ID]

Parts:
C22: 0.1uF; C0603
IC1: 24C; SO-08
JP1: JP1E; JP1
R6, R10: 5.6k; R0603
R7, R8, R9: 4.75k; R0603
R11: 10k; R0603
S2: SWS003; SMS-003
TP5, TP6, TP7: TPB1,27; B1,27

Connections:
DGND: C22.2, IC1.4 (GND), S2.4, S2.5, S2.6; also elsewhere on the board
I2C2_SCL: IC1.6 (SCL), R10.1, TP5.TP; also elsewhere on the board
I2C2_SDA: IC1.5 (SDA), R6.1, TP7.TP; also elsewhere on the board
unnamed: IC1.1 (A0), R7.1, S2.1
unnamed: IC1.2 (A1), R8.1, S2.2
unnamed: IC1.3 (A2), R9.1, S2.3
unnamed: IC1.7 (WP), JP1.2
unnamed: JP1.1, R11.1
VDRIVE: C22.1, IC1.8 (VCC), R6.2, R7.2, R8.2, R9.2, R10.2, R11.2, TP6.TP; also elsewhere on the board

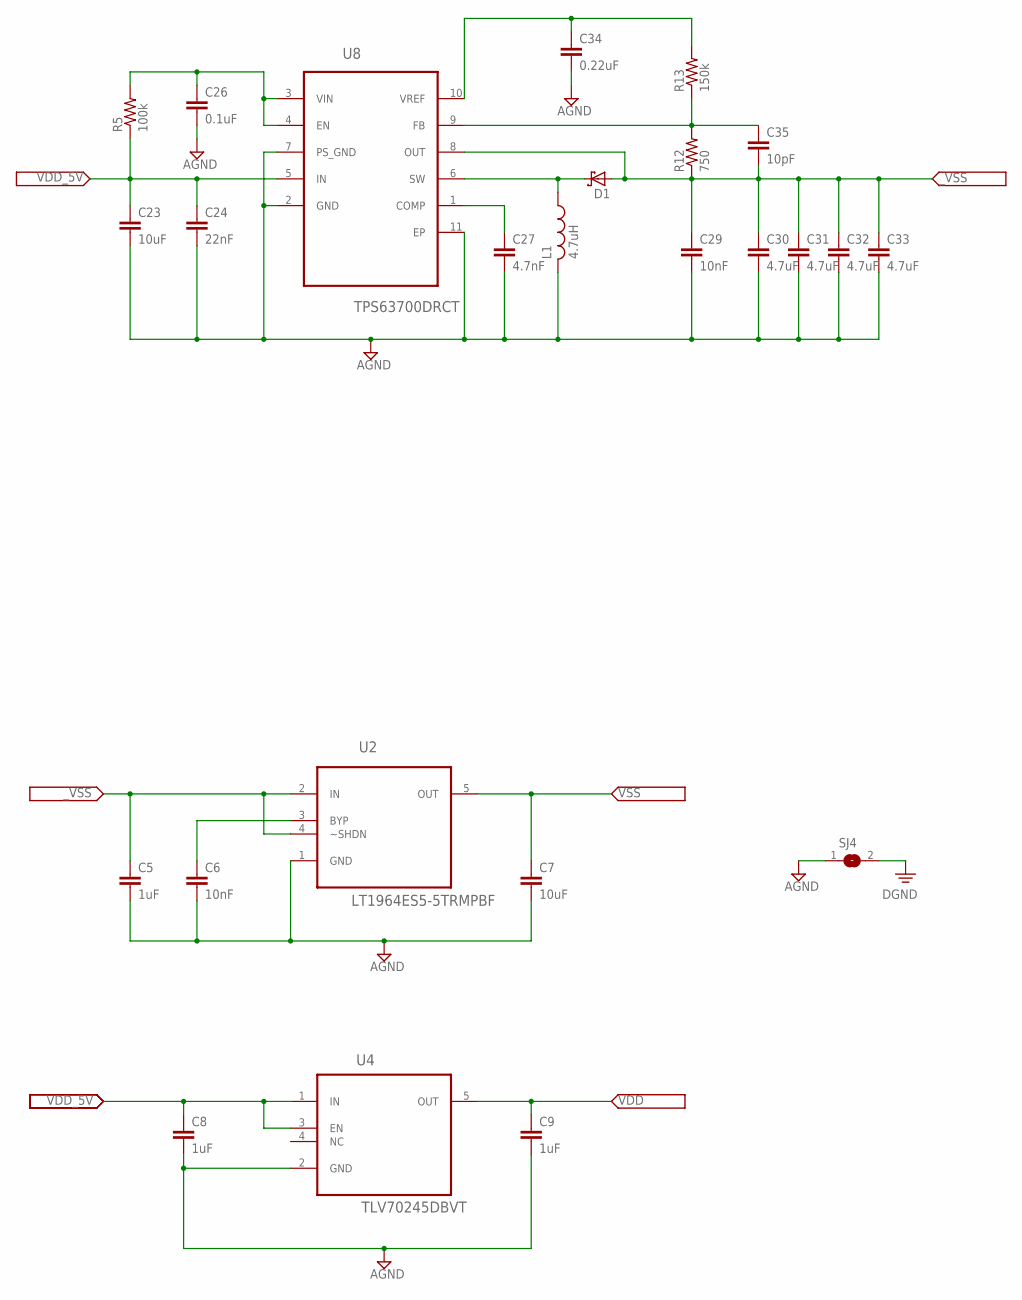
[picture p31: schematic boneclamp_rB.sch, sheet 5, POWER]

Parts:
C5, C8, C9: 1uF; C0603
C6, C29: 10nF; C0603
C7, C23: 10uF; C0603
C24: 22nF; C0603
C26: 0.1uF; C0603
C27: 4.7nF; C0603
C30, C31, C32, C33: 4.7uF; C0603
C34: 0.22uF; C0603
C35: 10pF; C0603
D1: SCHOTTKY-DIODE-2; DO-219AB
L1: 4.7uH; L4012M
R5: 100k; R0603
R12: 750; R0603
R13: 150k; R0603
SJ4: SJ
U2: LT1964ES5-5TRMPBF; SOT95P280X100-5N
U4: TLV70245DBVT; SOT95P280X110-5N
U8: TPS63700DRCT; SON50P300X300X100-11N

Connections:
AGND: C5.2, C6.2, C7.2, C8.2, C9.2, C23.2, C24.2, C26.2, C27.2, C29.2, C30.2, C31.2, C32.2, C33.2, C34.2, L1.2, SJ4.1, U2.1 (GND), U4.2 (GND), U8.2 (GND), U8.7 (PS_GND), U8.11 (EP); also elsewhere on the board
DGND: SJ4.2; also elsewhere on the board
unnamed: C6.1, U2.3 (BYP)
unnamed: C26.1, R5.2, U8.3 (VIN), U8.4 (EN)
unnamed: C27.1, U8.1 (COMP)
unnamed: D1.P$1 (A), L1.1, U8.6 (SW)
unnamed: C35.1, R12.2, R13.1, U8.9 (FB)
unnamed: C34.1, R13.2, U8.10 (VREF)
VDD: C9.1, U4.5 (OUT); also elsewhere on the board
VDD_5V: C8.1, C23.1, C24.1, R5.1, U4.1 (IN), U4.3 (EN), U8.5 (IN); also elsewhere on the board
VSS: C7.1, U2.5 (OUT); also elsewhere on the board
_VSS: C5.1, C29.1, C30.1, C31.1, C32.1, C33.1, C35.2, D1.P$2 (C), R12.1, U2.2 (IN), U2.4 (~SHDN), U8.8 (OUT)

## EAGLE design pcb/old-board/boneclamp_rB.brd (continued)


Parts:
C25, C28, C36, C37, C38, C39: C-EU025-025X050; C025-025X050
C40, C41, C47, C48, C49, C50, C55, C56: 0.1uF; C0805
C42, C43, C51, C52: 2.7nF; C0805
C44, C45, C53, C54: 10uF; C0805
JP5: PINHD-2X5/90; 2X05/90
R19: 6.937k; 0204V
R20, R22: 10k; 0204V
R21: 6.66k; 0204V
R23, R24, R25, R26, R27, R28, R29, R30: R-US_0204/2V; 0204V
R31, R38, R43, R44: 0.1k; R0805
R32, R33, R36, R37: 33; R0603
R34, R35, R45, R46: 590; R0603
R39, R40, R41, R42: 10k; R0805
U3, U5, U9, U10, U11: ADA4841-2YRZ; SOIC127P600X175-8N
U6: AD713JRZ-16; SOIC127P1032X265-16N

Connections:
ADC_A: JP5.4, U9.3 (+IN1), U10.3 (+IN1)
ADC_B: JP5.6, U9.5 (+IN2), U10.5 (+IN2)
ADC_C: JP5.8, U5.3 (+IN1), U11.3 (+IN1)
ADC_COM: JP5.2
ADC_D: JP5.10, U5.5 (+IN2), U11.5 (+IN2)
AGND: C40.2, C41.2, C42.2, C43.2, C44.1, C45.2, C47.2, C48.2, C49.2, C50.2, C51.2, C52.2, C53.1, C54.2, C55.2, C56.2; also elsewhere on the board
DAC_A: JP5.3
DAC_B: JP5.5
DAC_C: JP5.7
DAC_COM: JP5.1
DAC_D: JP5.9
GND: C25.1, C28.1, C36.1, C38.1, C39.1, U6.8 (NC_2), U6.9 (NC); also elsewhere on the board
unnamed: R37.2, R45.1, U5.6 (-IN2), U5.7 (OUT2)
unnamed: R33.2, R34.1, U9.6 (-IN2), U9.7 (OUT2)
unnamed: R26.2, R30.1, U6.14 (+IN)
unnamed: R36.2, R46.1, U5.1 (OUT1), U5.2 (-IN1)
unnamed: R32.2, R35.1, U9.1 (OUT1), U9.2 (-IN1)
unnamed: R25.2, R29.1, U6.12 (+IN_4)
unnamed: C38.2, R21.1, R22.2, U3.5 (+IN2)
unnamed: C28.2, R19.1, R20.2, U3.3 (+IN1)
unnamed: R24.2, R28.1, U6.5 (+IN_3)
unnamed: R23.2, R27.1, U6.3 (+IN_2)
unnamed: C25.2, R20.1
VBIAS: C47.1, C48.1, C55.1, C56.1, R34.2, R35.2, R45.2, R46.2; also elsewhere on the board
VBIAS_DOWN: C39.2, U3.6 (-IN2), U3.7 (OUT2), U6.2 (-IN_3), U6.6 (-IN_4), U6.11 (-IN), U6.15 (-IN_2)
VBIAS_UP: C36.2, R31.2, R38.2, R39.1, R39.2, R40.1, R40.2, R41.1, R41.2, R42.1, R42.2, R43.2, R44.2, U3.1 (OUT1), U3.2 (-IN1), U10.2 (-IN1), U10.6 (-IN2), U11.2 (-IN1), U11.6 (-IN2)
VDD: C40.1, C45.1, C49.1, C54.1, R19.2, U3.8 (+VS), U5.8 (+VS), U6.4 (+VS), U9.8 (+VS), U10.8 (+VS), U11.8 (+VS); also elsewhere on the board
VSS: C41.1, C44.2, C50.1, C53.2, R21.2, U3.4 (-VS), U5.4 (-VS), U6.13 (-VS), U9.4 (-VS), U10.4 (-VS), U11.4 (-VS); also elsewhere on the board
_ADC_A: C42.1, R32.1, R38.1, U10.1 (OUT1); also elsewhere on the board
_ADC_B: C43.1, R31.1, R33.1, U10.7 (OUT2); also elsewhere on the board
_ADC_C: C51.1, R36.1, R43.1, U11.1 (OUT1); also elsewhere on the board
_ADC_D: C52.1, R37.1, R44.1, U11.7 (OUT2); also elsewhere on the board
_DAC_A: R23.1, R30.2, U6.16 (OUT); also elsewhere on the board
_DAC_B: R26.1, R27.2, U6.1 (OUT_2); also elsewhere on the board
_DAC_C: R25.1, R28.2, U6.7 (OUT_3); also elsewhere on the board
_DAC_D: R24.1, R29.2, U6.10 (OUT_4); also elsewhere on the board

Board: 4 copper layers, 136 parts (0 on the bottom side), 59 nets, no tracks yet.

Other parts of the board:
U$77: ADS8343; SOP63P500X150-16N

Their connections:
GND: U$77.10, U$77.11; also elsewhere on the board
VCC: U$77.1, U$77.9

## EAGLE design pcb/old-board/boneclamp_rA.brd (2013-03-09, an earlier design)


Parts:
U3: SN74ABT541BDW; SOIC127P1030X265-20N
U$1: BEAGLEBONE_OUTLINE; BEAGLEBONE_SHIELD

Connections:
AGND: U$1.1 (GND), U$1.2 (GND), U$1.47 (GND), U$1.48 (GND), U$1.89 (GND), U$1.90 (GND), U$1.91 (GND); also elsewhere on the board
AIN0: U$1.85 (AIN0)
BB_5V: U$1.53 (SYS_5V), U$1.54 (SYS_5V); also elsewhere on the board
DGND: U$1.92 (GND); also elsewhere on the board
I2C2_SCL: U$1.65 (I2C2_SCL); also elsewhere on the board
I2C2_SDA: U$1.66 (I2C2_SDA); also elsewhere on the board
VCC: U3.20 (VCC)
VDD_BB: U$1.51 (VDD_5V), U$1.52 (VDD_5V); also elsewhere on the board
VDRIVE: U$1.49 (VDD_3V3EXP), U$1.50 (VDD_3V3EXP); also elsewhere on the board


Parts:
BCIO: F15-SHEILD; HDF15H
C1, C2, C3, C4: 1 uF; C0402
JP1, JP3: JP1E; JP1
JP2: JP2E; JP2
U1: AD7656YSTZ; QFP50P1200X1200X160-64N
U7: AD7682BCPZ; QFN50P400X400X100-21N

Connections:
AGND: BCIO.1, C1.2, C2.2, C3.2, C4.2, JP1.2, U1.32 (AGND), U1.37 (AGND_3), U1.38 (AGND_5), U1.43 (AGND_2), U1.44 (AGND_6), U1.49 (AGND_4), U1.52 (AGND_7), U1.53 (AGND_9), U1.57 (AGND_8), U1.59 (AGND_11); also elsewhere on the board
CONVST: U1.21 (CONVST_C), U1.22 (CONVST_B), U1.23 (CONVST_A)
DAC_A: BCIO.8; also elsewhere on the board
DAC_B: BCIO.9; also elsewhere on the board
DAC_C: BCIO.10; also elsewhere on the board
DAC_D: BCIO.11; also elsewhere on the board
DGND: JP2.3, U1.8 (DGND), U1.25 (DGND_2); also elsewhere on the board
DVCC: U1.26 (DVCC); also elsewhere on the board
unnamed: BCIO.2, U1.33 (V1)
unnamed: BCIO.3, U1.36 (V2)
unnamed: BCIO.4, U1.39 (V3)
unnamed: BCIO.5, U1.42 (V4)
unnamed: BCIO.6, U1.45 (V5)
unnamed: BCIO.7, U1.48 (V6)
unnamed: C2.1, U1.56 (REFCAPB)
unnamed: C1.1, U1.58 (REFCAPC)
unnamed: JP2.2, U1.27 (RANGE)
unnamed: C4.1, U1.34 (AVCC_8), U1.35 (AVCC), U1.40 (AVCC_5), U1.41 (AVCC_7), U1.46 (AVCC_2), U1.47 (AVCC_3), U1.50 (AVCC_6), U1.60 (AVCC_4)
unnamed: JP3.1, U1.51 (REFIN/REFOUT)
SGND: BCIO.P$1, BCIO.P$2, JP1.1
VDD: U1.31 (VDD), U7.20 (VDD); also elsewhere on the board
VDD_2: U7.1 (VDD_2)
VDRIVE: JP2.1; also elsewhere on the board
VIO: U7.15 (VIO)
VREF_2.5V: JP3.2; also elsewhere on the board
VSS: U1.30 (VSS); also elsewhere on the board


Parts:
C15, C16, C17, C18: C-EUC0603; C0603
JP4: JP1E; JP1
R1, R2, R3, R4: R-US_R0603; R0603
SJ1, SJ2, SJ3: SJ
TP1, TP2, TP3, TP4: TPB1,27; B1,27
U2: AD5754RBREZ; SOP65P640X120-25N
U$42: AD5686RARUZ; MO-153-AB

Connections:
AGND: C16.2, C17.2, C18.2, R2.1, R3.1, R4.1; also elsewhere on the board
DAC_A: C18.1, R4.2, TP1.TP, U2.3 (VOUTA); also elsewhere on the board
DAC_B: C17.1, R3.2, TP2.TP, U2.4 (VOUTB); also elsewhere on the board
DAC_C: C16.1, R2.2, TP3.TP, U2.23 (VOUTC); also elsewhere on the board
DAC_D: C15.1, R1.2, TP4.TP, U2.22 (VOUTD); also elsewhere on the board
DVCC: U2.14 (DVCC); also elsewhere on the board
EPAD: U2.25 (EPAD)
unnamed: SJ1.1, U2.16 (SDO)
unnamed: SJ2.2, SJ3.2, U2.9 (SDIN)
unnamed: C15.2, R1.1
unnamed: JP4.1, U2.17 (REFIN/REFOUT)
SDIN_BB: SJ2.1
SDIN_DC: SJ3.1
SDO_DC: SJ1.2
VDD: U2.24 (AVDD), U$42.5 (VDD); also elsewhere on the board
VREF_2.5V: JP4.2; also elsewhere on the board
VSS: U2.1 (AVSS); also elsewhere on the board


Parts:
C22: 0.1uF; C0603
IC1: 24C; SO-08
R6, R10: 5.6k; R0603
R7, R8, R9: 4.75k; R0603
R11: 10k; R0603
S1: SWS002; SMS-002
SJ5: SJ

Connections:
DGND: C22.2, IC1.4 (GND), S1.3, S1.4; also elsewhere on the board
I2C2_SCL: IC1.6 (SCL), R10.1; also elsewhere on the board
I2C2_SDA: IC1.5 (SDA), R6.1; also elsewhere on the board
unnamed: IC1.1 (A0), R7.1, R8.1, S1.1
unnamed: IC1.2 (A1), S1.2
unnamed: IC1.3 (A2), R9.1
unnamed: IC1.7 (WP), SJ5.1
unnamed: R11.1, SJ5.2
VDRIVE: C22.1, IC1.8 (VCC), R6.2, R7.2, R8.2, R9.2, R10.2, R11.2; also elsewhere on the board


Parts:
C5, C8, C10, C13, C19, C20: 10uF; C1206
C6, C7, C9, C11, C12, C14: 0.1uF; C0603
SJ4: SJ
U4, U5: ADP3303ARZ-5; SOIC127P600X175-8N
U$26: LM1085; TO263-3
U$28: SCREW3

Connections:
+12V: C19.1, U$26.3 (IN)
-12V: U$28.P$3
AGND: C5.2, C6.2, C9.2, C10.2, SJ4.1, U4.4 (GND), U5.4 (GND); also elsewhere on the board
AVCC: C7.1, C9.1, C10.1, U4.1 (OUT_2), U4.2 (OUT)
BB_5V: C5.1, C6.1, C8.1, C11.1, U4.5 (~SD), U4.7 (IN), U4.8 (IN_2), U5.5 (~SD), U5.7 (IN), U5.8 (IN_2); also elsewhere on the board
DGND: C8.2, C11.2, C13.2, C14.2, C19.2, C20.2, SJ4.2, U$26.1 (ADJ); also elsewhere on the board
DVCC: C12.1, C13.1, C14.1, U5.1 (OUT_2), U5.2 (OUT); also elsewhere on the board
unnamed: C12.2, U5.3 (NR)
unnamed: C7.2, U4.3 (NR)
PGND: U$28.P$2
VDD_BB: C20.1, U$26.2 (OUT), U$26.TAB (OUT); also elsewhere on the board


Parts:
C23: 10uF; C1206
C24, C26, C27: 0.1uF; C0603
JP5: JP2E; JP2
JP6: JP1E; JP1
TP5: TPB1,27; B1,27
U6: ADR431BRZ; SOIC127P600X175-8N

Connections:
AGND: C23.2, C24.2, C26.2, U6.4 (GND); also elsewhere on the board
unnamed: C26.1, U6.1 (TP_2)
VDD: C23.1, C24.1, U6.2 (VIN); also elsewhere on the board
VREF_2.5V: JP5.2; also elsewhere on the board
VREF_OUT: C27.1, JP5.3, JP6.2, TP5.TP, U6.6 (VOUT)

Board: 4 copper layers, 65 parts (0 on the bottom side), 43 nets, no tracks yet.

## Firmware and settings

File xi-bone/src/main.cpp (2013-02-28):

/*
 Copyright (C) 2011 Georgia Institute of Technology, University of Utah, Weill Cornell Medical College

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
 */

#include <iostream>

#include <cstdlib>
#include <dirent.h>
#include <errno.h>
#include <getopt.h>
#include <signal.h>
#include <string>
#include <unistd.h>

#include <qapplication.h>

#include <cmdline.h>
#include <ctype.h>
#include <daq.h>
#include <debug.h>
#include <main_window.h>
#include <plugin.h>

static pid_t parentThread;

struct cli_options_t {
    std::string config_file;
    std::string plugins_path;
};

static bool parse_cli_options(int,char *[],cli_options_t *);
static void signal_handler(int);

int main(int argc,char *argv[]) {
    int retval = 0;

    /* Try to Exit Cleanly on Signals */
    parentThread = getpid();
    signal(SIGINT,signal_handler);
    signal(SIGABRT,signal_handler);
    signal(SIGSEGV,signal_handler);

    /* Handle Command-Line Options */
    cli_options_t cli_options;
    if(!parse_cli_options(argc,argv,&cli_options))
        return -EINVAL;

    /* Find Configuration File */
    std::string config_file;
    if(cli_options.config_file.length())
        config_file = cli_options.config_file;
    else if(getenv("RTXI_CONF"))
        config_file = getenv("RTXI_CONF");
    else
        config_file = "/etc/rtxi.conf";

    /************************************************************
     * Create Main System Components                            *
     *                                                          *
     *  These need to be created early because they should have *
     *  Settings::IDs of 0 and 1.                               *
     ************************************************************/


    /* Create GUI Objects */
    QApplication *app = new QApplication(argc,argv);
    app->connect(app,SIGNAL(lastWindowClosed()),app,SLOT(quit()));
    MainWindow::getInstance()->showMaximized();

    CmdLine::getInstance();

    RT::System::getInstance();
    IO::Connector::getInstance();

    /* Bootstrap the System */
    Settings::Manager::getInstance()->load(config_file);

    retval = app->exec();

    Plugin::Manager::getInstance()->unloadAll();
    return retval;
}

static void error_msg(const std::string &self) {
    std::cout << "Try \'" << self << " --help\' for more information.\n";
}

static void help_msg(const std::string &self) {
    std::cout << "Usage: " << self << " [options]\n";
    std::cout << "  where options include:\n";
    std::cout << "    --help,         -h  - Displays this message\n";
    std::cout << "    --config-file,  -c  - Pick a custom configuration file\n";
    std::cout << "    --plugins-path, -p  - Specify a plugins directory\n";
}

static bool parse_cli_options(int argc,char *argv[],cli_options_t *cli_options) {
    int opt, index;

    struct option options[] = {
        { "help",        no_argument,       0, 'h' },
        { "config-file", required_argument, 0, 'c' },
        { "plugins-path", required_argument, 0, 'p' },
        { "models-path",  required_argument, 0, 'm' },
        { 0,0,0,0 }
    };

    for(;;) {
        opt = getopt_long(argc,argv,"hc:p:m:",options,&index);

        if(opt < 0) break;

        switch(opt) {
          case 'c':
              cli_options->config_file = optarg;
              break;
          case 'h':
              help_msg(argv[0]);
              return false;
          case 'p':
              cli_options->plugins_path = optarg;
              break;
          default:
              error_msg(argv[0]);
              return false;
        }
    }

    return true;
}

static void signal_handler(int signum) {
    static int count = 0;

    /* Only handler handle signals in the parent */
    if(getpid() != parentThread) return;

    DEBUG_MSG("signal_handler : signal received\n");
#ifdef DEBUG
    PRINT_BACKTRACE();
#endif // DEBUG

    if(count++) _exit(-EFAULT);

    DEBUG_MSG("signal_handler : finished\n");
    exit(0);
}

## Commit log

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2013-02-16 Added data-sheets for ICs on the board. Also, I started an EAGLE schematic that contains the parts we know will be on the board: the expansion headers along with their correct layout, the ADC, the DA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
    [boneclamp.sch]
2013-02-18 Updated schematic with the TRS jacks that we will use. They are mono which makes conversion to BNC or other formats easy. Also, I added a .gitignore to the main BoneClamp folder so that we can avoid 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
    [boneclamp.sch]
2013-02-24 Updated the adafruit libary to include the d-sub connector we will be using. Updated .gitignore to ingore libary backups. Started a power supply sheet on the eagle schematic.
    [boneclamp.brd, boneclamp.sch]
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2013-02-24 Renamed the pcb folder to be more in line with other directory names
    [boneclamp.brd, boneclamp.sch]
2013-02-24 Started working through the basic wiring on the schematic, connectrating on grounds, power, and analog IO
    [boneclamp.brd, boneclamp.sch]
2013-02-25 Added optional compensation comoponents and test points to DAC output lines. Added a right angle 0.1 inch pitch header for outside power input.
    [boneclamp.brd, boneclamp.sch]
2013-02-25 Added pictures of the effective jitter, as seen on an oscope, while running the pw_gpio_sin example
2013-02-27 I put an anti-aliasing filter design tool, provided by TI, into the PCB folder. The stop frequency (the frequency at which the attenuation is equal to the noise floor of the ADC (NOT the -3 dB point)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
    [anti-aliasing-design-tool.xls]
2013-03-03 Found a good regulator for powering the BB using the +/- 6 to 12 volt rails required to use the boneclamp. Updated schematic and added data sheet to data-sheets folder
    [anti-aliasing-design-tool.xls, boneclamp.brd, boneclamp.sch]
2013-03-03 Started and examples folder containing information about good capes produced by other people
    [BeagleBone-Battery-RevA-allegro.brd, BeagleBone-Battery-RevA-bom.xls, BeagleBone-Battery-RevA-schematic.dsn]
2013-03-03 Added EEPROM to the I2C2bus to follow standard daughter board device ID requirements
    [boneclamp.brd, boneclamp.sch]
2013-03-03 Added external 2.5 volt references for DAC and ADC. This circuit needs a buffer option which can be feed into the 3 position jumper.
    [boneclamp.brd, boneclamp.sch]
2013-03-09 Added new data sheets. Started a second pcb layout for new DAC/ADC unipolar solutions.
    [boneclamp.brd, boneclamp.sch, boneclamp_rB.brd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]
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2013-03-11 Added data sheets for the smd-to-dip adapters we will use. Minor changes to schematic
    [boneclamp_rB.brd, boneclamp_rB.sch]
2013-03-12 Finished power supply circuits on schematic. Updated BOM and added new data sheets.
    [boneclamp_rB.brd, boneclamp_rB.sch]
2013-03-13 Updated adafruit library with 2X5 0.1 inch pitch header, which we will use for I/O on the BC. Added that to the schematic
    [boneclamp_rB.brd, boneclamp_rB.sch]
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2013-03-14 Added buffered VREF divider, which feeds back into ADC to get bipolar input swing.
    [boneclamp_rB.brd, boneclamp_rB.sch]
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2013-03-14 This can now actually be built (tested only on x86_64 using arm-none-linux-gnueabi-gcc). Makefile now automatically decides if cross compilation necessary (to avoid typing ' CROSS_COMPILE = ' every t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
2013-03-15 Minor fixed to EEPROM circuit and ADC VREF buffer. Stephano, don't kill me.
    [boneclamp_rB.brd, boneclamp_rB.sch]
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2013-03-17 Added another example cape, this one has the exact dimensions we are interested in and is well documented.
    [BeagleBone-Audio-RevA-bom.xls, BeagleBone-Audio-RevA-schematic.dsn, BeagleBone_Battery_Rev A_art_param.txt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]
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2013-03-18 Fixed the BB Daughter board layout to include power management header (p6) and extended board area
2013-03-18 Added p6 to the schematic of the BB, update the BC shematic and board
    [boneclamp_rB.brd, boneclamp_rB.sch]
2013-03-19 Added Ground and power plane to pcb. Power plane will need to be split into primarly VDD and then a bit at the front of the board for VSS. VDD and VSS planes should not overlap in the Z direction.
    [boneclamp_rB.brd, boneclamp_rB.sch]
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2013-03-23 Added Stefano's biasing circuitry back into the master branch schematic. Automatic merge was not going to work properly
    [boneclamp_rB.brd, boneclamp_rB.sch]
2013-03-23 Fixed the input biasing scheme. The op-amps we are using require -0.25 to 5.2 volt supply range to push the inputs into the 0 to 4.096 range required by the ADC. This means that our positive rail is 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
    [boneclamp_rB.brd, boneclamp_rB.sch]
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2013-03-24 I found a potentially better option for the ADC. It is a 100KSPS Serial sampling device from TI. It accepts true bipolar signals of +-VREF using a single supply. It also has as a more resonable SMD p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
    [boneclamp_rB.brd, boneclamp_rB.sch]
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2013-03-25 Added yet another option to explore for the ADC. I need to make some calls to find out what the best option is. There is always something wrong with any particular choice.
    [boneclamp_rC.brd, boneclamp_rC.sch]
2013-03-26 Added the 8331 to schematic. I'm pretty sure this is the right ADC.
    [boneclamp_rB.sch, boneclamp_rC.brd, boneclamp_rC.sch]
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2013-03-29 Minor fixes to voltage bias followers
    [boneclamp_rC.brd, boneclamp_rC.sch]
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2013-04-01 Finished basics of input stage to new 8331 and some of the digital interface for it.
    [boneclamp_rC.brd, boneclamp_rC.sch]
2013-04-01 Added the switched capacitor voltage inveter, which greatly simiplifies the power supply design.
    [boneclamp_rC.brd, boneclamp_rC.sch]
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2013-04-04 Fixed DAC output bias
    Biased DAC output, other minor schematic changes
    [boneclamp_rC.brd, boneclamp_rC.sch]
2013-04-06 Tagged v0.1 as the last version to contain an effort to implement daisy chaining. This can serve as point of reference if we want to revisit that in the future.
    [boneclamp_rC.brd, boneclamp_rC.sch]
2013-04-06 Cleaned up schematic to get it ready for actual component selection (passive commoponent packages) and final wiring.
    [boneclamp_rC.brd, boneclamp_rC.sch]
2013-04-06 Added data sheet for the MAX1735, which is a good choice for our negative rail. I calculated the basic power requirements for the chips we are using and this should be good except with the DAC outs a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
2013-04-06 Replaced negative LDO with the MAX1735.
    [boneclamp_rC.brd, boneclamp_rC.sch]
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2013-04-07 Nearly finished with full circuit.I need the GPIO pins that we will be using.
    [boneclamp_rC.brd, boneclamp_rC.sch]
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2013-04-19 Took care of most of Amanda's comments. Started using data buses instead of individual nets for the SPI interfaces.
    [boneclamp_rC.brd, boneclamp_rC.sch]
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2013-04-20 Started getting rid of signal tag symbols, take too much room and cause problems with automatic component renumbering.
    [boneclamp_rC.brd, boneclamp_rC.sch]
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2013-04-20 Minor fix.
    [boneclamp_rC.brd, boneclamp_rC.sch]
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2013-04-21 Routed VDRIVE out from bbehind switching supply using power plane. Following regulation +/-4.5v will dive into power plane and occupy it with VDRIVE. SPI signals should originate from p8 if at all po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
    [boneclamp_rC.brd, boneclamp_rC.sch]
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2013-05-03 Analog buffering stage is pretty much finished. Next will be the regulated power circuitry, then comes the mixed signal ICs.
    [boneclamp_rC.brd, boneclamp_rC.sch]
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2013-05-04 Fixed the ground planes.
    [boneclamp_rC.brd, boneclamp_rC.sch]
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2013-05-11 Finished first intetation of routing! Need to clean up the silkscreen, check for single ended wires, double check schematic wiring, run DRC, and send it to fab.
    [boneclamp_rC.brd, boneclamp_rC.sch]
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2013-05-12 Fixed some random problems with the silkscreen.
    [boneclamp_rC.brd, boneclamp_rC.sch]
2013-05-12 More minor silkscreen issues. Started drawing logo.
    [boneclamp_rC.brd]
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

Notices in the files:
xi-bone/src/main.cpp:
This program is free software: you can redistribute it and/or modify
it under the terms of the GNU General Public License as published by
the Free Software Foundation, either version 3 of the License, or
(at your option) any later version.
